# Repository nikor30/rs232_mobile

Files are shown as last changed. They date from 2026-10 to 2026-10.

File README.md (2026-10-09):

# RS232-WLAN-Konsole

Mobiler serieller Konsolenserver auf ESP32-Basis: mit dem WLAN-Hotspot des Geräts verbinden, `http://192.168.4.1` öffnen, Terminal auf Switch, Router oder Firewall. Keine App, kein Treiber, kein USB-Seriell-Adapter.

Firmware-Stand: **v1.8.0**

- [`HANDOVER.md`](HANDOVER.md) — Projektstand, Erfahrungswissen, offene Punkte
- [`firmware/`](firmware/) — PlatformIO-Projekt für das Waveshare ESP32-S3-Touch-LCD-2 ([Weboberfläche und Netz](firmware/README.md), [Board](firmware/WAVESHARE.md))
- [`server/`](server/) — Leitstelle (Command-and-Control-Server): [Konzept](server/KONZEPT.md), Phase 1 lokal im Docker-Container
- [`tests/`](tests/) — Host-Unittests

```bash
cd firmware
pio run -t upload    # waveshare-s3-lcd2
```

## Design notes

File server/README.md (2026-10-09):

# Leitstelle (Command-and-Control-Server)

Server, bei dem sich die RS232-Konsolen anmelden und Aufträge abholen. Idee, Protokoll, Phasen und Grenzen: **[KONZEPT.md](KONZEPT.md)**. Stand: Phase 1 (Server, Gerätesimulator) und Phase 2 (Client in der Firmware), geprüft im Container und mit dem Waveshare-Board im lokalen Netz.

**Nicht ins Internet stellen.** Dafür fehlt Phase 5 (KONZEPT.md §6); die Compose-Datei bindet den Port deshalb nur an `127.0.0.1`, solange `C2_BIND` nichts anderes sagt.

## Starten

```bash
cd server
echo "C2_ADMIN_TOKEN=$(head -c 24 /dev/urandom | base64)" > .env
docker compose up -d --build        # erster Bau auf dem Raspberry Pi: rund 10 Minuten
curl -k https://127.0.0.1:8443/healthz
```

Der Container enthält nur die beiden Programme (`/c2server`, `/devsim`), läuft ohne Root und mit schreibgeschütztem Dateisystem; der Zustand liegt im Volume `c2data`.

## Ein simuliertes Gerät anmelden

```bash
. ./.env; A="Authorization: Bearer $C2_ADMIN_TOKEN"; S=https://127.0.0.1:8443
sim() { docker run --rm --network server_default -v c2dev:/data --entrypoint /devsim rs232-c2 \
          -state /data/device.json -tls-skip-verify "$@"; }

# 1. einladen
curl -sk -X POST $S/admin/v1/enroll-tokens -H "$A" -d '{"ttl_s":600}'     # -> {"token":"c2e1:...",...}
# 2. das Gerät meldet sich an und zeigt seinen Code
sim enroll -name Labor-1 'c2e1:...'                                        # -> ID ... / CODE 123456
# 3. den Code vom Gerät am Server eintippen
curl -sk -X POST $S/admin/v1/devices/<ID>/approve -H "$A" -d '{"sas":"123456"}'
# 4. Auftrag einreihen, Gerät holt ihn ab, Ergebnis ansehen
curl -sk -X POST $S/admin/v1/devices/<ID>/commands -H "$A" -d '{"type":"ping"}'
sim run -n 1
curl -sk $S/admin/v1/devices/<ID>/commands -H "$A"
```

`-tls-skip-verify` gilt dem selbstsignierten Zertifikat des lokalen Servers. Der innere Kanal hängt davon nicht ab: Der Server muss weiterhin den Schlüssel beweisen, dessen Fingerabdruck im Token steht.

## Ein echtes Gerät anmelden

Das Gerät muss den Server erreichen, also an die LAN-Adresse dieses Rechners binden und sie als öffentliche Adresse nennen (in `.env` oder davor):

```bash
C2_BIND=192.168.10.232 C2_PUBLIC_URL=https://192.168.10.232:8443 docker compose up -d
```

Dann wie oben einladen. Das Token kommt in die Weboberfläche des Geräts (Menü → Netz → Leitstelle → Anmelden) oder per `curl -X POST http://<gerät>/api/c2/enroll -d '{"token":"c2e1:..."}'`; der WLAN-Client des Geräts muss verbunden sein. Der Code steht danach auf dem Display (Seite Info) und in der Weboberfläche. Details: `firmware/README.md`.

## Admin-Schnittstelle

Alle Aufrufe mit `Authorization: Bearer <C2_ADMIN_TOKEN>`.

| Aufruf | Wirkung |
|---|---|
| `POST /admin/v1/enroll-tokens` `{"ttl_s":600,"note":""}` | Einladungs-Token, einmal verwendbar |
| `GET /admin/v1/devices` | Geräte mit Zustand (`pending`, `active`, `revoked`), zuletzt gesehen, letzter Status |
| `POST /admin/v1/devices/{id}/approve` `{"sas":"123456"}` | bestätigen mit dem Code vom Gerätedisplay; fünf falsche Eingaben verwerfen die Anmeldung |
| `POST /admin/v1/devices/{id}/revoke` | sperren, sofort und endgültig |
| `POST /admin/v1/devices/{id}/commands` `{"type":"ping","args":{}}` | Auftrag einreihen (Arten: `ping`, `status`) |
| `GET /admin/v1/devices/{id}/commands` | Aufträge mit Zustand und Ergebnis |

## Einstellungen (Umgebung)

| Variable | Vorgabe | Bedeutung |
|---|---|---|
| `C2_ADMIN_TOKEN` | — (Pflicht, mindestens 16 Zeichen) | Token der Admin-Schnittstelle |
| `C2_PUBLIC_URL` | `https://c2server:8443` (Compose) | Adresse, unter der Geräte den Server erreichen; steht im Einladungs-Token |
| `C2_TLS` | `selfsigned` | `selfsigned`, `files` (`C2_TLS_CERT`, `C2_TLS_KEY`) oder `off` (hinter einem Proxy, der TLS beendet) |
| `C2_TLS_HOSTS` | `localhost,127.0.0.1,c2server` | Namen im selbstsignierten Zertifikat |
| `C2_LISTEN` | `:8443` | Adresse und Port im Container |
| `C2_BIND` | `127.0.0.1` | nur Compose: Adresse dieses Rechners, an die der Port gebunden wird |
| `C2_DATA_DIR` | `/data` | Zustand: `state.json` (enthält den privaten Serverschlüssel), TLS-Zertifikat |
| `C2_POLL_S` | `30` | Abstand, in dem Geräte sich melden sollen |

Wer das Datenverzeichnis verliert, verliert den Serverschlüssel — alle Geräte müssten neu angemeldet werden.

## Tests

```bash
./test/e2e.sh                       # alles: Unit-Tests, Image, Ende-zu-Ende im Container
../tests/c2/run.sh                  # der Protokollcode der Firmware auf dem PC gegen diesen Server
docker build --target test .        # nur Formatierung, go vet und Unit-Tests
```

Go muss nicht installiert sein; gebaut und getestet wird im Container.

## Aufbau

```
cmd/c2server/        der Server
cmd/devsim/          Gerätesimulator
internal/proto/      Protokoll: Handshake, Nachrichten, Einladungs-Token  ← Vorlage für die Firmware
internal/device/     Geräteseite über HTTP (Simulator, Tests)
internal/server/     HTTP: Geräte-Endpunkte und Admin-Schnittstelle
internal/store/      Zustand (JSON-Datei)
test/e2e.sh          Ende-zu-Ende-Test gegen den Container
```

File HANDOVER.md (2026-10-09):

# RS232-WLAN-Konsole — Projektstand und Übergabe

**Stand:** 9. Oktober 2026 · Firmware **v1.8.0** · Autor der Arbeiten: Claude, im Auftrag von Niko

Dieses Dokument ist so geschrieben, dass man das Projekt allein damit und mit dem Archiv-Inhalt fortsetzen kann — ohne den Chatverlauf. Es nennt ausdrücklich auch, **was nicht verifiziert ist**.

---

## 1. Worum es geht

Ein mobiles Gerät für seriellen Konsolenzugang: Du verbindest Handy oder Notebook mit dem WLAN-Hotspot des Geräts, öffnest `http://192.168.4.1` und hast ein Terminal (xterm.js) auf dem angeschlossenen Switch, Router oder der Firewall. Keine App, kein Treiber, kein USB-Seriell-Adapter. Bis zu vier serielle Ports gleichzeitig, dazu Raw-TCP/Telnet, Dateiübertragung per XMODEM/YMODEM, abspielbare Konfigurationen, 802.1X fürs Firmennetz und HTTPS.

## 2. Die Hardware

Seit dem 9. Oktober 2026 baut die Firmware nur noch für das **Waveshare ESP32-S3-Touch-LCD-2** (ESP32-S3R8, 2″-Touch-LCD 240×320, SD, LiPo-Anschluss; PlatformIO-Env `waveshare-s3-lcd2`, Arduino-Core 2.0.17). Stand, Pins und offene Punkte: `firmware/WAVESHARE.md`.

Entfernt wurden die drei früheren Varianten samt ihrem Code: **ESP32 DevKit + MAX3232 (HW-044)** mit OLED (das erste Mockup), **LilyGO T-RSS3** und das **VIEWE-5″-Panel** (LVGL-GUI, Core 3.1.1) — dazu OLED-Treiber (U8g2), Status-LED, die fertigen Images, `MOCKUP.md`, `PANEL.md` und das T-RSS3-Gehäuse. Ebenfalls entfernt sind `hardware/` (KiCad-Projekt der I²C-Tochterplatine, Gehäuse fürs LCDwiki-Basisboard) und `diagramme/` (PowerBoost-Schaltpläne, DB9-Nullmodem); deren letzter Stand ist Commit `43e7939`. Der letzte Stand mit allen Varianten ist Commit `3bbc16c`. Wo die Abschnitte unten von diesen Boards handeln, sind sie als Erfahrungswissen stehen geblieben.

## 3. Was läuft, was nicht

**Am echten Gerät erprobt (am früheren DevKit-Mockup; Waveshare: siehe `firmware/WAVESHARE.md`):**
- Web-Terminal, Mehrfach-Clients, Reconnect mit Replay
- Konsolenzugriff auf einen echten Cisco-Switch
- Raw-TCP auf Port 2000 aus dem LAN, mit PuTTY
- OLED 128×64 inkl. Helligkeitsregelung
- PowerBoost 1000C mit LiPo lädt und versorgt

**Nie gegen die Wirklichkeit geprüft:**
- **802.1X EAP-TLS gegen einen echten RADIUS**, PKCS#12-Upload am Gerät.

Mit den alten Boards entfernt, weil nie gelaufen: die **Core-3-/mbedTLS-3-Pfade** (`compat_eap.h`, `compat_mbedtls.h`) und die **LBO-Auswertung** (Akkuwarnleitung fürs DevKit mit PowerBoost). Die Firmware ruft jetzt direkt die APIs von Arduino-Core 2.0.17 / mbedTLS 2 auf; ein Umstieg auf Core 3 braucht die Anpassungen aus Commit `c4b24bb` wieder.

**Nicht gebaut:** die I²C-Tochterplatine. Schaltplan und Layout liegen nur noch in der Git-Historie (Commit `43e7939`), bestellt war nichts.

## 4. Was im Archiv liegt

```
firmware/            das PlatformIO-Projekt
  src/               C++-Quellen
  web/               Weboberfläche (wird gzip-komprimiert ins Image eingebettet)
  tools/             embed_web.py, lcd_debug.py (Debug-Konsole), mock_device.js
  README.md          Weboberfläche, Netz, 802.1X/HTTPS, XMODEM, Konfigurationen, Diagnose
  WAVESHARE.md       das Board: Touch-Oberfläche, Bluetooth, Pins, Akku  ← die meistgebrauchte Datei
tests/               Host-Unittests (laufen auf dem PC, nicht auf dem ESP32)
HANDOVER.md          dieses Dokument
```

## 5. Firmware: wo was steckt

| Datei | Aufgabe |
|---|---|
| `main.cpp` | Setup/Loop, BOOT-Taste, Verteilung der seriellen Daten an alle Senken |
| `config.h` | Pins und Defaults des Boards |
| `settings.h/.cpp` | persistente Einstellungen (NVS), Pin-Plausibilisierung |
| `serial_bridge.h/.cpp` | UARTs, Sendewarteschlangen, Replay-Ringpuffer, Auto-Baud |
| `net.h/.cpp` | WLAN, HTTP, WebSocket, **Raw-TCP/Telnet**, OTA, 802.1X |
| `https.cpp`, `certs.cpp` | TLS-Frontend, Zertifikate, PKCS#12, CSR-Erzeugung |
| `display.h`, `lcd_ui.cpp` | Touch-Oberfläche auf dem 2″-LCD (LovyanGFX) |
| `ble.h/.cpp` | serielle Konsole über Bluetooth LE |
| `sdcard.h/.cpp` | SD-Karte: Mitschnitte |
| `power.h/.cpp`, `bat_curve.h` | Akkumessung, Ladeerkennung, Sparmodus |
| `xfer.cpp` | XMODEM/YMODEM im ESP32 |
| `configs.cpp`, `player.cpp` | gespeicherte Konfigurationen, Abspielen am Gerät |

## 6. Bauen

```bash
pio run -e waveshare-s3-lcd2 -t upload
```

Die `platformio.ini` löst über die PlatformIO-Registry auf (Arduino-Core 2.0.17).

> **Hinweis für eine Fortsetzung in einer Claude-Sandbox:** Dort war `api.registry.platformio.org` und `dl.espressif.com` durch die Egress-Policy gesperrt, GitHub und PyPI dagegen offen. Der Workaround war: Platform, Framework, IDF-Libs und Toolchains direkt von GitHub-Releases ziehen und mit selbstgeschriebenen `.piopm`/`package.json`-Manifesten unter `~/.platformio/packages` ablegen; Debugger- und Dateisystem-Werkzeuge als leere Stubs. Beide Core-Versionen müssen in **versionierten** Verzeichnissen liegen (`framework-arduinoespressif32@3.20017.0` neben dem einfachen Namen für 3.1.1), sonst überschreibt die eine Installation die andere. Bibliotheken gehören dann in `lib/`, weil PlatformIO transitive Abhängigkeiten sonst doch über die Registry auflösen will.

## 7. Was in dieser Arbeitsphase entstand (v1.5.0 → v1.8.0)

| Version | Inhalt |
|---|---|
| 1.6.0 | **OLED-Helligkeit** (Kontrastregister, Live-Vorschau beim Schieben); Telnet-IAC-Filter; `[TCP]`-Logzeilen; Boot-Log sagt ehrlich „TCP aus" statt immer einen Port zu melden |
| 1.6.1 | **Raw-TCP aus dem LAN** als bewusste Option; **Terminal-Modus** in der Weboberfläche (xterm füllt das Fenster, blinkender Cursor nur bei stehender Sitzung) |
| 1.6.2/1.6.3 | Auto-Baud meldet jetzt **warum** nichts kam: „Leitung stumm" vs. „nur unlesbare Zeichen (max. N Byte)" |
| 1.6.4 | Rücknahme: automatischer RX/TX-Tausch im Auto-Baud wieder raus (siehe 8.1) |
| 1.6.5 | **TCP-Sendewarteschlange** — behebt echten Datenverlust (siehe 8.4) |
| 1.7.0 | **VIEWE-Panel**: Board-Profil, LVGL-GUI, SD-Karte, Portierung auf Arduino-Core 3 / mbedTLS 3 |
| 1.7.1 | **LBO-Warnleitung** für Ladeboards |
| 1.8.0 | **Waveshare ESP32-S3-Touch-LCD-2**: Board-Profil, Farb-Touch-Oberfläche, Bluetooth-LE-Konsole, SD, Akkuanzeige mit Ladeerkennung, Sparmodus und Ausschalten; **Akku-Kalibrierung** (0-%-/100-%-Punkt) für alle Boards — Stand und offene Punkte: `firmware/WAVESHARE.md` |
| — | 9. Oktober 2026, ohne Versionssprung: **Aufräumen auf ein Board.** DevKit-Mockup, T-RSS3 und VIEWE-Panel entfernt, ebenso OLED-Treiber, LVGL-GUI und Status-LED; die Einstellungen `oledFlip`/`oledBrightness` heißen in der Web-API jetzt `displayFlip`/`displayBrightness` (NVS-Schlüssel unverändert). Ebenfalls entfernt: Core-3-/mbedTLS-3-Kompatibilität und die LBO-Warnleitung (`batLbo`) |

## 8. Hartes Erfahrungswissen

Das hier hat jeweils Zeit gekostet. Bitte nicht erneut ausprobieren.

### 8.1 Das RX/TX-Häkchen ersetzt kein Nullmodem
Das Häkchen „RX/TX am TTL-Pegelwandler tauschen" vertauscht, welcher **ESP32-GPIO** an `T1IN` bzw. `R1OUT` des MAX3232 geht — also die zwei Jumper zwischen Mikrocontroller und Pegelwandler. Welcher **DB9-Pin** sendet, legt das Modul-Layout fest; daran ändert keine Einstellung etwas. Eine fehlende Kreuzung im Kabel lässt sich damit nicht ausgleichen. (Ich hatte das zwischenzeitlich falsch behauptet und sogar automatisiert — in 1.6.4 zurückgebaut, weil es zusätzlich einen Pin-Konflikt provoziert: ESP32-Ausgang gegen MAX3232-Ausgang.)

### 8.2 Zwei DB9-Buchsen brauchen eine Kreuzung
Das blaue Cisco-Rollover-Kabel endet in einer DB9-**Buchse**, das HW-044 hat auch eine. Ein **straighter** Gender-Changer legt Pin 2 auf 2 und 3 auf 3 — Sendeausgang trifft Sendeausgang, beide Empfänger hängen in der Luft. Loopback-Test (Pin 2/3 gebrückt) läuft dabei einwandfrei, am Switch kommt nichts. Gelöst wurde es durch Kreuzen auf der **RJ45-Seite** (RJ45-Koppler plus passend belegtes LAN-Kabel), weil das Rollover-Kabel RJ45 3 → DB9 2 und RJ45 6 → DB9 3 führt. Merksatz für die Pinzählung: **bei einer Buchse von vorn liegt Pin 1 oben rechts.**

### 8.3 Der Boot-Log darf nicht lügen
Die Zeile pro Port meldete immer `TCP :2000`, auch wenn Raw-TCP abgeschaltet war. Das hat eine Fehlersuche in die falsche Richtung geschickt. Seitdem: Diagnoseausgaben nennen den tatsächlichen Zustand, und jede abgewiesene TCP-Verbindung sagt den Grund. Genau diese Logzeile hat später das LAN-Problem in Sekunden geklärt.

### 8.4 `WiFiClient::write()` verwirft stillschweigend
Im Arduino-Core 2.0.17 blockiert `write()` bei vollem Socket-Puffer bis zu **10 × 1 s** und gibt dann zurück, wie viel untergebracht wurde. Der Rückgabewert wurde ignoriert — der Rest war weg. Bei schwachem WLAN (hier −78 dBm) fehlten dadurch im PuTTY-Fenster Zeilen, die im Web-Terminal vollständig standen. Seit 1.6.5: 4 kB Warteschlange pro Port, `send(..., MSG_DONTWAIT)` über `WiFiClient::fd()`, Überlauf wird gemeldet statt verschwiegen.

### 8.5 Telnet vs. Raw auf demselben Port
Die Firmware unterscheidet am **allerersten Byte**: `0xFF` → Telnet-Client, dann antwortet sie wie ein Terminalserver (`WILL ECHO`, `WILL SUPPRESS-GO-AHEAD`), was das lokale Echo des Clients abschaltet. Alles andere → reiner Raw-Durchgang, kein Byte wird angefasst. In PuTTY entsprechend „Telnet" **oder** „Raw" wählen; beides geht. Achtung, klassische PuTTY-Falle: Beim Umschalten des Verbindungstyps setzt PuTTY das Port-Feld auf den Standard zurück.

### 8.6 Das VIEWE-Panel hat zwei freie GPIOs (Board entfernt)
Nach Abzug von RGB-Panel (≈20 Pins), SD-Karte und Touch bleiben **IO17 und IO18**, dazu das UART-Paar IO43/44 (= USB-Debug-Konsole). Vier native RS232-Ports sind damit ausgeschlossen. Der Touch-I²C auf **IO19/20** ist mitbenutzbar: GT911 liegt auf 0x5D/0x14, die SC16IS752 auf 0x48–0x57, kein Adresskonflikt. Das ist die eigentliche Begründung für die I²C-Tochterplatine.

### 8.7 Lade-/Boost-Board (DevKit-Mockup, entfernt)
PowerBoost 1000C ist **ausdrücklich 1-zellig** (3,7/4,2 V) — ein 7,4-V-Pack zerstört den Laderegler. 5Vo geht auf **VIN**, nie auf 3V3. Eine Schottky (1N5817, Ring zum DevKit) zwischen 5Vo und VIN macht den Aufbau USB-sicher, sodass Flashen mit angeklemmtem Akku geht. `LBO` ist offener Kollektor und braucht keinen externen Widerstand (die Auswertung in der Firmware gibt es nicht mehr). Der Schaltplan (`diagramme/powerboost_schaltplan.png`) liegt nur noch in der Git-Historie.

### 8.8 Tochterplatine: beide Kanäle nutzen (Entwurf entfernt)
Erste Fassung war 4× SC16IS750 + 4× MAX3232 — je ein Chippaar pro Port. Beide Bausteinfamilien sind aber zweikanalig: der SC16IS**752** ist der I²C-fähige Doppel-UART, und der MAX3232 hat ohnehin zwei Transceiver, die sich dieselben vier Ladepumpen-Kondensatoren teilen. Jetzt **2× SC16IS752 + 2× MAX3232** für vier Ports. Halbe Chipzahl, Platine von 112,5 auf **107 × 110 mm**, Materialkosten von geschätzt ~58 € auf **~20 €**. Pinbelegungen wurden gegen KiCads eigene Symbolbibliothek geprüft, nicht aus Datenblatt-PDFs abgetippt — das hatte sich vorher als unzuverlässig erwiesen.

## 9. Wie geprüft wurde

Da kein Zugriff auf die Hardware bestand, wurde das Prüfbare auf dem Host geprüft:

- **`tests/telnet_iac_test.cpp`** — die Telnet-Zustandsmaschine, 1:1 aus `net.cpp` extrahiert: Raw bleibt byte-genau (auch `0xFF` in Nutzdaten), Aushandlung wird korrekt beantwortet, Subnegotiation, `IAC IAC`, Sequenzen über TCP-Paketgrenzen, zweite Sitzung wird neu begrüßt. 12 Fälle, alle grün.
- **`tests/iac_filter_test.cpp`** — die ältere Filterfassung, 8 Fälle über alle Chunk-Größen.
- **Builds** beider Umgebungen mit **0 Warnungen** im eigenen Code.
- **Binärprüfung**: Bootloader und Partitionstabelle der Mockup-Images sind byte-identisch zur vorigen Auslieferung, Flash-Parameter unverändert (dio/4 MB/40 MHz) — OTA ist dadurch gefahrlos, Einstellungen überleben.

## 10. Offene Punkte, nach Priorität

1. **Waveshare-Board fertig prüfen**: MAX3232 anschließen und echter Konsolenzugriff, SD-Karte, Akkubetrieb — die Liste steht in `firmware/WAVESHARE.md` unter „Offen".
2. **802.1X gegen echten RADIUS testen.** Danach PKCS#12-Upload und CSR-Erzeugung durchspielen.
3. **Gehäuse** für das Waveshare-Board — es gibt noch keins.
4. Die Docs-Seite (Artifact `2f26e902-4f1e-4797-bfbc-4037495d8121`) beschreibt noch das LCDwiki-Basisboard und müsste auf das Waveshare-Board umgeschrieben werden.

## 11. Arbeitsweise, die sich bewährt hat

- **Diagnoseausgaben vor Ratespielen.** Die `[TCP]`-Logzeilen haben zwei Probleme in Sekunden geklärt, die vorher Stunden gekostet hätten.
- **Pinbelegungen aus maschinenlesbaren Quellen**, nicht aus Datenblatt-Grafiken.
- **Byte-Logik auf dem Host testen**, bevor sie auf den Mikrocontroller geht.
- **Loopback schließt den Fehler ein, nicht aus.** Dass Test 1 läuft, sagt nur, dass ESP32 → MAX3232 → DB9 stimmt — über das Kabel dahinter sagt es nichts.

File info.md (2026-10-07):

https://spotpear.com/wiki/ESP32-S3R8-2-inch-LCD-Display--ST7789-TouchScreen-Camera.html

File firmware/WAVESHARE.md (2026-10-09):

# Waveshare ESP32-S3-Touch-LCD-2

ESP32-S3R8 (16 MB Flash, 8 MB PSRAM) mit 2″-Farbdisplay 240×320 (ST7789T3), kapazitivem Touch (CST816D), Lagesensor (QMI8658), SD-Slot, LiPo-Anschluss und USB-C am nativen USB-Port.

```bash
pio run -e waveshare-s3-lcd2 -t upload
```

Stand 2. Oktober 2026: gebaut, geflasht und am Board geprüft, soweit unten angegeben. Arduino-Core 2.0.17. Seit dem 9. Oktober 2026 ist dies das einzige Board der Firmware; Weboberfläche und Netzfunktionen beschreibt [README.md](README.md).

## Was das Board zusätzlich kann

| Funktion | Datei | Geprüft |
|---|---|---|
| Farb-Touch-Oberfläche mit sechs Seiten | `src/lcd_ui.cpp` | alle Seiten quer und hoch per Screenshot angesehen, jede Taste per simuliertem Tippen ausgelöst, 4 Minuten Zufallstest (336 Aktionen) ohne Absturz; mit echtem Finger nur die Vorversion |
| Automatisches Drehen über den Lagesensor | `src/lcd_ui.cpp` | am Gerät bestätigt (quer); die beiden Hochformat-Richtungen sind gerechnet |
| Serielle Konsole über Bluetooth LE | `src/ble.cpp` | Kopplung mit PIN, Verschlüsselung und Schreiben vom Raspberry Pi aus; Ein-/Ausschalten mehrfach; Richtung Gerät → Handy ungetestet (kein Loopback verdrahtet) |
| Akkuanzeige mit Ladeerkennung | `src/power.cpp` | Messung an IO5 mit 1000-mAh-LiPo bestätigt (6. Oktober 2026); „lädt" am USB-Port eines Rechners gesehen; Akkubetrieb, Netzteil und Ab-/Anstecken **ungeprüft** — siehe unten |
| Stromsparen im Akkubetrieb, Ausschalten | `src/power.cpp`, `src/lcd_ui.cpp`, `src/main.cpp` | Sparmodus erzwungen (`lcd_debug.py saver 1`): 80 MHz, Abdunkeln nach 15 s, Aufhellen bei Berührung gesehen; Ausschalten und Wecken per Zeitablauf dreimal durchlaufen. **Ungeprüft:** echter Akkubetrieb ohne USB, Wecken mit der BOOT-Taste, Abschalten bei leerem Akku, jede Stromaufnahme (kein Messgerät) — siehe unten |
| Mitschnitt auf SD-Karte | `src/sdcard.cpp` | Karte wird nach dem Einschalten erkannt (CS = IO41), **nach jedem Reset ohne Stromunterbrechung nicht mehr** — offen, siehe unten |

## Bedienung

- **Ziehen nach oben/unten** verschiebt eine Seite, die länger ist als der Bildschirm; der Balken am rechten Rand zeigt, dass es weitergeht und wo man steht. Nichts wird mehr abgeschnitten: lange Werte laufen in die nächste Zeile, Listeneinträge und Titel, die einzeilig bleiben müssen, wandern langsam hin und her.
- **Tasten** sind 46 Pixel hoch (6 mm), Listenzeilen 32. Passen die Beschriftungen einer Tastenreihe nicht nebeneinander (hochkant), stehen sie in zwei Reihen.
- **Wischen** oder die Pfeile oben wechseln die Seite: Status, Terminal, Skripte, WLAN (QR), Web-UI (QR), Bluetooth, System, Info, Setup. Die BOOT-Taste blättert ebenfalls.
- **Status**: Schnittstelle, RX/TX-Zähler, Netz. Tasten: Baudrate weiterschalten, Auto-Baud, BREAK.
- **Terminal**: Live-Ansicht der seriellen Leitung (52×19 Zeichen quer, 39×29 hoch), gespeist aus dem Replay-Puffer. Escape-Sequenzen werden verworfen, nicht ausgewertet. Tasten: Enter, Ctrl-C, BREAK, REC (nur mit SD-Karte).
- **Skripte**: die in der Weboberfläche (Reiter Konfig) gespeicherten Konfigurationen. Antippen wählt aus, erst „Senden an Port N" spielt ab — zeilenweise, mit Warten auf den Prompt, Stopp bei Fehlermeldung, Steuerzeilen `@pause`, `@expect`, `@break`, `@timeout` wie im Browser (`src/player.cpp`). Konfigurationen mit `{{Variablen}}` gehen nur in der Weboberfläche.
- **Bluetooth**: zeigt die sechsstellige PIN und schaltet Bluetooth ein/aus (wird gespeichert).
- **System**: CPU-Last je Kern, RAM, PSRAM als Balken; dazu freier Speicher, größter Block, längste Pause der Hauptschleife, Zeichenzeit, Chip-Temperatur, Laufzeit. Die CPU-Last ist eine Schätzung aus der Leerlaufzeit (Auflösung 1 ms).
- **Info**: Firmware, Hostname, Clients, Raw-TCP, Leitstelle (Zustand oder der Code zum Bestätigen, siehe [README.md](README.md#leitstelle)), Akku, SD-Karte, Lage, Board.
- **Setup**: Helligkeit, Abschaltzeit des Displays, WLAN-Client, ganz unten **Ausschalten** (mit Nachfrage; quer dafür nach oben ziehen). „Netz waehlen" sucht Netze; ein verschlüsseltes Netz öffnet die Bildschirmtastatur (QWERTZ, drei Ebenen), ein offenes fragt nach. Gespeichert wird wie in der Weboberfläche, mit Neustart. 802.1X bleibt der Weboberfläche vorbehalten.
- Das Display dreht sich zur oberen Kante; liegt das Board flach, bleibt die letzte Lage. Bewegung und Berührung wecken das dunkle Display; die erste Berührung weckt nur.
- Helligkeit und Abschaltzeit kommen aus den vorhandenen Display-Einstellungen der Weboberfläche.

## Bluetooth

Nordic UART Service, fest auf Port 1. Der Gerätename ist der Hotspot-Name. Jede Verbindung muss mit der PIN gekoppelt werden, die das Display zeigt (neu bei jedem Start); ohne verschlüsselte, authentifizierte Verbindung geht kein Byte in keine Richtung, und eine ungekoppelte Verbindung wird nach 60 s getrennt. Gekoppelte Geräte bleiben gespeichert.

## Pins

| Zweck | GPIO | Quelle |
|---|---|---|
| LCD SCLK / MOSI / MISO / DC / CS / Backlight | 39 / 38 / 40 / 42 / 45 / 1 | LovyanGFX-Boardkonfiguration, am Gerät bestätigt |
| Touch + Lagesensor I²C SDA / SCL | 48 / 47 | ebenso |
| SD CS (SPI-Leitungen des LCD) | 41 | am Gerät bestätigt (Karte eingebunden) |
| Port 1 RX / TX | 44 / 21 | RX: UART-Pad „RXD“; TX: Stiftleiste Pin 22 (GPIO21). Aus Schaltplan und ESP32-S3-Datenblatt, **am Gerät ungeprüft** — siehe unten |
| Akkumessung (BAT_ADC, Teiler 3:1) | 5 | am Gerät bestätigt: 1,35 V am Pin bei angeschlossenem LiPo; voreingestellt |

Weitere Header-Pins sind noch nicht freigegeben. Die Belegung der Stiftleisten steht im Schaltplan des Herstellers (`ESP32-S3-Touch-LCD-2-SchDoc.pdf`, verlinkt im Wiki aus `info.md`).

### Warum Port 1 nicht auf TXD (IO43) sendet

IO43 ist `U0TXD`. Das ROM des ESP32-S3 schreibt bei jedem Reset seine Startmeldungen auf UART0 (Technical Reference Manual, Kapitel „Chip Boot Control“) — die landeten als Eingabe in der Konsole des angeschlossenen Geräts. Deshalb sendet Port 1 seit dem 6. Oktober 2026 auf **IO21**:

- IO21 steht nicht in der Tabelle der Einschalt-Störimpulse des Datenblatts.
- Der 4,7-kΩ-Pull-up der Kameraschnittstelle (TWI_SDA) hält die Leitung im Reset auf Ruhepegel. Mit eingesteckter Kamera ist der Pin belegt.
- IO44 (RXD) bleibt Empfangspin; er ist beim Start ein Eingang. „RX/TX tauschen“ geht weiterhin (21 ↔ 44).
- IO43 wird in der Weboberfläche nicht mehr angeboten. Eine gespeicherte Belegung mit IO43 fällt beim Start auf die Voreinstellung zurück.

## Akku und Laden

Am MX1.25-Stecker hängt ein 1S-LiPo (hier 1000 mAh); der ETA6096 auf dem Board lädt ihn, sobald USB-C Strom liefert. **Der Laderegler hat keine Statusleitung zum ESP32.** Ob geladen wird, schließt `src/power.cpp` deshalb aus dem, was sich beobachten lässt:

| Beobachtung | Schluss | Grenze |
|---|---|---|
| Der USB-Port empfängt Start-of-Frame-Pakete (Framezähler läuft) | ein Rechner speist das Board → lädt | ein reines Netzteil sendet nichts |
| Spannung springt in 15 s um 40 mV nach oben / unten | Ladegerät an- / abgesteckt | Schwelle geschätzt, nie am Gerät ausgelöst; ein beim Einschalten schon steckendes Netzteil bleibt unbemerkt |
| Spannung ≥ 4,15 V | Laderegler hält die Zelle | — |
| ≥ 4,15 V seit 30 min **oder** über 4,0 V seit 15 min auf 8 mV konstant | voll | Zeiten geschätzt |

Anzeige: Akkusymbol mit Füllstand links im Kopf, grün mit Blitz beim Laden, grün ohne Blitz bei „voll", rot bei schwachem Akku; die Prozentzahl daneben, wo der Titel Platz lässt. Die Zeile „Akku" (Status, Info) nennt Prozent, Millivolt und `laedt`/`voll`. Die Weboberfläche zeigt ⚡ statt 🔋.

`tools/lcd_debug.py bat` nennt die Rohwerte hinter der Anzeige (Pin-Spannung, Teiler, USB-Host, Sprung, Zeiten).

Zu wissen:

- **Die Prozentzahl stammt allein aus der Spannung** und liegt beim Laden zu hoch (die Ladespannung liegt über der Ruhespannung).
- **Die Messung liest vermutlich zu niedrig.** Am USB-Port stand die Spannung minutenlang unbewegt bei 4,05 V — so verhält sich eine volle Zelle an 4,2 V, keine, die noch lädt. Ohne Kalibrierung zeigt ein voller Akku dann etwa 83 % — dafür gibt es die Kalibrierung (nächster Abschnitt). Wer die Spannung selbst richtigstellen will: mit dem Multimeter am Akku nachmessen und `BAT_CAL` in `config.h` setzen (echte Spannung / angezeigte Spannung).
- Ohne Akku liegt am Messpunkt die Ausgangsspannung des Ladereglers; das ist von einem vollen Akku nicht zu unterscheiden.
- Die Messung ist auf diesem Board fest eingeschaltet: ein gespeichertes „keine Messung" wird beim Start durch IO5 ersetzt.

### Prozentanzeige kalibrieren

Die Kennlinie erwartet 4,20 V am vollen und 3,30 V am leeren LiPo. Was Teiler und ADC eines bestimmten Boards in diesen beiden Zuständen melden, lässt sich speichern; die Kennlinie wird dann zwischen die beiden Punkte gespannt (`src/bat_curve.h`), ihre Form bleibt.

- **Weboberfläche:** Menü → Ports → „Akku-Anzeige kalibrieren": „Jetzt ist voll" / „Jetzt ist leer" übernehmen die gerade gemessene Spannung, die beiden Felder nehmen Werte in mV, „Zurücksetzen" stellt die Kennlinie wieder her. Wirkt sofort, ohne Neustart.
- **Touch-Display:** Setup, nach unten ziehen: Zeile „0 / 100 %" mit den geltenden Punkten, „Jetzt voll" / „Jetzt leer" (mit Rückfrage), nach einer Kalibrierung „Kalibrierung loeschen". Werte in mV eingeben geht nur in der Weboberfläche.
- **Debug-Konsole:** `tools/lcd_debug.py batcal full`, `batcal empty`, `batcal 3400 4050` (leer, voll in mV; 0 = Kennlinie), `batcal reset`. `bat` nennt die geltenden Punkte.

Vorgehen: **Voll** setzen, wenn der Akku geladen ist, das Ladegerät abgezogen und eine Minute vergangen — am Ladegerät liegt die Spannung höher als danach im Betrieb, sonst wird die Anzeige nach dem Abziehen nie 100 %. **Leer** lässt sich am Gerät kaum abpassen; den Wert eintragen, bei dem es zuletzt noch lief.

Grenzen: Ein Punkt darf höchstens 0,5 V vom Ende der Kennlinie entfernt liegen, beide mindestens 0,3 V auseinander. Geändert wird **nur die Prozentzahl** — die angezeigte Spannung, die Ladeerkennung (4,15 V) und das Abschalten bei leerem Akku (3,3 V) rechnen weiter mit der gemessenen Spannung. Ein 0-%-Punkt unter 3,3 V wird auf diesem Board also nie erreicht, das Gerät schaltet vorher ab. Ein anderer Akkutyp, Mess-Pin oder Teiler löscht die Kalibrierung.

Stand 7. Oktober 2026: Rechnung als Host-Test (`tests/bat_curve_test.cpp`); am Gerät über die Debug-Konsole gesetzt, zurückgewiesen (unplausibler Wert), nach einem Neustart wiedergefunden und zurückgesetzt; auf dem Touch-Display „Jetzt voll" und „Kalibrierung loeschen" per simuliertem Tap und Screenshot; `/api/batcal` per curl (setzen, Messwert übernehmen, Zurückweisung). **Ungeprüft:** der Block in der Weboberfläche im Browser, „Jetzt leer", und ob die Anzeige mit einem real leergefahrenen Akku stimmt.

## Stromsparen und Ausschalten

Das Board hat **keinen Netzschalter**; der Akku hängt immer am Regler. Was die Firmware tun kann, tut sie von selbst, sobald `Power::saver()` wahr ist — also 10 s nachdem die Ladeerkennung „Akkubetrieb" meldet:

| Maßnahme | Wo | Wirkung |
|---|---|---|
| CPU-Takt 80 statt 240 MHz | `main.cpp: cpuClock()` | Funk, UART und SPI laufen am 80-MHz-Bustakt weiter; nicht mitten in einer Übertragung umgeschaltet. Zurück auf 240 MHz, sobald Strom von außen erkannt wird |
| Hintergrundlicht nach 15 s ohne Berührung auf ein Viertel | `lcd_ui.cpp: uiTask()` | die nächste Berührung macht wieder hell und wird normal ausgeführt; die eingestellte Abschaltzeit gilt weiter |
| Dunkles Display: Touch-Abfrage alle 120 statt 50 ms, Schnappschuss jede Sekunde statt alle 100 ms | `lcd_ui.cpp` | Aufwecken dauert einen Wimpernschlag länger |
| Abschalten bei leerem Akku: unter 3,3 V für 30 s | `power.cpp: empty()` | schützt die Zelle; danach lässt sich das Gerät mit BOOT wieder einschalten, schaltet sich leer aber erneut ab |

Immer, nicht nur am Akku: Bluetooth meldet sich alle 250–400 ms statt alle 30–60 ms.

Grenzen: Ein reines USB-Netzteil erkennt die Ladeerkennung nicht (siehe oben) — das Gerät spart dann auch am Netzteil. HTTPS-Verbindungsaufbau dauert bei 80 MHz länger. Der Hotspot selbst lässt sich nicht sparen, er ist die Funktion des Geräts. Wie viel Milliampere das alles bringt, ist **nicht gemessen**.

**Ausschalten** (Setup → Ausschalten, oder von selbst bei leerem Akku) ist Tiefschlaf: Mitschnitte werden geschlossen, Display, Hintergrundlicht, Lagesensor und Karte schlafen gelegt, Funk aus. Wach bleibt nur die Überwachung der **BOOT-Taste — sie schaltet wieder ein** (RST auch). Der Laderegler arbeitet unabhängig weiter, ein ausgeschaltetes Gerät lädt am USB-Kabel. Die USB-Schnittstelle verschwindet solange am Rechner.

Details, die man kennen sollte:

- IO1 (Hintergrundlicht, aus) und IO41 (SD-CS, hoch) werden für die Schlafzeit festgehalten und beim Start wieder freigegeben. IO45 (LCD-CS) bewusst nicht: Es ist ein Strapping-Pin, der festgehalten bei einem Unterspannungs-Reset die Flash-Spannung auf 1,8 V stellen würde.
- Der Lagesensor wird ganz abgeschaltet und behält im Schlaf seine Versorgung. Beim Start muss deshalb erst sein Oszillator wieder an, sonst liefert er nur `FFFF` (`imuBegin()`).
- Nach dem Einschalten per Taste gilt der noch gehaltene Tastendruck weder als Werksreset noch als „nächste Seite".

## Aufbau der Oberfläche

Die serielle Brücke darf nie auf Pixel warten. Deshalb zwei Tasks:

- **Hauptschleife** (Core 1): besitzt den Zustand der Firmware. Alle 100 ms (bei dunklem Display jede Sekunde) kopiert sie, was die Seiten zeigen, in einen Schnappschuss aus einfachen Daten, füttert das Terminal-Raster und führt die angetippten Befehle aus.
- **UI-Task** (Core 0): besitzt Panel, Touch und Lagesensor. Er zeichnet nur aus dem Schnappschuss in einen Puffer im PSRAM und schickt **nur die 16-Pixel-Streifen, die sich geändert haben**.

Dazwischen liegen ein Mutex für den Schnappschuss, eine Befehlswarteschlange und ein paar Anforderungs-Flags. Kein `String` wird über die Task-Grenze gelesen. LCD und SD-Karte teilen sich die SPI-Leitungen; wer darauf spricht, hält `Display::busLock()`.

Gemessen: Die Hauptschleife pausiert im Betrieb 2–3 ms; die längste Pause ist das BREAK-Signal (300 ms, wie in der Weboberfläche). Ein kompletter Seitenwechsel braucht bei 20 MHz rund 100 ms, eine Statusänderung nur wenige Streifen. Die Werksdemo des Boards arbeitet nach demselben Muster (LVGL mit Teil-Updates in einem eigenen Task).

## Debug-Konsole: das Display ohne Hinsehen prüfen

Über den USB-Seriell-Port nimmt die Firmware Diagnosebefehle an; `tools/lcd_debug.py` bedient sie, ohne das Board zurückzusetzen:

```bash
tools/lcd_debug.py status                  # Laufzeiten beider Tasks, Touch, SD-Verlauf, Bluetooth
tools/lcd_debug.py shot bild.png           # Screenshot dessen, was das Display zeigt
tools/lcd_debug.py screen 1 tap 54 205     # Seite wählen, Berührung simulieren
tools/lcd_debug.py rot 0 shot hoch.png     # Drehung erzwingen (bleibt, bis "rot auto" sie dem Sensor zurückgibt)
tools/lcd_debug.py drag 160 180 160 40     # Finger von A nach B: ziehen (scrollen) oder wischen
tools/lcd_debug.py bat                     # Akku: Rohwerte, worauf "laedt"/"voll" beruht, Sparmodus, CPU-Takt
tools/lcd_debug.py batcal full             # gemessene Spannung = 100 % (empty, reset, oder zwei Werte in mV)
tools/lcd_debug.py c2                      # Leitstelle: Zustand, Code, Dauer des Handshakes, Stack und Heap
tools/lcd_debug.py saver 1                 # Sparmodus wie im Akkubetrieb erzwingen (0 = sperren, -1 = automatisch)
tools/lcd_debug.py poweroff 15             # ausschalten, nach 15 s per Zeitablauf wieder an
```

`poweroff` **ohne Zeit** schaltet wirklich aus — dann hilft nur noch die BOOT-Taste am Gerät. Das Werkzeug sucht den Port selbst (`/dev/serial/by-id/...`), weil das Board nach dem Wiedereinschalten auch als `ttyACM1` auftauchen kann; `LCD_PORT=...` legt ihn fest.

Bleibt die Hauptschleife länger als 3 s stehen, meldet der UI-Task das von sich aus im Log (`[DIAG] Hauptschleife steht seit ...`).

## Erfahrungswissen

- **`Serial.setTxTimeoutMs(0)` blockiert, statt nie zu blockieren.** Die Schreibschleife der USB-Seriell-Klasse (Core 2.0.17) zählt den Wert herunter und läuft bei 0 über. Steckt das Board an einem Rechner, der den Port nicht geöffnet hat, bleibt `setup()` in der ersten längeren Log-Ausgabe hängen: kein Hotspot, kein Bluetooth, eingefrorene Anzeige. Das war sehr wahrscheinlich auch das „Einfrieren nach einigen Berührungen" (jede Berührung schrieb eine Logzeile). Jetzt 5 ms.
- **WLAN-Station plus Bluetooth braucht Modem-Sleep.** Ohne ihn bricht der WLAN-Treiber mit `abort()` ab, sobald die Station startet — auch beim bloßen Netz-Scan aus dem Hotspot-Betrieb.
- **Offene Netze nie mit einem einzigen Tippen verbinden.** Beim Testen ist genau das passiert; seitdem fragt die Oberfläche nach.
- **Vorzeichenlose Zeitvergleiche über Task- oder Funktionsgrenzen sind eine Falle.** `now - lastActivity > timeout` schaltete das Display bei jeder Berührung ab, weil `lastActivity` nach `now` gestempelt wurde und die Differenz überlief. Immer `(int32_t)(now - x)` vergleichen.
- **Der CST816 antwortet nicht auf jede Abfrage**, auch wenn der Finger aufliegt. Ohne Haltezeit (120 ms) zerfällt eine Berührung in mehrere Taps.
- **`SD.usedBytes()` läuft die ganze Belegungstabelle ab** — Sekunden. Nie pro Bild aufrufen; die Werte werden beim Einbinden und nach einem Mitschnitt gemerkt.
- **Die USB-Seriell-Klasse dieses Cores verwirft Daten**, sobald sie den Host für abwesend hält. Für den Screenshot geht die Ausgabe deshalb direkt in den USB-FIFO.
- **DTR/RTS setzen das Board zurück oder schicken es in den Bootloader.** Port ganz normal öffnen und `HUPCL` abschalten, damit der Kernel die Leitungen beim Schließen nicht fallen lässt (`lcd_debug.py` macht das).
- **Der QMI8658 liefert im Nur-Beschleunigungs-Modus eingefrorene Werte.** Erst nach Soft-Reset und mit eingeschaltetem Gyroskop (CTRL7 = 0x03) laufen die Daten. CTRL1 = 0x60 schaltet zusätzlich auf Big-Endian — hier 0x40.
- **LovyanGFX bringt eine fertige Konfiguration für genau dieses Board mit** (`lgfx_user/LGFX_ESP32_S3_Touch_LCD_2.h`): keine Reset- und keine Touch-Interrupt-Leitung, Panel liest über MOSI (`spi_3wire`). Abweichend hier SPI2 statt SPI3, weil LovyanGFX nur diesen Bus mit Arduinos `SPI`-Objekt und damit mit der SD-Bibliothek teilt.
- **Die Reihenfolge beim BLE-Advertising zählt.** Erst `enableScanResponse(true)`, dann Name setzen — sonst passt der Name nicht neben die 128-Bit-UUID.
- **`onAuthenticationComplete` kommt bei einem bereits gekoppelten Gerät nicht verlässlich.** Der Sicherheitszustand wird deshalb in `loop()` von der Verbindung gelesen.
- **Ein per I²C abgeschalteter Sensor überlebt den Reset des Prozessors.** Er hängt an 3V3, nicht am Reset. Alles, was vor dem Tiefschlaf abgeschaltet wird, muss der Start ausdrücklich wieder einschalten.
- **`rot N` wurde vom Lagesensor nach 0,6 s überstimmt**, sobald das Board nicht flach lag — die Screenshots zeigten dann immer dieselbe Lage. Eine erzwungene Drehung bleibt jetzt bis `rot auto`.
- **Erster Build auf dem Raspberry Pi dauert lange** (2,4 GB Pakete auf die SD-Karte). PlatformIO liegt in `/root/.local/share/pio-venv`.

## Das SD-Karten-Problem (offen)

Beobachtet mit einer 1-GB-SDSC-Karte:

- Nach dem **Einschalten** wird die Karte eingebunden.
- Nach einem **Reset ohne Stromunterbrechung** antwortet sie nicht mehr. Auf der Datenleitung liegt dann bei jedem Takt ein festes Muster (ein Null-Bit alle vier Takte), unabhängig von Chip-Select, Taktfrequenz und jedem Kommando (CMD0, CMD12, Stop-Token). 4096 Byte am Stück sind identisch — das sind keine Daten, die Karte hängt.
- Per Messung ausgeschlossen: der ESP32 selbst (IO40 ist kein Ausgang), das LCD (Software-Reset ändert nichts, es liest ohnehin über MOSI), ein unterbrochener Lesevorgang.
- Nur Strom weg holt die Karte zurück.

Beide naheliegenden Erklärungen sind inzwischen widerlegt:

1. *Der LCD-Takt von 40 MHz ist zu schnell für die Karte.* Mit 20 MHz fiel sie genauso aus.
2. *Der Reset bringt sie aus dem Tritt.* Sie fiel auch im laufenden Betrieb aus, ohne jeden Reset: eingeschaltet, eingebunden, nach spätestens 254 s tot (`K+ !254s` im Verlauf).

Was bleibt: Diese Karte verträgt den Datenverkehr des Displays auf den gemeinsamen Leitungen nicht, obwohl ihr Chip-Select dabei inaktiv ist. Ob das an dieser einen (alten) Karte liegt oder am Aufbau, ist offen — **als Nächstes eine andere Karte probieren (SDHC, 8–32 GB)**.

Die Firmware führt Buch (`[DIAG] SD: ... Verlauf:` in `lcd_debug.py status`, im Flash gespeichert): `K+`/`K-xx` Start nach Einschalten, `R+`/`R-xx` Start nach Reset (xx = Antwort der Karte), `!<n>s` Karte fiel nach n Sekunden Betrieb aus (geprüft wird alle 20 s mit einem Sektor-Lesen).

Weitere Regeln, die dabei entstanden sind: Die Karte wird **vor** dem LCD gestartet (`Display::begin()` ruft `Sd::begin()`), und eine nach dem Start eingesteckte Karte lässt sich auf der Info-Seite einbinden.

## Offen

1. SD-Karte: mit einer anderen Karte gegenprüfen (siehe oben).
2. Der Fix für das Blockieren ohne USB-Leser ist aus dem Code der USB-Klasse hergeleitet und im Betrieb ohne geöffneten Port geprüft, aber nicht mit einem echten Aus- und Einstecken.
3. WLAN-Beitritt: Suchen, Tastatur, Nachfrage, Speichern und Wieder-Ausschalten sind geprüft; ein erfolgreicher Verbindungsaufbau mit einem echten Schlüssel nicht.
4. Skripte: Ablauf geprüft, aber ohne angeschlossenes Gerät (jede Zeile wartet dann 2 s auf eine Antwort).
5. Bluetooth Richtung Gerät → Handy mit Loopback (TXD–RXD gebrückt) und mit einer Handy-App prüfen.
6. MAX3232 anschließen (Modul-TXD an IO21, Modul-RXD an IO44), echter Konsolenzugriff. Dabei prüfen, dass beim Reset nichts auf IO21 erscheint.
7. Akku: Spannung mit dem Multimeter gegenmessen (`BAT_CAL`); Ladeerkennung im Akkubetrieb, am Netzteil und beim Ab-/Anstecken prüfen. Davon hängt der Sparmodus ab.
11. Stromsparen: USB abziehen und prüfen, dass nach 10 s `[PWR] CPU-Takt 80 MHz` kommt (über die Weboberfläche oder nach dem Wiederanstecken im Log) und das Display abdunkelt; Stromaufnahme an, dunkel und ausgeschaltet messen.
12. Ausschalten am Display (Setup → Ausschalten → Ja) und Einschalten mit der BOOT-Taste von Hand prüfen; ebenso das Scrollen und die größeren Tasten mit echtem Finger.
13. Bluetooth mit dem längeren Meldeintervall vom Handy aus suchen.
8. SD-Mitschnitte sind nur am Display bedienbar, nicht in der Weboberfläche.
10. Baudraten-Wechsel am Display gelten bis zum Neustart (wie bei der BOOT-Taste), sie werden nicht gespeichert.

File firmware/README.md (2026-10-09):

# RS232 Web Console

Mobiler serieller Konsolenzugang per WLAN auf dem **Waveshare ESP32-S3-Touch-LCD-2**: ESP32-S3 mit 2″-Touch-Display, Akkuanschluss, SD-Slot und Web-Terminal im Browser. Du verbindest dein Handy oder Notebook mit dem Hotspot des Geräts und öffnest `http://192.168.4.1`. Eine App ist nicht nötig.

Alles zum Board selbst — Touch-Oberfläche, Bluetooth, Pins, Akku, Stromsparen, Debug-Konsole, offene Punkte — steht in **[WAVESHARE.md](WAVESHARE.md)**. Dieses Dokument beschreibt die Weboberfläche und die Netzfunktionen.

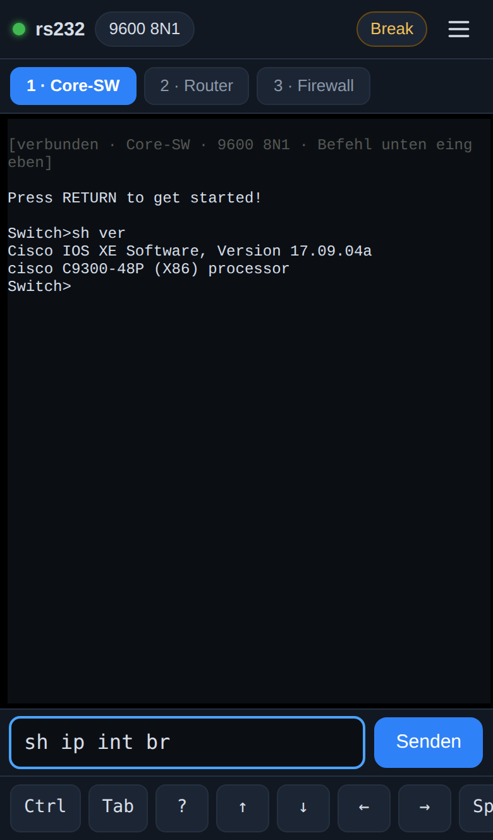
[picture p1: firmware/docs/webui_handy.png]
Web-UI auf dem Handy


## Funktionen

- **Web-Terminal** (xterm.js, offline im Flash eingebettet) mit **Eingabezeile + Senden** und Befehlsverlauf (↑/↓), dazu eine Sondertasten-Leiste fürs Handy: Ctrl (einrastend), Tab, `?`, Pfeiltasten, Space, `q`, ^C, ^Z, Ctrl-Shift-6, Esc
- **Break senden** (250/500/1000 ms) für ROMmon/Passwort-Recovery. In der Kopfzeile musst du zweimal tippen, damit nichts versehentlich ausgelöst wird.
- **Auto-Baud**: probiert 9600, 115200, 19200, 38400 und 57600 mit einem Enter durch.
- **Mitschnitt**: die komplette Sitzung (bis 8 MB) als `.log` speichern, auf Wunsch bereinigt (ohne `--More--`, Backspaces und ANSI-Codes).
- **Bis zu 4 serielle Ports** mit je eigenem Terminal-Reiter, Namen, Einstellungen, Mitschnitt und Raw-TCP-Port (2000–2003). Die GPIOs weist du im Web-UI zu (Menü → Ports). Am Waveshare-Board sind bisher nur IO44/IO21 freigegeben, praktisch also ein Port.
- **Dateien senden per XMODEM, XMODEM-1K und YMODEM** (ROMmon-Recovery, U-Boot `loadx`/`loady`). Das Protokoll läuft im ESP32, der Browser streamt nur die Datei.
- **Konfigurationen** auf dem Gerät speichern und per Klick abspielen: wartet auf den Prompt, fragt `{{Platzhalter}}` ab, `@expect`/`@pause`/`@break`, stoppt bei `% Invalid input`.
- **Wiederverbinden ohne Datenverlust**: Das Gerät puffert die letzten 16 kB. Nach einem WLAN-Abbruch bekommt der Browser genau die verpassten Bytes nachgeliefert.
- **Mehrere Clients** gleichzeitig (bis 5 Browser). Dazu **Raw-TCP** (Port 1 = 2000, Port 2 = 2001 …) für PuTTY („Raw“), SecureCRT oder `nc`.
- **Touch-Display** mit Status, Terminal, WLAN-QR (Handy-Kamera → automatisch verbinden), URL-QR und Einstellungen; dazu eine **Bluetooth-LE-Konsole** — siehe [WAVESHARE.md](WAVESHARE.md)
- **Akkuanzeige** in Prozent und mV auf dem Display und im Web, mit Ladeerkennung und Kalibrierung.
- **Firmennetz (802.1X):** WLAN-Client mit **WPA2/WPA3-Enterprise** – EAP-TLS mit Zertifikat (`.p12`/`.pfx`, `.pem`, `.p7b`), PEAP-MSCHAPv2 oder EAP-TTLS. Zertifikate lädst du im Web-UI hoch, Schlüsselpaar und Zertifikatsantrag (CSR) kann das Gerät auch selbst erzeugen.
- **HTTPS für die Web-Oberfläche** (Port 443, TLS 1.2) mit eigenem Zertifikat – wahlweise dem 802.1X-Zertifikat – oder einem, das sich das Gerät selbst ausstellt. Im Firmennetz lässt sich HTTP auf HTTPS umleiten.
- **Hotspot mit Captive Portal:** Das Handy öffnet die Konsole nach dem Verbinden automatisch. Der Hotspot wählt beim Start den freiesten Kanal (1/6/11), Kanal und Sendeleistung sind im Setup einstellbar. Optional zusätzlich WLAN-Client (z. B. Labor-WLAN), mDNS `http://rs232.local`, Diagnose unter `/ping`
- **Leitstelle:** Das Gerät meldet sich auf Wunsch bei einem Server im Netz, der es verwaltet und ihm Aufträge geben kann — über HTTPS, darin ein eigener Kanal mit Post-Quanten-Schlüsseltausch (ML-KEM-768). Siehe [Leitstelle](#leitstelle).
- **Firmware-Update per Browser** (OTA)

## Teststand

Die Tests der Weboberfläche und der Netzfunktionen stammen aus der Zeit vor dem Waveshare-Board; sie prüfen Code, der unverändert weiterläuft.

| Bereich | Stand |
|---|---|
| Web-UI | 35 automatisierte Tests im Headless-Chromium (iPhone-Profil) gegen den Geräte-Simulator (`tools/mock_device.js`), keine JS-Fehler |
| Firmware am PC | Der echte C++-Code (WebServer, WebSockets, Captive-DNS, Replay, 4 Ports, XMODEM/YMODEM, Konfig-Speicher) läuft am PC gegen nachgebildetes WLAN und serielle Leitungen mit echter Baudrate. Getestet mit Chromium (iPhone-Profil) und **WebKit, der Engine von Safari** |
| XMODEM/YMODEM | Übertragungen in die echten Linux-Empfänger `rx` und `rb` (lrzsz): XMODEM-1K, XMODEM mit Prüfsumme, YMODEM mit Name und exakter Größe, eingestreute CRC-Fehler, verirrte NAKs während eines Blocks, Empfänger ohne 1K-Blöcke, Abbruch durch Empfänger und Benutzer, WLAN-Abriss mit Fortsetzung. Dateien bitgenau verglichen |
| Captive Portal | DNS-Antwortlogik am PC mit echten DNS-Paketen getestet (A, AAAA, HTTPS-Typ, EDNS) |
| Zertifikate | 68 Tests gegen mit OpenSSL erzeugte Dateien: PKCS#12 mit AES-256 und mit 3DES/RC2 (alte Windows-Exporte), ohne Passwort, ohne MAC, mit Umlaut-Passwort, PEM/DER/PKCS#7, verschlüsselte Schlüssel (PKCS#8 mit AES/3DES, klassisch mit AES/3DES), falsche Passwörter, nicht passende Schlüssel, Ed25519, CSR auf dem Gerät (Signatur mit OpenSSL geprüft, von einer Test-CA signiert und wieder eingespielt) |
| 802.1X / HTTPS | am PC: Zertifikats-Upload über die Web-Oberfläche, an den Supplicant übergebene PEM-Puffer, HTTPS-Seite und Terminal über `wss://` in Chromium **und WebKit (Safari-Engine)**, Prüfung der Kette gegen die Geräte-CA, HTTPS-Zwang im LAN, Lasttest (40 Anfragen nacheinander, 6 parallel, 58 kB über eine TLS-Sitzung, kein Leerlauf-Spin). **Anmeldung an einem echten RADIUS-Server steht noch aus** |
| **Echte Hardware** | siehe [WAVESHARE.md](WAVESHARE.md). Der serielle Port ist am Waveshare-Board noch ohne MAX3232, ein Konsolenzugriff auf ein echtes Gerät steht dort aus |

## Firmware flashen

```bash
pio run -t upload            # Umgebung waveshare-s3-lcd2, Arduino-ESP32 2.0.17
```

Board per USB-C anschließen. Libraries und Toolchain lädt PlatformIO selbst; die Web-UI wird beim Build aus `web/` nach `src/web_assets.h` gepackt. Falls der Upload nicht startet: **BOOT** halten, **RST** kurz drücken, BOOT loslassen, dann erneut. Der serielle Monitor (115200) zeigt beim Start SSID, Passwort und URL.

Spätere Updates gehen ohne Kabel: Web-UI → Menü → **Setup** → Firmware-Update → `.pio/build/waveshare-s3-lcd2/firmware.bin` hochladen. Einstellungen und Passwort bleiben dabei erhalten.

## Erste Inbetriebnahme

1. Einschalten. Das Gerät erzeugt einen Hotspot **`RS232-XXXX`**; das Passwort ist ab Werk `rs232mockup` (`FIXED_AP_PASS` in `src/config.h`) und lässt sich im Setup ändern.
2. Auf dem Display zur Seite **WLAN** wischen und den QR-Code mit der Handy-Kamera scannen.
3. Nächste Seite: **Web-UI-QR** scannen oder `http://192.168.4.1` öffnen.
4. Android fragt eventuell „Internet nicht verfügbar“ → **Verbindung beibehalten**. iOS bleibt trotz „Kein Internet“ verbunden.

## Bedienung

Die Bedienung am Gerät (Touch-Display, BOOT-Taste) beschreibt [WAVESHARE.md](WAVESHARE.md#bedienung).

**Web-UI**
- **Eingabezeile** unten: Befehl tippen, **Senden** oder Enter. Die Zeile geht mit CR raus (umstellbar unter Seriell). ↑/↓ = Verlauf, **Tab** und **?** schicken den getippten Text plus Taste (Befehlsergänzung/Hilfe am Switch).
- Direkt ins Terminal tippen geht auch: Jede Taste geht sofort raus, gut für Passwörter und `--More--`. Die Leiste unten liefert Tab, `?`, Pfeile usw. **Ctrl** rastet für eine Taste ein (Ctrl → `z` = ^Z). **⌨** blendet die Tastatur ein oder aus.
- Oben: Verbindungspunkt · Baud-Chip des aktiven Ports (öffnet die seriellen Einstellungen) · Akku (nur mit Messung) · **Break** (2× tippen) · Menü. Darunter bei mehreren Ports ein Reiter pro Port.
- Menü: **Seriell** (Baud, Format, Auto-Baud, Break-Dauer des aktiven Ports) · **Sitzung** (Log, Schriftgröße, Datei senden per XMODEM/YMODEM) · **Konfig** (gespeicherte Konfigurationen abspielen) · **Ports** (Pins, Namen, Akku-Messung) · **Gerät** (Status) · **Setup** (WLAN, Passwort, Display, Firmware-Update, Werksreset)
- Tipp: Im Querformat passen auf dem Handy 80+ Spalten.

**Notebook:** Die Web-UI funktioniert genauso im Browser. Alternativ gibt es Raw-TCP: `nc 192.168.4.1 2000` oder PuTTY mit Verbindungstyp **Raw**, Port 2000 (Port 2 = 2001 usw.). Break geht nur über die Web-UI.

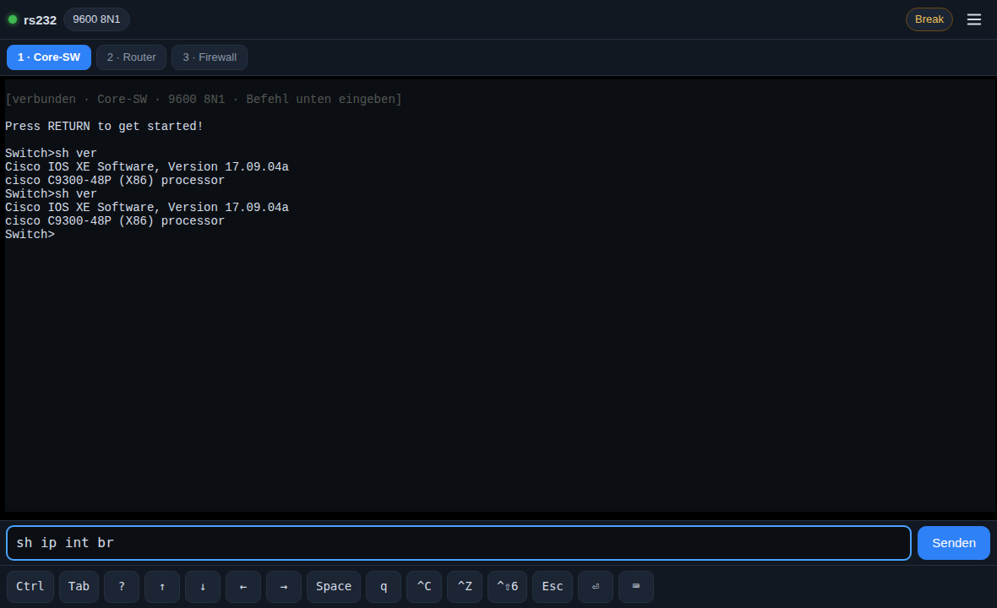
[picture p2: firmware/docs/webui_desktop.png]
Web-UI am Notebook


## Einstellungen & Sicherheit

- **Hotspot:** WPA2. Das Passwort ist ab Werk fest (`FIXED_AP_PASS`); ohne diese Vorgabe erzeugt die Firmware ein zufälliges 10-Zeichen-Passwort. Es steht auf dem Display (Seite WLAN), du kannst es im Setup ändern.
- **Zusätzlich ins WLAN einbuchen:** Netz → SSID/Sicherheit. Das Gerät ist dann auch über die LAN-IP erreichbar (steht auf dem Display), der Hotspot bleibt aktiv. Der Hotspot wechselt dabei auf den Kanal des WLANs, Handys verbinden sich kurz neu.
- **Web-Passwort** (Benutzer `admin`): Ist im LAN-Betrieb dringend zu empfehlen. Es schützt Web-UI, Terminal (Session-Token), Einstellungen und OTA.
- **Raw-TCP** hat keine Authentifizierung. Solange das Gerät im LAN hängt, nimmt es TCP-Verbindungen deshalb **nur von Hotspot-Clients** an. Abschaltbar im Setup.
- HTTP im Hotspot ist unverschlüsselt, den Schutz übernimmt die WLAN-Verschlüsselung. Im Firmennetz kannst du HTTPS erzwingen (siehe unten).

## Firmennetz: 802.1X und HTTPS

Alles dazu steht im Web-UI unter **Menü → Netz**.

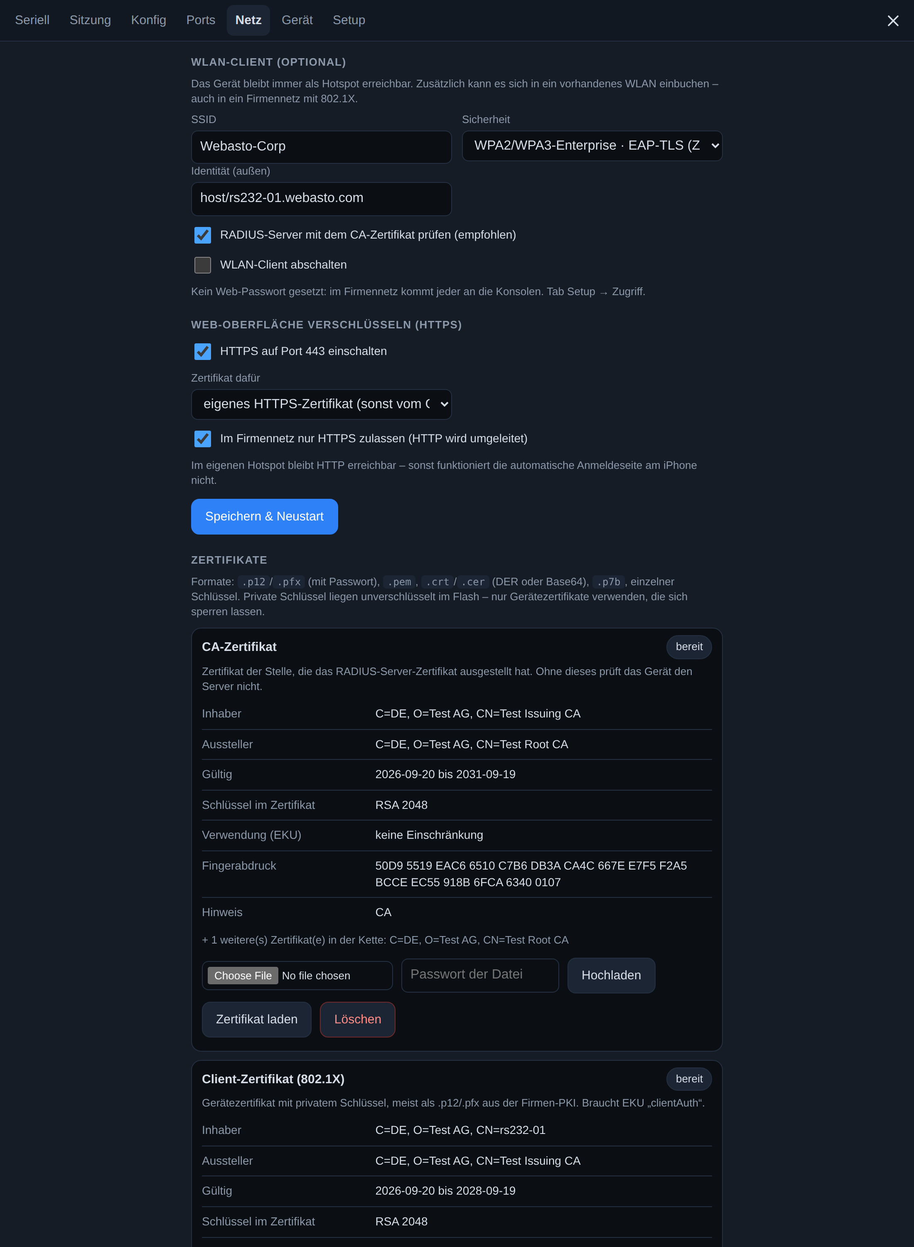
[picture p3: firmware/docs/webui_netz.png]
Tab „Netz“: 802.1X, Zertifikate, HTTPS


### WLAN-Client mit 802.1X

| Verfahren | Was das Gerät braucht |
|---|---|
| WPA2/WPA3-Personal | SSID + Passwort |
| **EAP-TLS** (zertifikatsbasiert) | Client-Zertifikat **mit privatem Schlüssel** (Slot „Client“), dazu das CA-Zertifikat des RADIUS-Servers |
| PEAP-MSCHAPv2 | Benutzer + Passwort, CA-Zertifikat empfohlen |
| EAP-TTLS (MSCHAPv2 oder PAP) | Benutzer + Passwort, CA-Zertifikat empfohlen |

- **Identität (außen)**: Wenn leer, nimmt das Gerät bei EAP-TLS den CN aus dem Zertifikat, sonst den Benutzernamen.
- **RADIUS-Server prüfen**: Mit hinterlegtem CA-Zertifikat prüft das Gerät die Zertifikatskette des Servers. Einen Abgleich des Servernamens (Domain-Match) kann das ESP32-SDK 4.4 nicht, die Kette wird also gegen die CA geprüft, nicht gegen einen konkreten Servernamen.
- **WPA3-Enterprise**: WPA2/WPA3-Transition-Netze funktionieren (PMF wird unterstützt). Der **192-Bit-Modus (Suite B)** ist in diesem SDK nicht aktiviert, ein Netz, das ausschließlich Suite B erlaubt, geht damit nicht.
- Nach dem Hochladen eines neuen Zertifikats meldet sich das WLAN erst nach einem **Neustart** damit an (das Web-UI weist darauf hin).
- Fehlersuche: Menü → Gerät zeigt den Abmeldegrund, z. B. „Grund 23: 802.1X abgelehnt (Zertifikat/Identität prüfen)“.

### Zertifikate hochladen

Akzeptierte Formate: **PKCS#12** (`.p12`, `.pfx` – auch die alten Windows-Exporte mit 3DES/RC2 und die neuen mit AES), **PEM** (Zertifikat, Schlüssel, Kette), **DER** (`.crt`, `.cer`), **PKCS#7** (`.p7b`, die „Zertifikatskette“ der Microsoft-CA) und einzelne Schlüssel (auch verschlüsselt, PKCS#8 oder klassisch mit `Proc-Type: ENCRYPTED`).

- Zertifikat und Schlüssel dürfen getrennt hochgeladen werden, das Gerät ordnet sie über den öffentlichen Schlüssel zu.
- Zwischenzertifikate aus der Datei werden mitgespeichert und mitgeschickt.
- Die Karten im Web-UI zeigen Inhaber, Aussteller, Laufzeit, Schlüsseltyp, Verwendungszweck (EKU), alternative Namen (SAN) und den SHA-256-Fingerabdruck.

### Schlüssel auf dem Gerät erzeugen (CSR)

Netz → „Antrag erzeugen“: Das Gerät erzeugt ein Schlüsselpaar (RSA 2048 oder ECDSA P-256) und einen CSR mit SAN und den Verwendungszwecken *clientAuth* und *serverAuth*. Der private Schlüssel verlässt das Gerät nie. Den Antrag von der Firmen-CA signieren lassen und das Zertifikat hochladen – der passende Schlüssel wird automatisch zugeordnet. Bei einer Microsoft-CA muss die Vorlage „Antragsteller liefert SAN“ erlauben, sonst setzt die CA eigene Namen.

### HTTPS für die Web-Oberfläche

- **Zertifikat**: entweder ein eigenes (Slot „HTTPS“), oder das 802.1X-Client-Zertifikat mitbenutzen – das geht nur, wenn es *serverAuth* im EKU hat und der aufgerufene Name im SAN steht (die Microsoft-Vorlage „Computer“ erfüllt beides). Liegt nichts vor, stellt sich das Gerät **selbst eine kleine CA und ein Zertifikat** aus (Namen `rs232`, `rs232.local`, `192.168.4.1` und die aktuelle LAN-IP, Laufzeit unter 825 Tagen wie von Apple verlangt).
- **iPhone/iPad**: Für die selbst ausgestellte Variante die **Geräte-CA** herunterladen (Netz → Geräte-CA), als Profil installieren und unter *Einstellungen → Allgemein → Info → Zertifikatsvertrauenseinstellungen* aktivieren. Ohne das vertraut Safari dem Gerät nicht, und die Terminal-Verbindung (WebSocket über TLS) kommt nicht zustande.
- **Im Firmennetz nur HTTPS**: HTTP-Aufrufe aus dem LAN werden auf HTTPS umgeleitet, unverschlüsselte Terminal-Verbindungen aus dem LAN werden abgelehnt. Im Hotspot bleibt HTTP erreichbar, sonst funktioniert die automatische Anmeldeseite am iPhone nicht.
- Technisch: eigener TLS-Frontend-Task (mbedTLS, TLS 1.2, max. 3 gleichzeitige Sitzungen, ~35 kB RAM je Sitzung, Sitzungs-Cache für schnelle Wiederverbindungen).

### Grenzen, die man kennen sollte

- Die **privaten Schlüssel liegen unverschlüsselt im Flash** (ohne Flash-Encryption). Wer das Gerät in die Hand bekommt, kann sie auslesen. Also ein eigenes Gerätezertifikat verwenden, das sich sperren lässt – kein Benutzerzertifikat.
- Ohne Web-Passwort kommt im Firmennetz jeder an die Konsolen. Erst Passwort setzen, dann ins LAN.
- Der Werksreset (Web-UI → Setup) löscht Zertifikate **und** Schlüssel.
- Der ESP32 hat 16 Netzwerk-Sockets. HTTPS belegt je Sitzung zwei davon – wer HTTPS zusammen mit vier Raw-TCP-Ports und mehreren Browsern nutzt, sollte Raw-TCP abschalten.

## Leitstelle

Der Server dazu liegt in [`../server/`](../server/), Idee und Protokoll in [`../server/KONZEPT.md`](../server/KONZEPT.md). Am Gerät:

1. **WLAN-Client verbinden** (Menü → Netz). Die Leitstelle wird nur darüber erreicht, nicht über den Hotspot.
2. Der Administrator erzeugt am Server ein **Einladungs-Token** (`c2e1:…`, einmal verwendbar, läuft nach zehn Minuten ab).
3. **Menü → Netz → Leitstelle:** Token einfügen, **Anmelden**. Das Gerät prüft, dass der Server den Schlüssel hat, den das Token nennt, und erzeugt beim ersten Mal seinen eigenen Schlüssel.
4. Das Gerät zeigt einen **sechsstelligen Code** — in der Weboberfläche und auf dem Display (Seite Info, Zeile „Leitstelle"). Der Administrator tippt ihn am Server ein. Erst danach ist das Gerät „verbunden" und bekommt Aufträge.

Danach meldet sich das Gerät von selbst alle 30 s (der Server gibt den Abstand vor) und nach jedem Neustart wieder. **Abmelden** löscht Server und Geräteschlüssel; für eine neue Anmeldung braucht es ein neues Token. Sperrt der Server das Gerät, steht dort „abgewiesen".

Was das Gerät für den Server tut, steht auf einer festen Liste in `src/c2.cpp`: bisher `ping` und `status` (Firmware, Laufzeit, freier Speicher, WLAN-Pegel, Akku, IP). Alles andere lehnt es ab, was immer der Server schickt.

Zu wissen:

- Die Verbindung braucht Pakete voller Größe; an einem sehr schwachen WLAN (am Testplatz: um −80 dBm) scheitert die Anmeldung zeitweise mit „Server nicht erreichbar". Dann die Sendeleistung im Setup erhöhen oder näher an den Zugangspunkt.
- Das TLS-Zertifikat des Servers wird nicht geprüft; der Server beweist sich im Kanal darin mit dem Schlüssel aus dem Token.
- Der Geräteschlüssel liegt unverschlüsselt im Flash. Ein verlorenes Gerät am Server sperren.
- Diagnose: `tools/lcd_debug.py c2` (Zustand, Code, Dauer des letzten Handshakes, Stack und Heap) und die Zeilen `[C2]` im USB-Log.
- Stand der Prüfung: `../server/KONZEPT.md` §7. Der Block in der Weboberfläche ist im Browser noch nicht angesehen worden.

## Dateien per XMODEM / YMODEM senden

Für ROMmon-Recovery, IOS-Images oder U-Boot: **Menü → Sitzung → Datei senden**.

1. Am Gerät den Empfang starten, z. B. Cisco ROMmon `xmodem -c flash:image.bin`, IOS `copy xmodem: flash:`, U-Boot `loadx` / `loady`.
2. Datei wählen, Protokoll wählen, **Senden**. Die Reihenfolge ist egal: Das Gerät wartet bis zu 2 Minuten auf den Empfänger (Zeichen „C“ bzw. NAK).
3. Unten zeigt ein Balken Fortschritt, Tempo und Wiederholungen. **Abbrechen** sendet CAN an den Empfänger.

| Protokoll | Blöcke | wann |
|---|---|---|
| XMODEM-1K | 1024 Byte, CRC | Standard. Kann der Empfänger keine 1K-Blöcke, schaltet die Firmware selbst auf 128 Byte um |
| XMODEM | 128 Byte, CRC oder Prüfsumme | alte Geräte |
| YMODEM | 1024 Byte + Dateiname und Größe | U-Boot `loady`, Geräte die den Namen wollen |

Das Protokoll läuft im ESP32, der Browser liefert nur die Daten nach. WLAN-Aussetzer bremsen den Ablauf deshalb nicht, und reißt die Verbindung kurz ab, macht die Seite nach dem Wiederverbinden weiter. Das Display dabei anlassen. Tempo: bei 115200 Baud etwa 10 kB/s, bei 9600 Baud knapp 1 kB/s (für große Images vorher im ROMmon die Baudrate hochsetzen, z. B. `xmodem -c -s 115200 …`, und dann im Web-UI ebenfalls 115200 einstellen).

## Konfigurationen abspielen (Provisionierung)

**Menü → Konfig**: Konfigurationen auf dem Gerät speichern und per Klick auf den aktiven Port abspielen. Eine Konfiguration darf bis 32 kB groß sein. Der Werksreset löscht sie nicht.

```
@expect initial configuration dialog
no
@expect Switch>
enable
configure terminal
hostname {{HOSTNAME}}
interface GigabitEthernet1/0/48
 description {{UPLINK}}
end
write memory
```

- Jede Zeile geht mit Enter raus. Im Modus **„auf Prompt warten“** wartet die Seite nach jeder Zeile, bis das Gerät wieder einen Prompt zeigt (`#`, `>`, `:` …). `--More--` wird automatisch weitergeblättert. Alternativ **feste Pause** pro Zeile.
- `{{NAME}}` sind Platzhalter: Vor dem Start fragt ein Dialog die Werte ab und merkt sich die letzten Eingaben.
- Steuerzeilen: `@expect Text` wartet auf eine Ausgabe (Groß/klein egal), `@pause 5` wartet 5 s, `@break` sendet BREAK, `@timeout 120` setzt die Wartezeit für die folgenden Zeilen (Standard 30 s).
- **Bei Fehlermeldung anhalten** (Standard an): Bei `% Invalid input`, `% Incomplete command`, `Command fail` usw. stoppt die Wiedergabe und nennt die Zeile.
- „Datei laden“ übernimmt eine Textdatei vom Handy in den Editor.

## Seite lädt nicht? Diagnose

1. **http://192.168.4.1/ping** öffnen. Das ist reiner Text ohne JavaScript. Kommt „OK RS232 Web Console …“ zurück, läuft der Webserver. `dns N` zeigt, wie viele Namensanfragen das Captive Portal schon beantwortet hat.
2. **Serielle Konsole** (USB-C, 115200 Baud) mitlaufen lassen. Die Firmware protokolliert:

   | Zeile | Bedeutung |
   |---|---|
   | `[WLAN] … Belegung Kanal 1/6/11: … -> Kanal 11` | Beim Start sucht sich der Hotspot den freiesten Kanal |
   | `[WLAN] Hotspot RS232-XXXX auf Kanal 11, Sendeleistung 8.5 dBm` | Hotspot läuft |
   | `[WLAN] Client hat IP 192.168.4.2` | Handy ist im WLAN |
   | `[dns] captive.apple.com A -> 192.168.4.1` | Handy fragt den Namensdienst des Geräts (Hotspot-Erkennung) |
   | `[HTTP]   -> captive redirect …` | Handy wird auf die Konsole umgeleitet |
   | `[HTTP] 192.168.4.2 GET http://192.168.4.1/` und `-> 200 136682 Bytes in 180 ms` | Seite ausgeliefert, mit Dauer |
   | `[HTTP] …: leere Verbindung verworfen` | Browser hatte eine Reserve-Verbindung offen, harmlos |
   | `[WS]   client 0 connected` | Terminal verbunden |

   **Kein `[HTTP]`-Eintrag beim Aufruf:** Der Aufruf erreicht das Gerät nicht. Das Handy schickt ihn dann über Mobilfunk: mobile Daten aus bzw. „Ohne Internet verwenden“. Bei Chrome auf dem iPhone muss außerdem die Berechtigung „Lokales Netzwerk“ erlaubt sein.
   **Keine `[dns]`-Zeilen nach dem Verbinden:** Das Handy fragt einen anderen Namensdienst, typisch bei Firmen-iPhones mit VPN oder DNS-Profil. Die Hotspot-Seite erscheint dann nicht automatisch, `http://192.168.4.1` von Hand geht trotzdem.
   **`-> 200 …` dauert mehrere Sekunden oder `Client getrennt` direkt danach:** Funkproblem. Unter Menü → Setup einen festen Kanal (1/6/11) wählen oder die Sendeleistung erhöhen. Das Handy nicht direkt auf die Antenne legen.

## Fehlersuche

| Problem | Lösung |
|---|---|
| Terminal bleibt leer | Enter drücken · **Auto-Baud** · Belegung prüfen (TX/RX gekreuzt?) · Rollover-Kabel statt Patchkabel? |
| Zeichensalat | falsche Baudrate → Auto-Baud oder Baud-Chip |
| Web-UI lädt nicht | Handy hat den Hotspot wegen „kein Internet“ verlassen · `192.168.4.1` statt `.local` verwenden (Android) · `http://192.168.4.1/ping` testen · USB-Log lesen ([Diagnose](#seite-lädt-nicht-diagnose)) · Setup: festen Kanal oder mehr Sendeleistung |
| Akku-% unplausibel | kalibrieren, siehe [WAVESHARE.md](WAVESHARE.md#prozentanzeige-kalibrieren) |
| Upload scheitert | BOOT halten + RST drücken (Download-Modus) |
| Passwort vergessen | steht auf dem Display (Seite WLAN) und im USB-Log · sonst Werksreset im Web-UI |

## Web-UI ohne Hardware entwickeln

```bash
npm install ws
node tools/mock_device.js     # -> http://localhost:8080 (simuliert Gerät + Cisco-CLI)
```

## Projektstruktur

```
platformio.ini            Build-Konfiguration (Arduino-ESP32 2.0.17): waveshare-s3-lcd2
WAVESHARE.md              das Board: Touch-Oberfläche, Bluetooth, Pins, Akku, Debug-Konsole
src/config.h              Pins, Kalibrierung, Ports, Defaults
src/main.cpp              Setup/Loop, BOOT-Taste
src/serial_bridge.*       bis zu 4 UARTs (2 Hardware, 2 Software), Replay-Puffer, Break, Auto-Baud
src/xfer.*                XMODEM / XMODEM-1K / YMODEM-Sender
src/configs.*, player.*   gespeicherte Konfigurationen und ihr Abspielen am Gerät
src/net.*                 WLAN (inkl. 802.1X), HTTP, WebSocket (Port 81), Raw-TCP, OTA
src/certs.*               Zertifikatsspeicher (PKCS#12/PEM/DER/PKCS#7), CSR, Geräte-CA
src/https.*               TLS-Frontend Port 443 (HTTPS + WSS)
src/legacy_ciphers.*      DES/3DES/RC2 zum Lesen alter PKCS#12-Dateien
src/display.h, lcd_ui.cpp Touch-Oberfläche auf dem 2″-LCD
src/ble.*                 serielle Konsole über Bluetooth LE
src/c2.*, c2_proto.*      Client der Leitstelle: Task, Speicher, HTTP / Protokoll und Kryptografie
lib/mlkem_native/         ML-KEM (FIPS 203), übernommen aus mlkem-native v1.0.0
src/sdcard.*              SD-Karte: Mitschnitte
src/power.*, bat_curve.h  Akku-Messung, Ladeerkennung, Sparmodus, Kennlinie
src/settings.*            Einstellungen (NVS)
src/web_assets.h          generiert aus web/ (nicht von Hand bearbeiten)
web/                      Web-UI (index.html, app.js, style.css, xterm.js)
tools/embed_web.py        bündelt web/ zu EINER Seite (CSS/JS eingebettet) und packt sie gzip-komprimiert in die Firmware
tools/lcd_debug.py        Debug-Konsole: Screenshots, simulierte Taps, Akku-Rohwerte
tools/mock_device.js      Geräte-Simulator für die UI-Entwicklung
docs/                     Screenshots der Weboberfläche
```

Drittsoftware: xterm.js und xterm-addon-fit (MIT, `web/vendor/LICENSE-xterm.txt`), mlkem-native (Apache-2.0 oder ISC oder MIT, `lib/mlkem_native/LICENSE`), LovyanGFX (BSD-2-Clause/MIT), NimBLE-Arduino (Apache-2.0), arduinoWebSockets (LGPL-2.1), ArduinoJson (MIT), EspSoftwareSerial (LGPL-2.1), mbedTLS (Apache-2.0, im ESP32-SDK enthalten). `src/legacy_ciphers.cpp` enthält DES-Code aus LibTomCrypt (Public Domain) und RC2-Code aus PyCryptodome (BSD-2-Clause).

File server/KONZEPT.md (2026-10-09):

# Leitstelle (Command-and-Control-Server) — Konzept

**Stand:** 9. Oktober 2026 · Phase 1 (Server) und Phase 2 (Firmware-Client) umgesetzt · am Waveshare-Board gegen den Server im lokalen Netz geprüft, nicht im Internet

Ein Server im Internet, bei dem sich die RS232-Konsolen anmelden. Er weiß, welche Geräte es gibt und ob sie erreichbar sind, und kann ihnen Aufträge geben. Dieses Dokument beschreibt das Ziel, die Sicherheitsannahmen, das Protokoll und die Phasen. Was davon gebaut und geprüft ist, steht in §7; wie man es startet, in `README.md`; die Geräteseite in `firmware/README.md`.

## 1. Ziele

1. **Erreichbar aus dem Internet**, die Geräte dagegen nicht: Ein Gerät steht hinter NAT, im Hotspot eines Handys oder in einem Firmennetz. Es baut die Verbindung immer selbst auf (ausgehend, HTTPS). Der Server öffnet nie eine Verbindung zum Gerät.
2. **Zweiseitige Prüfung bei der Registrierung:** Das Gerät muss sicher sein, mit dem richtigen Server zu sprechen, und der Server, dass genau dieses Gerät gemeint ist — bestätigt von einem Menschen, der das Gerät vor sich hat.
3. **Leichtgewichtig:** wenige Kilobyte pro Kontakt, kurze HTTPS-Anfragen, kein dauerhaft offener Kanal. Der ESP32-S3 hat dafür rund 100 kB freien Heap neben WLAN, Bluetooth und Display.
4. **Sicher auch gegen künftige Quantenrechner:** Wer heute mitschneidet, soll den Verkehr auch später nicht entschlüsseln können, und die Anmeldung soll nicht an einem Verfahren hängen, das ein Quantenrechner bricht.
5. **Lokal testbar, später in die Cloud:** ein Container ohne äußere Abhängigkeiten, Konfiguration über Umgebungsvariablen.

Bewusst **nicht** Ziel der ersten Phasen: Fernzugriff auf die serielle Konsole. Das ist die mächtigste und heikelste Funktion (wer sie hat, sitzt auf der Konsole eines Switches) und kommt erst, wenn Anmeldung, Rechte und Protokollierung stehen (Phase 4).

## 2. Bedrohungen und Annahmen

| Angreifer | Was er kann | Schutz |
|---|---|---|
| Lauscher im Netz, heute | TLS-Verkehr mitschneiden und aufheben | innerer Kanal mit ML-KEM-768; ein später gebrochenes X25519 oder TLS reicht nicht |
| Mann in der Mitte (gefälschtes TLS-Zertifikat, DNS, fremdes WLAN) | sich als Server ausgeben | das Gerät vertraut nur dem Serverschlüssel, dessen Fingerabdruck im Einladungs-Token steht; TLS ist die äußere Hülle, nicht der Vertrauensanker |
| Fremder mit Internetzugang | ein eigenes Gerät anmelden, Aufträge abholen | Einladungs-Token (einmalig, läuft ab) und Bestätigungscode vom Gerätedisplay |
| Jemand, der ein Token abfängt | sein Gerät statt des gemeinten anmelden | der Mensch tippt den Code ein, den **sein** Gerät zeigt; ein fremdes Gerät hätte einen anderen |
| Jemand, der Geräte-ID und öffentlichen Schlüssel kennt | sich als das Gerät ausgeben | ohne den privaten Schlüssel lassen sich die Sitzungsschlüssel nicht ableiten |
| Dieb eines Geräts | privaten Schlüssel aus dem Flash lesen (keine Flash-Verschlüsselung) | Gerät am Server sperren; mehr nicht — siehe §8 |
| Angreifer auf dem Server | alles, was der Server darf | Befehlsliste klein halten; heikle Befehle brauchen später die Zustimmung am Gerät (Phase 4) |

Annahmen: Der Server und sein Datenverzeichnis sind vertrauenswürdig. Der Administrator schützt sein Token. Der Mensch, der ein Gerät anmeldet, hat es vor sich.

## 3. Aufbau

```
 Gerät (ESP32-S3)                     Internet                     Leitstelle (Container)
 ┌──────────────────┐   HTTPS, ausgehend, alle 30 s   ┌──────────────────────────────────┐
 │ Geräteschlüssel   │ ──────────────────────────────▶ │ /v1/server-key  /v1/handshake     │
 │ gepinnter Server- │   innen: hybrider Kanal         │ /v1/msg         (binär)           │
 │ schlüssel         │ ◀────────────────────────────── │                                    │
 └──────────────────┘   Antwort: Aufträge              │ /admin/v1/...   (JSON, Token)     │
                                                        │ Datenverzeichnis: Schlüssel,       │
 Administrator ── HTTPS ──────────────────────────────▶ │ Geräte, Aufträge                   │
                                                        └──────────────────────────────────┘
```

Zwei Schichten, mit Absicht:

- **Außen HTTPS.** Kommt durch Firewalls und Proxys, schützt die Admin-Schnittstelle, verbirgt Metadaten. Der Server (Go) handelt mit Clients, die es können, von selbst den hybriden Schlüsseltausch X25519MLKEM768 aus. Das Gerät kann das nicht: Arduino-Core 2.0.17 bringt mbedTLS 2 mit, also TLS 1.2 mit klassischen Verfahren.
- **Innen ein eigener Kanal** zwischen Gerät und Server, hybrid aus X25519 und ML-KEM-768. Er trägt die Sicherheit: Vertraulichkeit, gegenseitige Echtheit, Schutz vor Wiedereinspielen. Er hängt nicht davon ab, ob das TLS-Zertifikat geprüft wurde oder wo TLS endet (Load-Balancer in der Cloud).

„Hybrid" heißt: Jeder Schlüssel entsteht aus einem klassischen **und** einem Post-Quanten-Geheimnis. Bricht eines der beiden Verfahren — ML-KEM ist jung, X25519 fällt gegen Quantenrechner —, hält das andere.

## 4. Protokoll (Version 1)

Maßgeblich ist der Code in `internal/proto/proto.go`; die Firmware muss genau das nachbauen. Hier die Idee.

### 4.1 Schlüssel

Server und jedes Gerät haben einen **Langzeitschlüssel** aus zwei Teilen: X25519 (32 Byte öffentlich) und ML-KEM-768 (1184 Byte öffentlich), zusammen 1216 Byte. Der **Fingerabdruck** ist SHA-256 darüber, die **Geräte-ID** dessen erste 16 Byte. Das Gerät erzeugt seinen Schlüssel selbst; der private Teil verlässt es nie.

Es gibt **keine Signaturen**. Echtheit entsteht allein durch Schlüsselkapselung: Wer entkapseln kann, was an einen Langzeitschlüssel gekapselt wurde, besitzt ihn. Das Gerät braucht damit nur ein Post-Quanten-Verfahren (ML-KEM) statt zwei; ML-DSA-Signaturen wären mit 3,3 kB je Signatur und großem Stack-Bedarf der teurere Teil.

### 4.2 Handshake

Eine Anfrage, eine Antwort.

| Richtung | Inhalt | Größe |
|---|---|---|
| Gerät → Server `POST /v1/handshake` | Version, Art, Geräte-ID, flüchtiger X25519-Schlüssel, flüchtiger ML-KEM-Schlüssel, Kapsel an den Langzeitschlüssel des Servers | 2322 Byte |
| nur bei der Anmeldung zusätzlich | Langzeitschlüssel des Geräts, Token-ID | +1224 Byte |
| Server → Gerät | Version, Sitzungs-ID, flüchtiger X25519-Schlüssel, Kapsel an den flüchtigen Geräteschlüssel, Kapsel an den Langzeitschlüssel des Geräts, Bestätigung (HMAC) | 2257 Byte |

Daraus entstehen sechs gemeinsame Geheimnisse:

| | Post-Quanten (ML-KEM-768) | klassisch (X25519) |
|---|---|---|
| beweist den **Server** | Kapsel an den Server-Langzeitschlüssel | flüchtig (Gerät) × Langzeit (Server) |
| beweist das **Gerät** | Kapsel an den Geräte-Langzeitschlüssel | flüchtig (Server) × Langzeit (Gerät) |
| **Vorwärtsgeheimnis** | Kapsel an den flüchtigen Geräteschlüssel | flüchtig × flüchtig |

Alle sechs gehen durch HKDF-SHA-256, zusammen mit einem Hash über beide Langzeitschlüssel und jedes ausgetauschte Byte. Heraus kommen je ein Schlüssel pro Richtung, die Bestätigung des Servers und — bei der Anmeldung — der Bestätigungscode.

- Der **Server ist bewiesen**, wenn seine Bestätigung stimmt: Die kann nur berechnen, wer den gepinnten Langzeitschlüssel hat.
- Das **Gerät ist bewiesen**, sobald seine erste verschlüsselte Nachricht aufgeht. Bis dahin gilt die Sitzung nichts und verfällt nach zwei Minuten (nicht kürzer: an einem schwachen WLAN braucht das Gerät mehrere Anläufe).
- **Vorwärtsgeheimnis:** Wird später ein Langzeitschlüssel gestohlen, bleiben alte Mitschnitte zu.

### 4.3 Nachrichten

`POST /v1/msg`: Sitzungs-ID (16) ‖ Zähler (8) ‖ AES-256-GCM-Chiffrat. Antwort: Zähler ‖ Chiffrat. Der Zähler ist die Nonce und muss steigen (kein Wiedereinspielen); Richtung, Sitzungs-ID und Zähler sind mitauthentifiziert. AES-GCM, weil der ESP32 AES in Hardware rechnet. Höchstens 32 kB Klartext je Nachricht.

Der Klartext ist JSON (mit ArduinoJson am Gerät billig; später CBOR, falls die Größe stört):

```
Gerät → Server   {"t":"enroll","name":"Labor-1","info":{"fw":"1.8.0"}}
                 {"t":"poll","status":{...},"results":[{"id":7,"ok":true,"out":"pong"}]}
Server → Gerät   {"state":"pending|active","cmds":[{"id":7,"type":"ping","args":{}}],"poll_s":30}
```

Eine Sitzung gilt eine Stunde, dann handelt das Gerät neue Schlüssel aus. Sitzungen liegen nur im Speicher des Servers; nach einem Neustart antwortet er mit 401 und das Gerät macht einen neuen Handshake. HTTP-Status für Geräte: 401 = neu aushandeln, 403 = nicht (mehr) willkommen, ohne Begründung. Das Gerät spricht schlichtes HTTP/1.0 — eine Anfrage, eine Antwort, Verbindung zu; der Server nennt immer `Content-Length`.

### 4.4 Registrierung mit zweiseitiger Prüfung

1. **Einladen.** Der Administrator erzeugt am Server ein **Einladungs-Token**: Server-Adresse, Fingerabdruck des Serverschlüssels, Token-ID und ein Geheimnis (32 Byte). Einmal verwendbar, läuft ab (Vorgabe 10 Minuten). Eine Textzeile `c2e1:…`, später auch als QR-Code.
2. **Token ins Gerät.** Über die Weboberfläche des Geräts (Hotspot, `192.168.4.1`) — also über einen Weg, den der Bediener in der Hand hat.
3. **Gerät prüft den Server.** Es holt den Serverschlüssel, vergleicht den Fingerabdruck mit dem Token und pinnt ihn. Im Handshake muss der Server diesen Schlüssel beweisen. Das Token-Geheimnis wird **nicht gesendet**, sondern in die Schlüsselableitung gemischt: Ein Server, der es nicht kennt, kann die Bestätigung nicht berechnen; ein Gerät, das es nicht kennt, kann keine gültige Nachricht schicken.
4. **Server merkt das Gerät vor** (`pending`). Es darf sich melden, bekommt aber keine Aufträge.
5. **Mensch bestätigt.** Beide Seiten leiten aus dem Handshake denselben **sechsstelligen Code** ab. Das Gerät zeigt ihn auf dem Display. Der Administrator **tippt ihn am Server ein** — der Server zeigt ihn nirgends an, damit niemand blind auf „Bestätigen" klickt. Stimmt er, ist das Gerät `active`. Nach fünf falschen Eingaben ist die Anmeldung verworfen.

Damit weiß das Gerät: richtiger Server (Fingerabdruck aus dem Token, im Handshake bewiesen). Und der Server: eingeladenes Gerät (Token-Geheimnis) **und** genau das Gerät, das der Administrator vor sich hat (Code vom Display, gebunden an den Geräteschlüssel).

**Sperren:** Ein gesperrtes Gerät wird sofort getrennt und kommt auch mit neuem Token nicht zurück (sein Schlüssel ist bekannt und gesperrt).

## 5. Server

- **Go, nur Standardbibliothek** (`crypto/mlkem` nach FIPS 203, `crypto/ecdh`, `crypto/hkdf`, AES-GCM). Keine fremden Pakete, ein statisches Programm, Container ohne Shell und ohne Root.
- **Admin-Schnittstelle** `/admin/v1/…`, JSON, geschützt durch ein Bearer-Token aus der Umgebung: Token erzeugen, Geräte auflisten, bestätigen, sperren, Auftrag einreihen, Aufträge und Ergebnisse lesen. Auftragsarten stehen auf einer festen Liste (Phase 1: `ping`, `status`).
- **Zustand** in einer JSON-Datei im Datenverzeichnis (Serverschlüssel, Geräte, Tokens, Aufträge), atomar geschrieben, Rechte 0600. Reicht für wenige Geräte und einen Prozess.
- **TLS:** lokal selbstsigniert (wird beim ersten Start erzeugt), mit eigenen Zertifikatsdateien, oder aus (hinter einem Proxy, der TLS beendet).

## 6. Phasen

| Phase | Inhalt | Stand |
|---|---|---|
| **0 Konzept** | dieses Dokument | fertig |
| **1 Server-Kern** | Protokoll, Registrierung mit Code, Sitzungen, Auftragswarteschlange, Admin-API, Gerätesimulator, Docker, Tests | **fertig, lokal getestet** (§7) |
| **2 Firmware-Client** | ML-KEM-768 auf dem ESP32-S3 (mlkem-native), X25519/HMAC/AES-GCM aus mbedTLS 2; Geräteschlüssel im NVS; Token-Eingabe in der Weboberfläche; Code auf dem Touch-Display; Poll-Schleife; Aufträge `ping` und `status` | **fertig, am Gerät im lokalen Netz getestet** (§7); offen: Weboberfläche im Browser ansehen, QR-Code fürs Token |
| **3 Aufträge und Oberfläche** | Status und Telemetrie (Akku, WLAN, Ports), Einstellungen lesen, gespeicherte Konfiguration auf einen Port abspielen, Firmware-Update anstoßen; Weboberfläche für den Administrator; QR-Code fürs Token | offen |
| **4 Fernkonsole** | serielle Konsole über die Leitstelle, Ende-zu-Ende bis zum Browser des Administrators; nur nach Freigabe am Gerät (Touch), zeitlich begrenzt, mit Protokoll. Braucht einen schnelleren Rückkanal (Long-Polling oder WebSocket) | offen |
| **5 Cloud-Betrieb** | Datenbank statt JSON-Datei; echtes TLS-Zertifikat (Proxy oder ACME); Begrenzung der Anfragerate; Sicherung des Datenverzeichnisses; Benutzerkonten mit zweitem Faktor statt eines Tokens; Wechsel des Serverschlüssels; Überwachung | offen |
| **später** | signierte Firmware-Updates (ML-DSA oder SLH-DSA, geprüft im Gerät); Flash-Verschlüsselung für den Geräteschlüssel | offen |

Reihenfolge mit Absicht: Phase 2 vor allem anderen am Server, weil erst das echte Gerät zeigt, ob Größen und Rechenzeiten passen. Phase 5 muss vor dem ersten Betrieb im Internet abgeschlossen sein — Phase 1 ist ein lokaler Prüfstand.

## 7. Was geprüft ist

### Phase 1: Server

Alles auf dem Raspberry Pi (arm64), Go 1.25, im Container.

- **Protokoll** (`internal/proto`, 9 Tests): Sitzung und Anmeldung hin und zurück; Code auf beiden Seiten gleich; falscher Server (Mann in der Mitte) wird am Gerät erkannt; falsches Token-Geheimnis ebenso; ein Fremder mit Geräte-ID und öffentlichem Schlüssel bringt keine Nachricht durch; Wiedereinspielen, verfälschte und zurückgespiegelte Nachrichten werden verworfen; jedes gekippte Byte der Handshake-Antwort fällt auf; verstümmelte Eingaben.
- **Server über HTTP** (`internal/server`, 11 Tests): Anmelden, Bestätigen, Auftrag hin, Ergebnis zurück; vorgemerktes Gerät bekommt nichts; die Geräteliste verrät den Code nicht; falscher Code und Verwerfen nach fünf Versuchen; Token nur einmal und nur bis zum Ablauf; Token mit fremder Server-Adresse; gefälschtes Token-Geheimnis; Sperren trennt sofort und endgültig; unbekanntes Gerät; Sitzungsablauf und Server-Neustart; Admin-Token; Müll an den Geräte-Endpunkten; binäre Antworten nennen ihre Länge.
- **Ende zu Ende im Container** (`test/e2e.sh`): Image bauen (16 MB), Server mit leerem Datenverzeichnis starten, simuliertes Gerät in eigenem Container anmelden, Token ein zweites Mal abgelehnt, falscher und richtiger Code, Auftrag `ping` → `pong`, Neustart des Servers, Sperren.
- **Äußeres TLS:** `openssl s_client -groups X25519MLKEM768` gegen den Container handelt TLS 1.3 mit genau dieser hybriden Gruppe aus.

### Phase 2: Firmware

Die Geräteseite des Protokolls ist `firmware/src/c2_proto.cpp` (ohne Arduino, läuft auch auf dem PC), der Rest — Task, Speicher, HTTP, Aufträge — `firmware/src/c2.cpp`. ML-KEM kommt aus mlkem-native v1.0.0 (`firmware/lib/mlkem_native/`), alles andere aus dem mbedTLS 2.28 des Arduino-Cores.

- **Auf dem PC** (`tests/c2/run.sh`): derselbe Protokollcode, übersetzt gegen mbedTLS 2.28 (Debian bookworm im Container), meldet sich am echten Server-Container an, wird bestätigt, holt einen Auftrag ab und liefert das Ergebnis; ein Token, das einen anderen Serverschlüssel nennt, wird abgelehnt. Dazu Selbsttest mit bekannten Antworten: X25519 (RFC 7748), HKDF (RFC 5869), AES-256-GCM, ML-KEM-768 gegen einen von Gos `crypto/mlkem` errechneten Schlüssel.
- **Am Waveshare-Board** (9. Oktober 2026, Server im Container auf dem Raspberry Pi im selben WLAN, TLS mit selbstsigniertem Zertifikat): derselbe Selbsttest läuft bei jedem Start auf dem Gerät und besteht. Anmelden mit Token über `/api/c2/enroll`; Code im Log, in `/api/c2` und auf der Info-Seite des Displays (Screenshot); falscher Code am Server abgelehnt, richtiger angenommen; Aufträge `status` und `ping` ausgeführt, Ergebnisse am Server; Neustart des Geräts — verbindet sich von selbst wieder; Sperren am Server — Gerät meldet „abgewiesen"; Abmelden löscht Schlüssel und Server.
- **Gemessen am Gerät:** ein Handshake dauert 2,5–4,7 s, davon 1,1–1,5 s Rechnen, der Rest TLS-Aufbau und Netz. Woran die Rechenzeit im Einzelnen hängt (ML-KEM, die fünf X25519-Multiplikationen über mbedTLS, das Anlegen des Hilfstasks), ist nicht aufgeschlüsselt. ML-KEM braucht rund 19 kB Stack. Freier Heap im Betrieb mit Bluetooth 93 kB, Tiefststand während einer TLS-Verbindung 38 kB.
- **Nicht geprüft:** der Block „Leitstelle" der Weboberfläche im Browser (die Aufrufe dahinter per curl); die Meldung mit dem Code als Einblendung auf dem Display (nur die Info-Zeile per Screenshot); Betrieb über Stunden (Sitzungswechsel nach einer Stunde am Gerät); Akkubetrieb mit 80 MHz; ein Server außerhalb des lokalen Netzes.

Was die Arbeit am Gerät gezeigt hat:

- **TLS und ML-KEM passen nicht gleichzeitig in den Speicher.** Eine TLS-Verbindung kostet rund 45 kB Heap, der Stack für ML-KEM 28 kB. Der Schlüsseltausch wird deshalb gerechnet, bevor die Anfrage hinausgeht und nachdem die Antwort da ist — in einem kurzlebigen Task mit großem Stack, dessen Speicher sofort wieder frei ist (`big()` in `c2.cpp`).
- **Der Server muss `Content-Length` nennen.** Gos `net/http` schickt Antworten über 2 kB sonst in Stücken (chunked); die Handshake-Antwort hat 2257 Byte. Simulator und PC-Test hatten das nicht bemerkt, das Gerät schon.
- **Schwaches WLAN.** Am Testplatz (−77 bis −83 dBm, Sendeleistung 8,5 dBm) kamen Pakete über etwa 1100 Byte zeitweise gar nicht durch — das betrifft auch die Weboberfläche des Geräts im LAN, nicht nur die Leitstelle. Mit 19,5 dBm ging es meist. Der Client wiederholt eine gescheiterte Anfrage deshalb bis zu dreimal und wartet bis zu 20 s; mehr kann er gegen eine schlechte Funkstrecke nicht tun. Möglich wäre, die MTU des WLAN-Clients bei schwachem Signal zu senken.

## 8. Grenzen und offene Fragen

- **Eigenes Protokoll.** Der Aufbau folgt bekannten Mustern (KEM-basierte Authentifizierung wie bei KEMTLS, hybride Ableitung wie bei X25519MLKEM768), ist aber selbst zusammengesetzt und **von niemandem begutachtet**. Vor einem Betrieb im Internet sollte jemand mit Kryptografie-Erfahrung darauf sehen. Die Bausteine selbst kommen aus Gos Standardbibliothek.
- **Rechenzeit am Gerät:** gut eine Sekunde je Handshake (§7), einmal pro Stunde. Der Hauptschleife und damit der seriellen Brücke nimmt das nichts, der Client hat einen eigenen Task auf dem anderen Kern. Ob sich das im Akkubetrieb bei 80 MHz bemerkbar macht, ist offen.
- **Der Geräteschlüssel liegt unverschlüsselt im Flash**, wie heute schon die 802.1X-Schlüssel. Wer das Gerät hat, hat den Schlüssel; dagegen hilft nur Sperren am Server.
- **Sechs Ziffern** lassen einem Angreifer, der ein Token abgefangen hat, eine Chance von eins zu einer Million je Versuch, bei fünf Versuchen. Mehr Ziffern sind möglich, aber lästiger abzulesen.
- **Keine Begrenzung der Anfragerate.** Ein Handshake kostet den Server Rechenzeit; ohne Token oder bekannte Geräte-ID wird er zwar vor der Kryptografie abgewiesen, aber eine bekannte Geräte-ID genügt, um ihn auszulösen. Gehört in Phase 5.
- **Ein Admin-Token für alles**, keine Benutzer, kein Protokoll der Admin-Aktionen. Phase 5.
- **Aufträge** werden einmal zugestellt. Startet das Gerät neu, bevor es das Ergebnis meldet, bleibt der Auftrag auf „gesendet" stehen. Wiederholen oder Verfallen ist Phase 3.
- **TLS am Gerät prüft das Zertifikat nicht** (`setInsecure()`): Der innere Kanal beweist den Server ohnehin, und nur so geht ein selbstsignierter Testserver. Ob das Gerät im Betrieb zusätzlich gegen eine CA prüft, ist zu entscheiden; es wäre die sauberere Wahl, kostet aber ein CA-Bündel im Flash. Ohne Prüfung sieht ein Mann in der Mitte, **dass** ein Gerät mit der Leitstelle spricht, und kann stören — mitlesen oder sich als Server ausgeben kann er nicht.

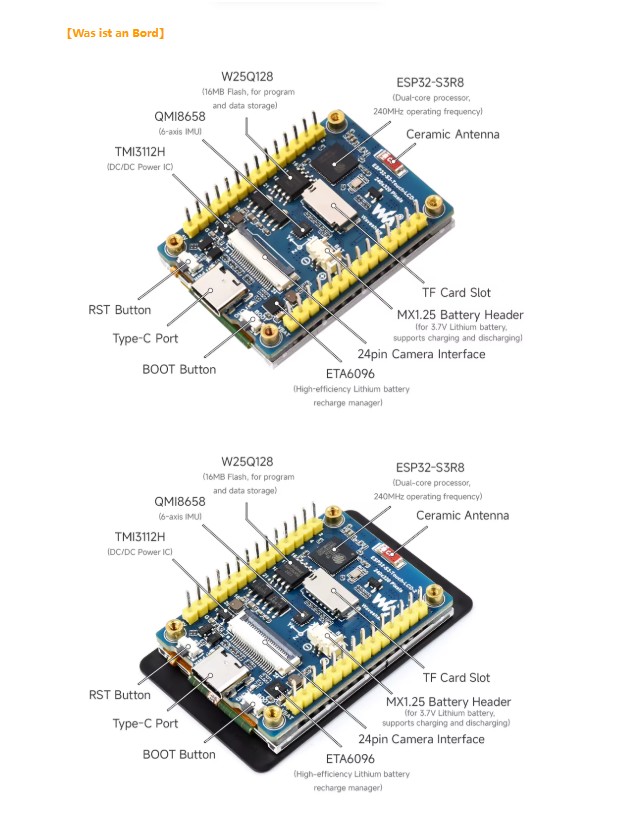
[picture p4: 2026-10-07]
esp32-s3-specs.jpg

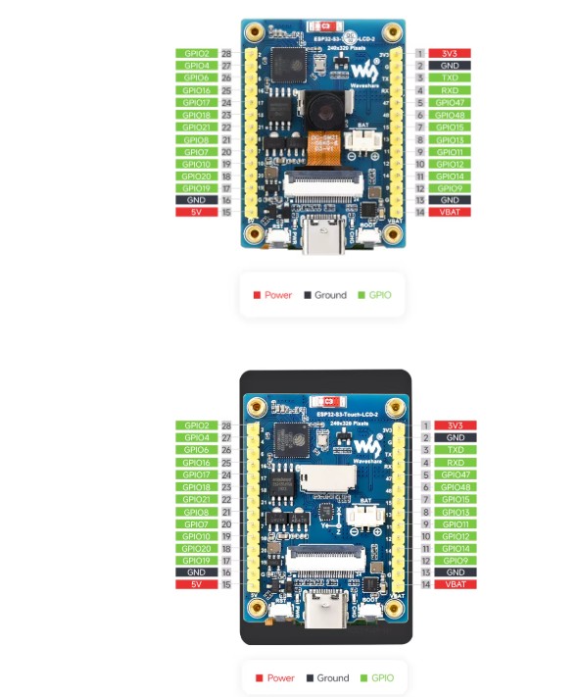
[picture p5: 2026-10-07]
esp32-s3-ports.jpg

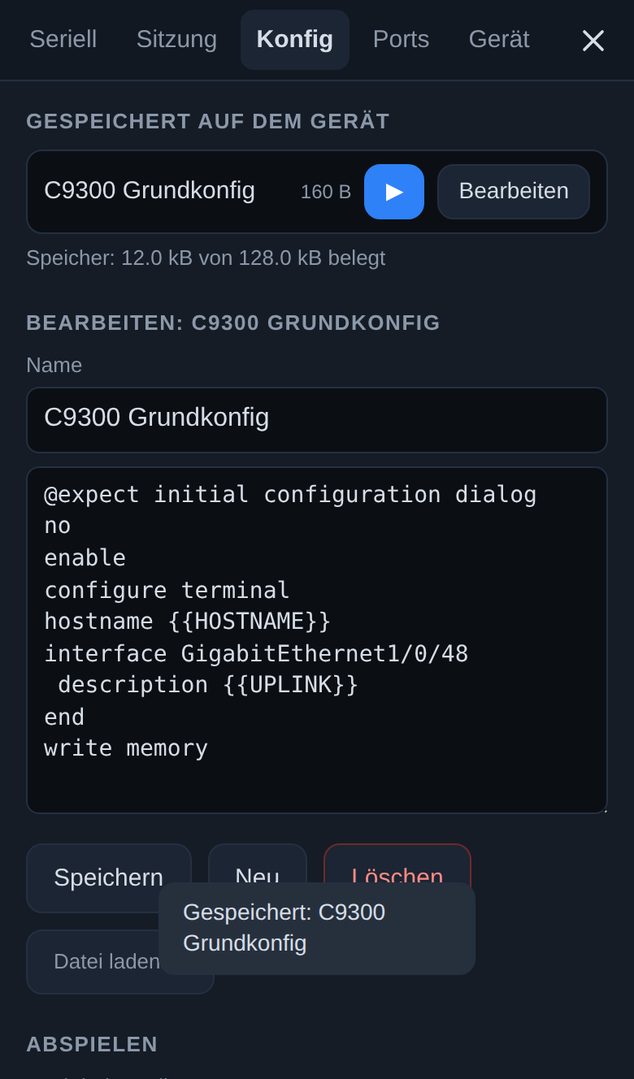
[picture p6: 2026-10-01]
firmware/docs/webui_konfig.png

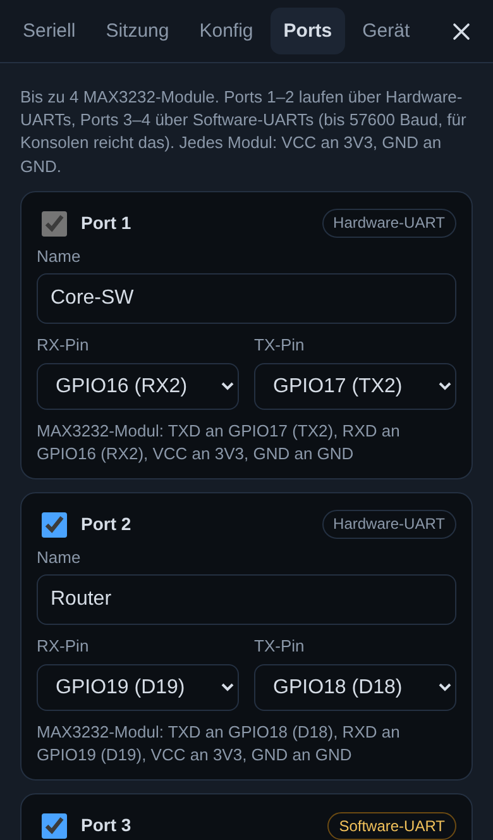
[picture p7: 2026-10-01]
firmware/docs/webui_ports.png

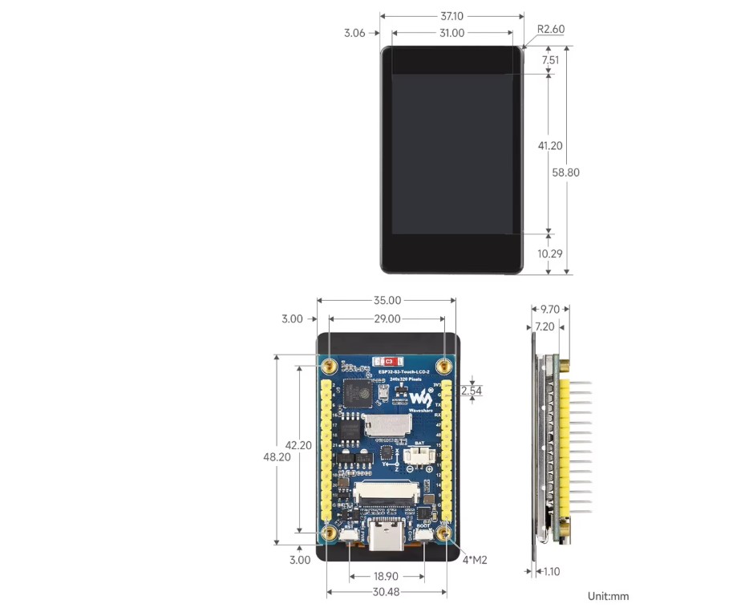
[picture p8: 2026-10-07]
esp32-s3.jpg

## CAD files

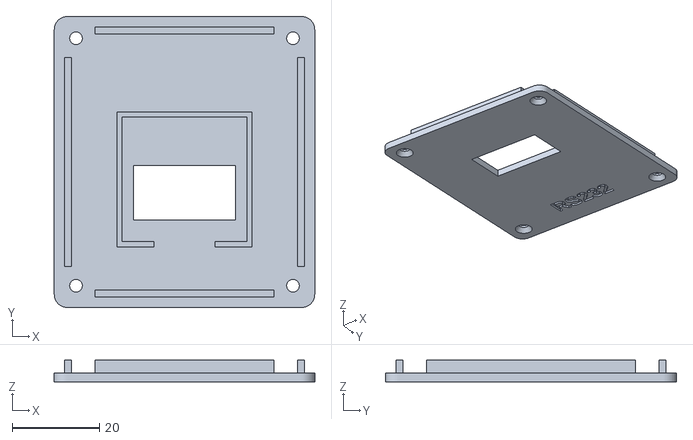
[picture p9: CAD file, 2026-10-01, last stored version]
firmware/case/rs232_console_lid_standardmasse.stl
59.8 x 66.8 x 5.00

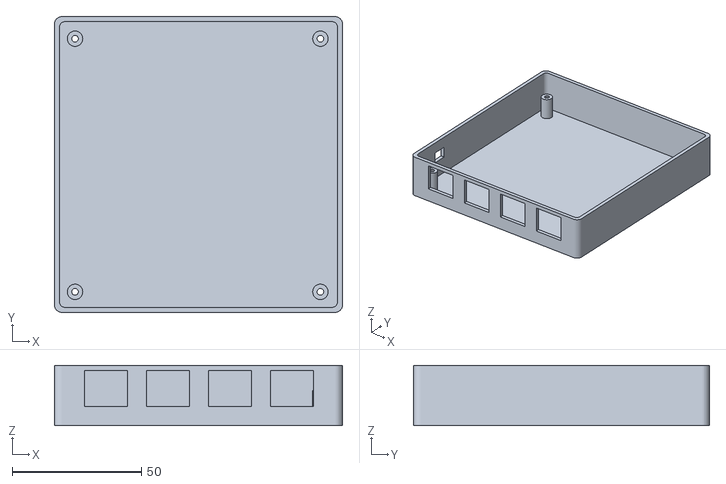
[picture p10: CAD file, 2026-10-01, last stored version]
hardware/gehaeuse/bottom.stl
111.6 x 114.6 x 23.3

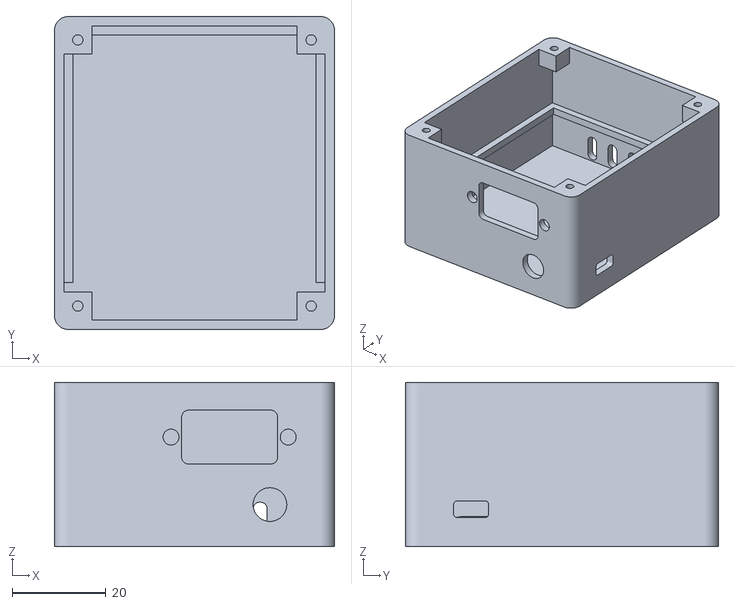
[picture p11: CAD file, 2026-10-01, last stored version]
firmware/case/rs232_console_body_standardmasse.stl
59.8 x 66.8 x 35.1

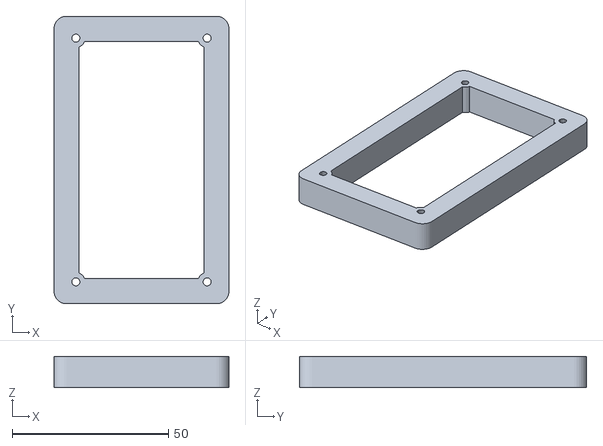
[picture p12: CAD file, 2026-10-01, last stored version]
hardware/gehaeuse/spacer.stl
56.0 x 92.0 x 10.0

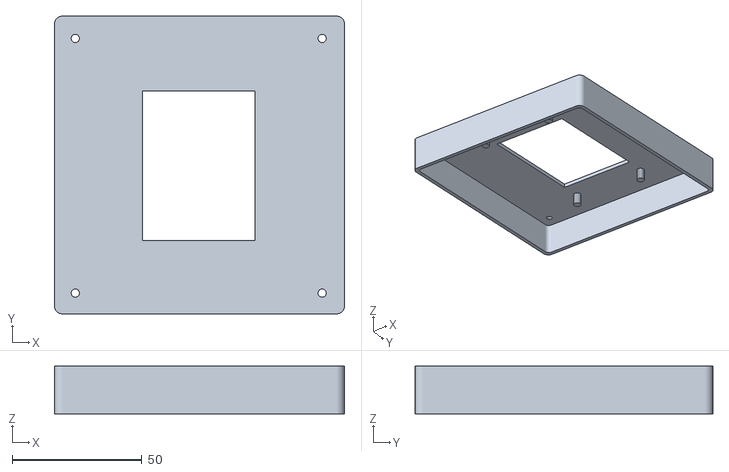
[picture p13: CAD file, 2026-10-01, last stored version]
hardware/gehaeuse/top.stl
111.6 x 114.6 x 18.4

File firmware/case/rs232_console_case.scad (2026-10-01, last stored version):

// ============================================================================
//  RS232 Web Console - 3D-printable enclosure (parametric, OpenSCAD)
//  LilyGO T-RSS3 + 1S LiPo + charge/boost module + 0.96"/1.3" OLED
//
//  !!! All part dimensions below are ESTIMATES. Measure your parts with a
//  !!! caliper and adjust the "MEASURE" values before printing.
//
//  Stack (bottom -> top):  floor | LiPo + charger module | T-RSS3 on side
//  ledges | OLED under the lid.  DB9 through the front wall.
//
//  Export:  part = "body";  -> F6 -> Export STL
//           part = "lid";   -> F6 -> Export STL
//  Print: PETG/PLA, 0.2 mm layers, 3 walls, no supports (lid upside down).
// ============================================================================

part = "assembly";   // [assembly, body, lid]

/* [T-RSS3 board - MEASURE] */
pcb_w      = 55.0;   // X, left-right, DB9 edge facing you
pcb_d      = 52.0;   // Y, front (DB9 edge) to back
pcb_t      = 1.6;
comp_h     = 13.0;   // tallest part above PCB top (RSM modules / DB9 / terminals)
under_h    = 2.5;    // solder joints / pins below the PCB
db9_x      = 35.0;   // DB9 centre, measured from LEFT PCB edge
db9_z      = 6.3;    // DB9 centre above PCB TOP surface
db9_front  = 1.0;    // how far the DB9 flange sticks out past the PCB front edge

/* [Battery + charge/boost module - MEASURE] */
bat_l      = 50.0;   // 103450 LiPo (2000 mAh): 50 x 34 x 10 mm
bat_w      = 34.0;
bat_t      = 10.5;   // incl. protection PCB / tape
chg_l      = 25.0;   // module along the LEFT wall (Y)
chg_w      = 21.0;   // module depth into the box (X)
chg_t      = 5.0;    // incl. USB-C socket
chg_usb_z  = 2.4;    // USB-C centre above module bottom
chg_usb_y  = 12.5;   // USB-C centre from the front inner wall

/* [OLED module - MEASURE] */
oled_pcb_w = 27.8;   // 0.96" module: 27.3 x 27.8 ; 1.3" module: 35.4 x 33.5
oled_pcb_h = 27.8;
oled_win_w = 23.5;   // visible glass area (+ margin)
oled_win_h = 12.5;
oled_win_dy= 5.0;    // glass window starts this far from the module's top (pin) edge ... see preview
oled_stack = 4.0;    // module thickness incl. soldered wires
oled_cx    = 0;      // module centre offset from lid centre (X)
oled_cy    = 4;      // module centre offset from lid centre (Y, + = towards back)

/* [Controls] */
btn_d      = 7.2;    // 7 mm panel push button (front wall, below the DB9)
btn_x      = 44.0;   // from inner left wall
btn_z      = 7.0;    // centre above floor top
sw_slot_l  = 7.5;    // SS12D00 slide switch: lever slot in the right wall
sw_slot_h  = 3.6;
sw_y       = 12.0;   // from inner front wall
sw_z       = 6.0;    // centre above floor top
sw_hole_dx = 0;      // set to 15 for panel switches with 2 x M2 holes, 0 = glue in

/* [Enclosure] */
wall       = 2.0;
floor_t    = 2.0;
lid_t      = 2.0;
clr        = 0.4;    // clearance around parts
ledge_w    = 2.0;    // PCB support ledges on the side walls
corner_r   = 3.0;
screw_d    = 2.2;    // pilot hole for M2.5 x 6 self-tapping screws (lid)
screw_head = 5.0;
lip_h      = 3.0;    // lid lip that sits inside the walls

$fn = 48;

// ---------------------------------------------------------------- derived
in_w  = max(pcb_w, bat_l + 2) + 2 * clr;
in_d  = max(pcb_d + db9_front, bat_w + chg_l + 3) + 2 * clr;
pcb_z = floor_t + max(bat_t, chg_t) + under_h + 0.5;    // PCB bottom (absolute)
pcb_top = pcb_z + pcb_t;
body_h = pcb_top + comp_h + oled_stack + 1.0;            // top edge of the walls
out_w = in_w + 2 * wall;
out_d = in_d + 2 * wall;
pcb_x0 = wall + (in_w - pcb_w) / 2;                      // PCB left edge (absolute)
pcb_y0 = wall + db9_front + clr;                         // PCB front edge (absolute)

echo(str("Enclosure outside: ", out_w, " x ", out_d, " x ", body_h + lid_t, " mm"));
echo(str("PCB bottom at z = ", pcb_z, " mm"));

module rbox(w, d, h, r) {
  hull() for (x = [r, w - r], y = [r, d - r]) translate([x, y, 0]) cylinder(r = r, h = h);
}

module rrect(w, h, r, t) {   // rounded rectangle in the XZ plane, extruded along Y by t
  rotate([90, 0, 0]) linear_extrude(t, center = true)
    offset(r) square([w - 2 * r, h - 2 * r], center = true);
}

// ---------------------------------------------------------------- body
module body() {
  difference() {
    union() {
      difference() {
        rbox(out_w, out_d, body_h, corner_r);
        translate([wall, wall, floor_t]) cube([in_w, in_d, body_h]);
      }
      // PCB ledges (left, right, back)
      for (x = [wall, wall + in_w - ledge_w])
        translate([x, wall + 8, pcb_z - 2]) cube([ledge_w, in_d - 8, 2]);
      translate([wall, wall + in_d - ledge_w, pcb_z - 2]) cube([in_w, ledge_w, 2]);
      // lid screw blocks in the top corners (above all components)
      for (x = [wall, wall + in_w - 6], y = [wall, wall + in_d - 6])
        translate([x, y, body_h - 5]) cube([6, 6, 5]);
    }
    // lid screw pilot holes
    for (x = [wall + 3, wall + in_w - 3], y = [wall + 3, wall + in_d - 3])
      translate([x, y, body_h - 4.5]) cylinder(d = screw_d, h = 5);

    // DB9 (female on the board): D cut-out + 2 jack screw holes, front wall
    translate([pcb_x0 + db9_x, wall / 2, pcb_top + db9_z]) {
      rrect(20.5, 11.5, 1.5, wall + 2);
      for (dx = [-12.5, 12.5]) translate([dx, 0, 0]) rotate([90, 0, 0]) cylinder(d = 3.4, h = wall + 2, center = true);
    }
    // USB-C of the charge module, left wall
    translate([wall / 2, wall + clr + chg_usb_y, floor_t + chg_usb_z])
      rotate([0, 0, 90]) rrect(9.8, 4.0, 1.6, wall + 2);
    // push button, front wall (below the PCB)
    translate([wall + btn_x, wall / 2, floor_t + btn_z])
      rotate([90, 0, 0]) cylinder(d = btn_d, h = wall + 2, center = true);
    // slide switch slot (+ optional screw holes), right wall
    translate([out_w - wall / 2, wall + sw_y, floor_t + sw_z]) {
      rotate([0, 0, 90]) rrect(sw_slot_l, sw_slot_h, 0.8, wall + 2);
      if (sw_hole_dx > 0) for (dy = [-sw_hole_dx / 2, sw_hole_dx / 2])
        translate([0, dy, 0]) rotate([0, 90, 0]) cylinder(d = 2.2, h = wall + 2, center = true);
    }
    // vent slots in the back wall (charger / LiPo)
    for (i = [0 : 4]) translate([out_w / 2 - 14 + i * 7, out_d - wall / 2, floor_t + 4])
      rrect(3, 7, 1.4, wall + 2);
  }
}

// ---------------------------------------------------------------- lid
module lid() {
  ow = oled_pcb_w + 2 * clr;
  oh = oled_pcb_h + 2 * clr;
  cx = out_w / 2 + oled_cx;
  cy = out_d / 2 + oled_cy;
  difference() {
    union() {
      rbox(out_w, out_d, lid_t, corner_r);
      // lip
      translate([wall + clr, wall + clr, -lip_h]) difference() {
        cube([in_w - 2 * clr, in_d - 2 * clr, lip_h]);
        translate([1.6, 1.6, -1]) cube([in_w - 2 * clr - 3.2, in_d - 2 * clr - 3.2, lip_h + 2]);
        // clear the screw blocks
        for (x = [-1, in_w - 2 * clr - 7], y = [-1, in_d - 2 * clr - 7]) translate([x, y, -1]) cube([8, 8, lip_h + 2]);
      }
      // OLED locating frame on the underside
      translate([cx - ow / 2 - 1.2, cy - oh / 2 - 1.2, -1.5]) difference() {
        cube([ow + 2.4, oh + 2.4, 1.5]);
        translate([1.2, 1.2, -1]) cube([ow, oh, 3]);
        translate([1.2 + ow / 2 - 7, oh, -1]) cube([14, 4, 3]);   // gap for the pin header / wires
      }
    }
    // OLED window (module pins towards the back)
    translate([cx - oled_win_w / 2, cy + oh / 2 - oled_win_dy - oled_win_h, -2]) cube([oled_win_w, oled_win_h, lid_t + 4]);
    // screw holes + countersink
    for (x = [wall + 3, wall + in_w - 3], y = [wall + 3, wall + in_d - 3]) translate([x, y, -5]) {
      cylinder(d = 2.9, h = 10);
      translate([0, 0, 5 + lid_t - 1.4]) cylinder(d1 = 2.9, d2 = screw_head, h = 1.41);
    }
    // engraved label
    translate([out_w / 2, wall + 7, lid_t - 0.6]) linear_extrude(1)
      text("RS232", size = 5, halign = "center", valign = "center", font = "Liberation Sans:style=Bold");
  }
}

// ---------------------------------------------------------------- dummies for the preview
module dummies() {
  // PCB
  color("#1a1a1a") translate([pcb_x0, pcb_y0, pcb_z]) cube([pcb_w, pcb_d - db9_front, pcb_t]);
  color("#333") translate([pcb_x0 + 3, pcb_y0 + 12, pcb_top]) cube([pcb_w - 6, 24, comp_h - 1]);
  color("silver") translate([pcb_x0 + db9_x - 15.4, wall + clr, pcb_top]) cube([30.8, 10, 12.5]);
  // LiPo + charger
  color("#3b6fb6") translate([wall + clr, wall + in_d - bat_w - clr, floor_t]) cube([bat_l, bat_w, bat_t]);
  color("#2e7d32") translate([wall + clr, wall + clr, floor_t]) cube([chg_w, chg_l, chg_t]);
}

if (part == "body") body();
else if (part == "lid") translate([0, out_d, lid_t]) rotate([180, 0, 0]) lid();
else {
  body();
  %dummies();
  translate([0, 0, body_h + 12]) lid();
}

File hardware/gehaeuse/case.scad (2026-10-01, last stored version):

// RS232-WLAN-Konsole -- 3D-printed enclosure, V0.2
// ARCHITECTURE CHANGE from v0.1: the design now stacks TWO boards instead of
// housing one custom all-in-one PCB:
//   Tier 1 (walled, bottom): the new I2C daughterboard (112.5x110mm, from
//   gen_pcb.py) -- 4x RJ45 + MAX3232 + SC16IS750 + local 3.3V regulator.
//   Tier 2 (open frame, standoffs only, no side walls): the off-the-shelf
//   LCDwiki "2.8inch ESP32-S3 Display" base board (50x86x10.6mm), which
//   supplies the ESP32-S3, LCD+touch, and USB-C/battery charging. It is NOT
//   rigidly plugged into the daughterboard (the base board's P3/P4 header is
//   1.25mm pitch, not stackable) -- the two boards are linked by a short
//   hand-wired pigtail cable (I2C + shared battery), so Tier 2 is left open
//   on the sides rather than walled: the base board's exact USB-C/button
//   positions weren't confirmed (see gen_pcb.py / parts.py docstring), so an
//   open shelf stays correct regardless of where they turn out to be, rather
//   than guessing a cutout position that might be wrong.
//
// Honestly-flagged assumptions:
//  - Base board mounting holes: 4x M3 (3.2mm), 42x78mm spacing, centered on
//    the 50x86mm board -- from LCDwiki's ES3C28P_Size.pdf dimension drawing.
//  - Daughterboard mounting holes: NOT actually present in gen_pcb.py yet
//    (no drilled mounting-hole footprints) -- standoffs below assume a
//    6mm corner inset, matching v0.1's convention. Add real mounting holes
//    to gen_pcb.py before ordering, or adjust these positions once you do.
//  - Battery: same 1000-2000mAh LiPo pouch assumption as v0.1 (~6.5mm thick),
//    now shared (Y-tapped) between both boards.
//  - Wall/standoff/heat-set-insert dimensions are standard FDM defaults,
//    not yet validated against a specific printer/filament.
//
// Prints as THREE separate parts, not two: modeling Tier-2's standoffs as
// part of the same contiguous solid as the bottom shell doesn't work -- they
// have to start above the daughterboard's own thickness (the real PCB fills
// that gap, not printed plastic), so in the CAD model they'd be floating,
// disconnected islands with nothing under them (caught via the "Volumes"
// count: a healthy hollow bottom shell with its standoffs properly fused
// reads "Volumes: 2"; modeling Tier 2 as more of the same solid gave
// "Volumes: 6" -- 4 extra, genuinely disconnected pieces, one per standoff).
// So Tier 2 is its own small part ("spacer"): an open frame that sits loose
// on top of the assembled daughterboard (resting on the real PCB surface,
// its own screws going through it) and holds the base board above that.
// This is a normal, sound pattern for a stacked enclosure, not a workaround.
//
// Usage:
//   openscad -o bottom.stl  -D part=\"bottom\"  case.scad
//   openscad -o spacer.stl  -D part=\"spacer\"  case.scad
//   openscad -o top.stl     -D part=\"top\"     case.scad
//   openscad -o preview.png -D part=\"assembly\" --imgsize=1600,1200 case.scad

part = "assembly"; // "bottom" | "spacer" | "top" | "assembly" (preview only, not for printing)

// -------------------------------------------------- daughterboard (Tier 1) --
// From gen_pcb.py: BOARD_W=107.0, BOARD_H=110.0 (KiCad mm, Y-down). BOARD_W
// dropped from the earlier 112.5mm once the daughterboard moved from 4
// separate one-chip-per-port support clusters to 2 shared clusters (see
// parts.py's v2.1 docstring: 2x SC16IS752 + 2x MAX3232, both channels used,
// instead of 4x SC16IS750 + 4x MAX3232) -- less board area needed for the
// same 4 RJ45 ports. Kept in sync here because DB_CORNERS (the standoff
// positions) are computed FROM this value by inset, not independently.
DB_W = 107.0;
DB_L = 110.0;
DB_THICKNESS = 1.6;

// RJ45 port positions copied from gen_pcb.py's port_cols_x / cluster row1:
RJ45_X = [18.0, 42.0, 66.0, 90.0];
RJ45_Y = 23.5;                    // cluster origin_y(12) + RJ45 CLASS_SIZE height(23)/2

// Shared I2C/battery-pigtail connector (J1/J2) sits on the "shared" cluster,
// origin (8,78) -- on the LEFT wall (low-X edge), roughly 2/3 down the board.
CABLE_X_POS = 20.0;               // approx J1/J2 cluster Y-center on the left edge

// ----------------------------------------------------- base board (Tier 2) --
DISP_W = 50.0;
DISP_L = 86.0;
DISP_THICKNESS = 10.6;            // touch variant (ES3C28P), tallest case
DISP_HOLE_DX = 42.0;              // mounting-hole spacing (LCDwiki ES3C28P_Size.pdf)
DISP_HOLE_DY = 78.0;
DISP_HOLE_D = 3.2;

// Centered on the daughterboard's footprint (Tier 2 has no walls of its own,
// so exact centering isn't safety-critical -- just needs to clear the lid's
// LCD window, set from the same center below).
DISP_CX = DB_W / 2;
DISP_CY = DB_L / 2;

// ------------------------------------------------------------ case shell --
WALL = 2.0;
FLOOR = 2.0;
LID_THICKNESS = 2.0;
GAP = 0.3;                        // clearance between DB edge and inner wall (Tier 1 only)
BATTERY_CLEARANCE_H = 6.5;        // typical 1000-2000mAh LiPo pouch, lies flat on the floor
DB_STANDOFF_H = 5.0;              // floor -> daughterboard seat
DISP_STANDOFF_H = 10.0;           // daughterboard top -> base-board seat; clears the
                                   // RJ45 jacks' upward protrusion (~7mm above the DB
                                   // plane, since they straddle the board edge) plus
                                   // room for the I2C/battery pigtail to loop through.
STANDOFF_OD = 6.0;
STANDOFF_ID = 2.6;                // pilot hole for a self-tapping M3 screw

INNER_W = DB_W + 2 * GAP;
INNER_L = DB_L + 2 * GAP;
OUTER_W = INNER_W + 2 * WALL;
OUTER_L = INNER_L + 2 * WALL;

DB_SEAT_Z   = FLOOR + BATTERY_CLEARANCE_H + DB_STANDOFF_H;             // bottom of daughterboard
DB_MID_Z    = DB_SEAT_Z + DB_THICKNESS / 2;                            // for RJ45 cutout centering
DISP_SEAT_Z = DB_SEAT_Z + DB_THICKNESS + DISP_STANDOFF_H;              // bottom of base board
DISP_TOP_Z  = DISP_SEAT_Z + DISP_THICKNESS;                            // top of base board (LCD surface)

// RJ45 (8P8C shielded jack) cutout -- same generous sizing as v0.1.
RJ45_CUT_W = 16.5;
RJ45_CUT_H = 14.0;

// Tier 1 (walled) height: floor to just above the daughterboard + enough
// margin for the RJ45 jacks' upward protrusion -- derived, not guessed, same
// lesson as v0.1 (an under-sized wall broke the RJ45 cutout through the top
// edge there). RJ45_TOP_MARGIN leaves a solid strip of wall material above
// the cutout on purpose: without it, the cutout's top face and the wall's
// top rim land exactly coincident (verified by rendering a straight top-down
// view -- the notch didn't show at all, a classic degenerate coplanar-face
// CAD case), which would print as a 0mm-thick knife edge over each RJ45 port
// at best, and is a coin-flip on floating-point rounding at worst.
RJ45_TOP_MARGIN = 2.0;
TIER1_H = DB_SEAT_Z + DB_THICKNESS + max(RJ45_CUT_H / 2 - DB_THICKNESS / 2, 3.0) + RJ45_TOP_MARGIN;

// Overall case height: Tier 1 wall + open Tier 2 standoffs + base board +
// lid clearance + lid thickness.
LID_CLEARANCE = 2.0;              // air gap above the base board before the lid's ceiling
TOTAL_H = DISP_TOP_Z + LID_CLEARANCE + LID_THICKNESS;
LID_WALL_H = TOTAL_H - TIER1_H;   // how far the lid's skirt drops to meet the Tier-1 shell

// LCD window in the lid: ES3C28P's active area is 43.20x57.60mm per the
// dimension drawing (LCD AA), centered on the base board's own center.
LCD_ACTIVE_W = 43.2;
LCD_ACTIVE_H = 57.6;

// corner standoff positions
INSET = 6.0;
DB_CORNERS = [
    [INSET, INSET], [DB_W - INSET, INSET],
    [INSET, DB_L - INSET], [DB_W - INSET, DB_L - INSET],
];
DISP_CORNERS = [
    [DISP_CX - DISP_HOLE_DX/2, DISP_CY - DISP_HOLE_DY/2],
    [DISP_CX + DISP_HOLE_DX/2, DISP_CY - DISP_HOLE_DY/2],
    [DISP_CX - DISP_HOLE_DX/2, DISP_CY + DISP_HOLE_DY/2],
    [DISP_CX + DISP_HOLE_DX/2, DISP_CY + DISP_HOLE_DY/2],
];

module rounded_rect(w, h, r) {
    hull() {
        for (dx = [r, w - r])
            for (dy = [r, h - r])
                translate([dx, dy]) circle(r = r, $fn = 32);
    }
}
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

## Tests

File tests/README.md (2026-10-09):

# Host-Unittests

Laufen auf dem PC, nicht auf dem ESP32. Sie prüfen die Byte-Logik des
Telnet/Raw-Pfads, die in `firmware/src/net.cpp` steckt, und die Akku-Kennlinie
samt Kalibrierung aus `firmware/src/bat_curve.h`.

    g++ -std=c++17 -Wall -o t iac_filter_test.cpp && ./t

    g++ -std=c++17 -Wall -o t3 bat_curve_test.cpp && ./t3

`bat_curve_test.cpp` bindet die ausgelieferte Header-Datei direkt ein.

`telnet_iac_test.cpp` erwartet die Klasse `TelnetSession` als `extracted.inc`
daneben. Erzeugen:

    python3 - <<'PY'
    src = open("../firmware/src/net.cpp").read()
    a = src.index("static const uint8_t T_IAC")
    b = src.index("static TelnetSession tcpSession[MAX_PORTS];")
    open("extracted.inc", "w").write(src[a:b].replace("static const uint8_t T_IAC", "const uint8_t T_IAC", 1))
    PY
    g++ -std=c++17 -Wall -o t2 telnet_iac_test.cpp && ./t2

So wird wirklich der ausgelieferte Code getestet und keine Kopie, die
auseinanderlaufen kann.

## Protokollcode der Leitstelle

`c2/run.sh` übersetzt `firmware/src/c2_proto.cpp` samt ML-KEM für den PC — gegen
mbedTLS 2.28, die Version des Arduino-Cores, deshalb in einem Container — und
lässt ihn gegen den echten Server aus `server/` laufen: Selbsttest mit bekannten
Antworten, Anmelden, Bestätigen, Auftrag und Ergebnis.

    tests/c2/run.sh

Braucht Docker und ArduinoJson aus einem Firmware-Build (`firmware/.pio/libdeps`).
Der erste Lauf baut zwei Images und dauert auf dem Raspberry Pi rund zehn Minuten.

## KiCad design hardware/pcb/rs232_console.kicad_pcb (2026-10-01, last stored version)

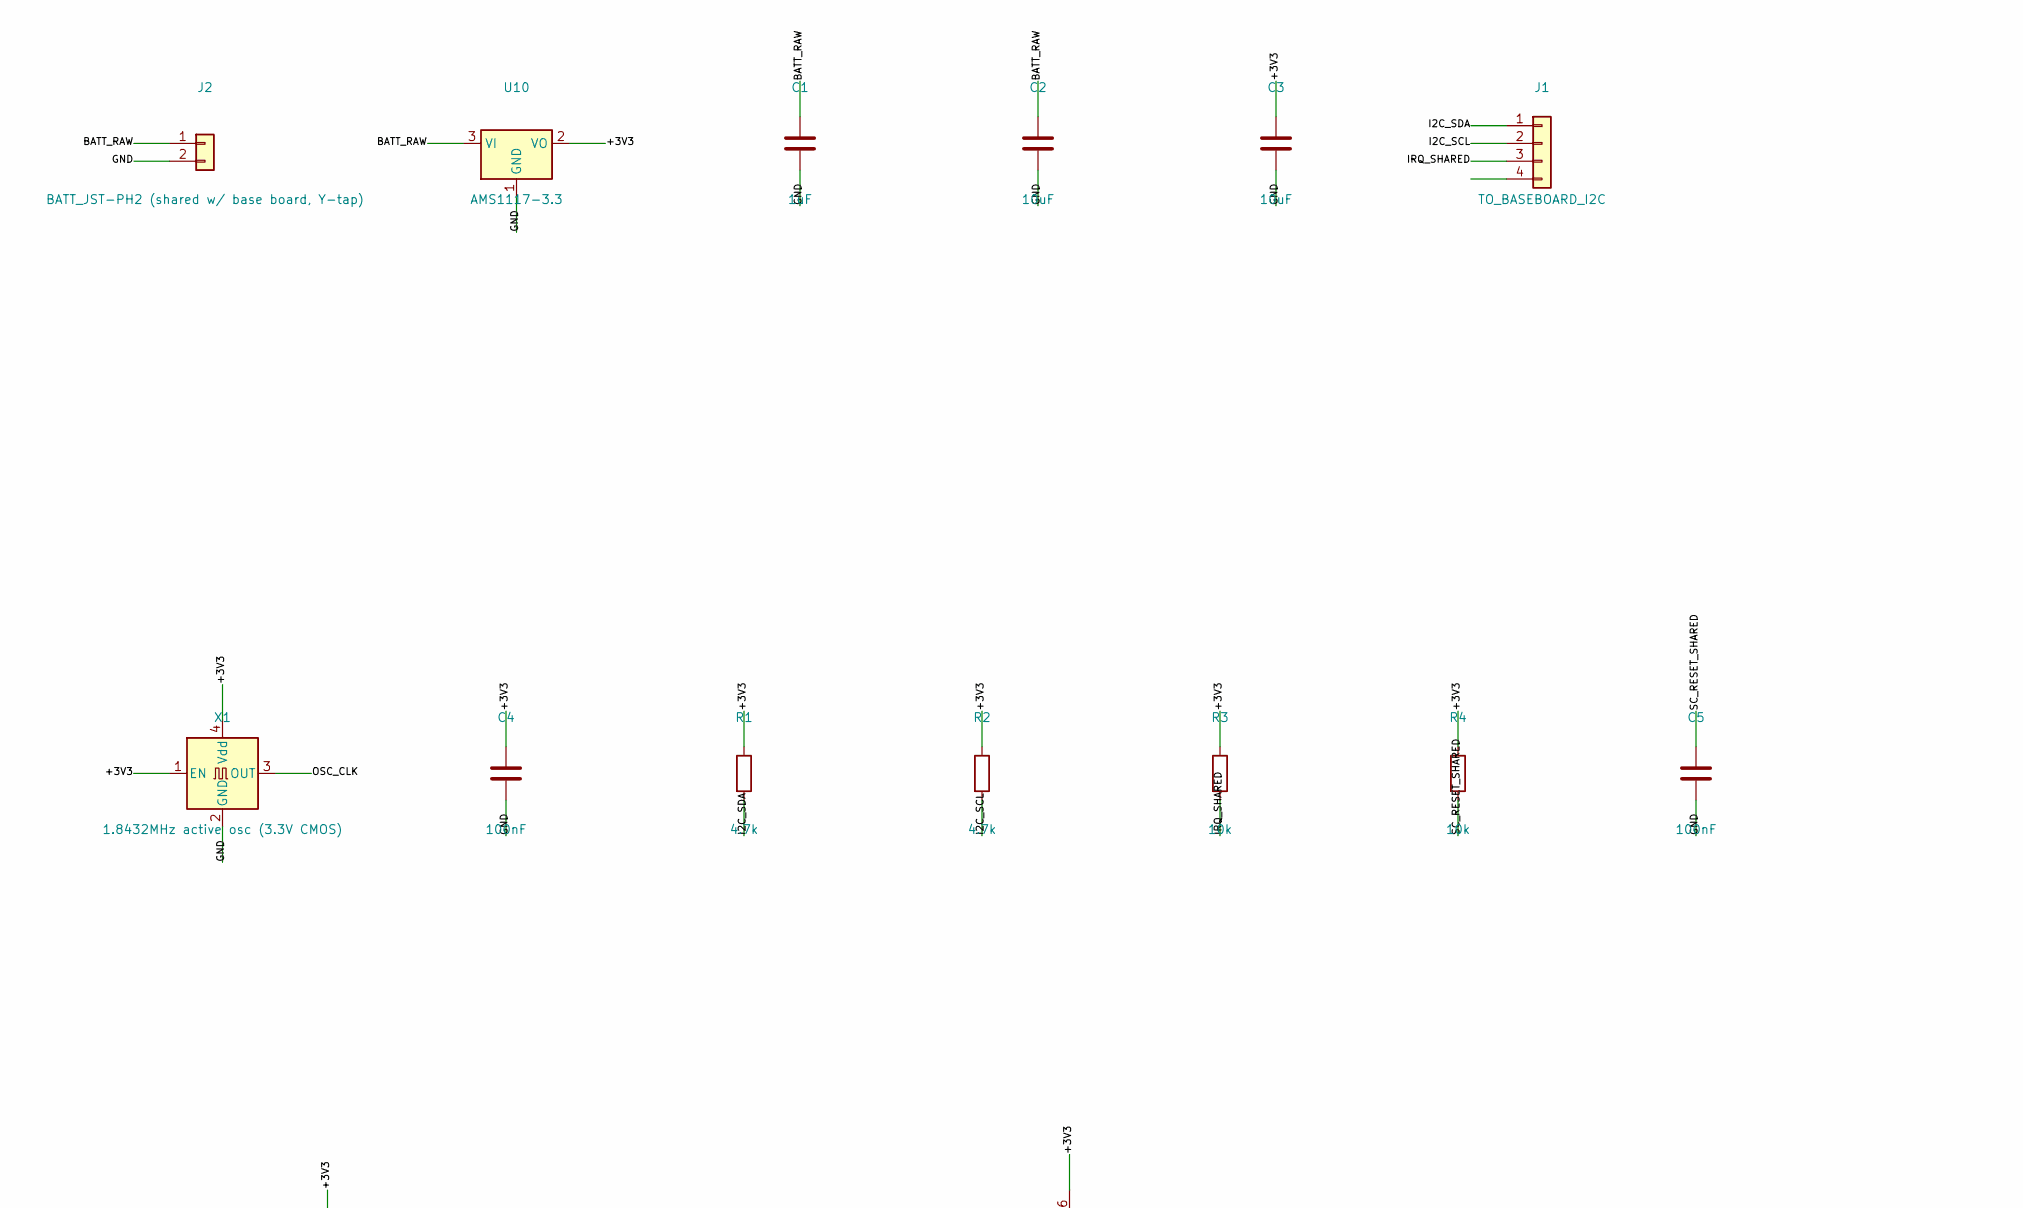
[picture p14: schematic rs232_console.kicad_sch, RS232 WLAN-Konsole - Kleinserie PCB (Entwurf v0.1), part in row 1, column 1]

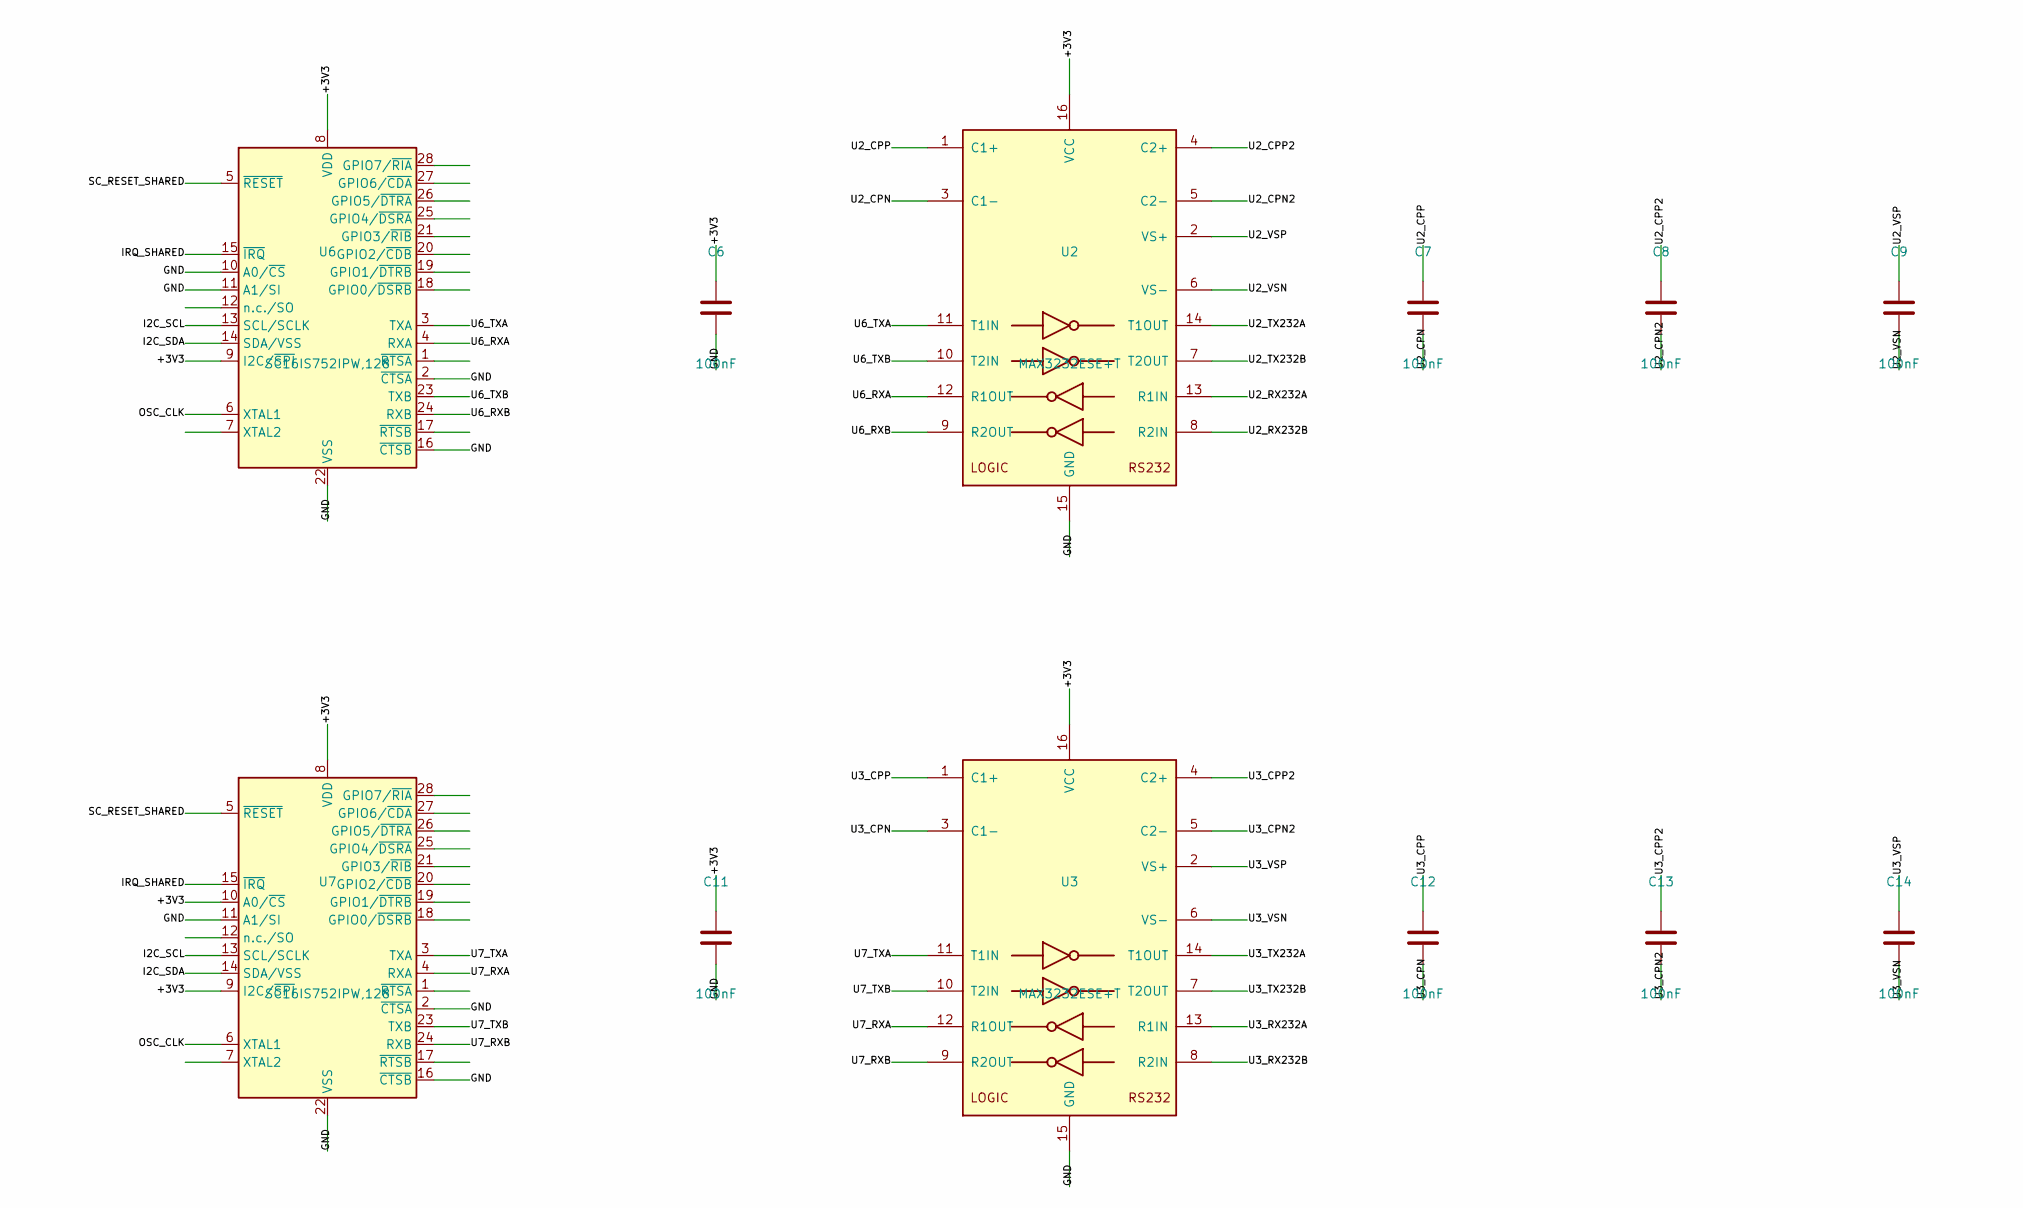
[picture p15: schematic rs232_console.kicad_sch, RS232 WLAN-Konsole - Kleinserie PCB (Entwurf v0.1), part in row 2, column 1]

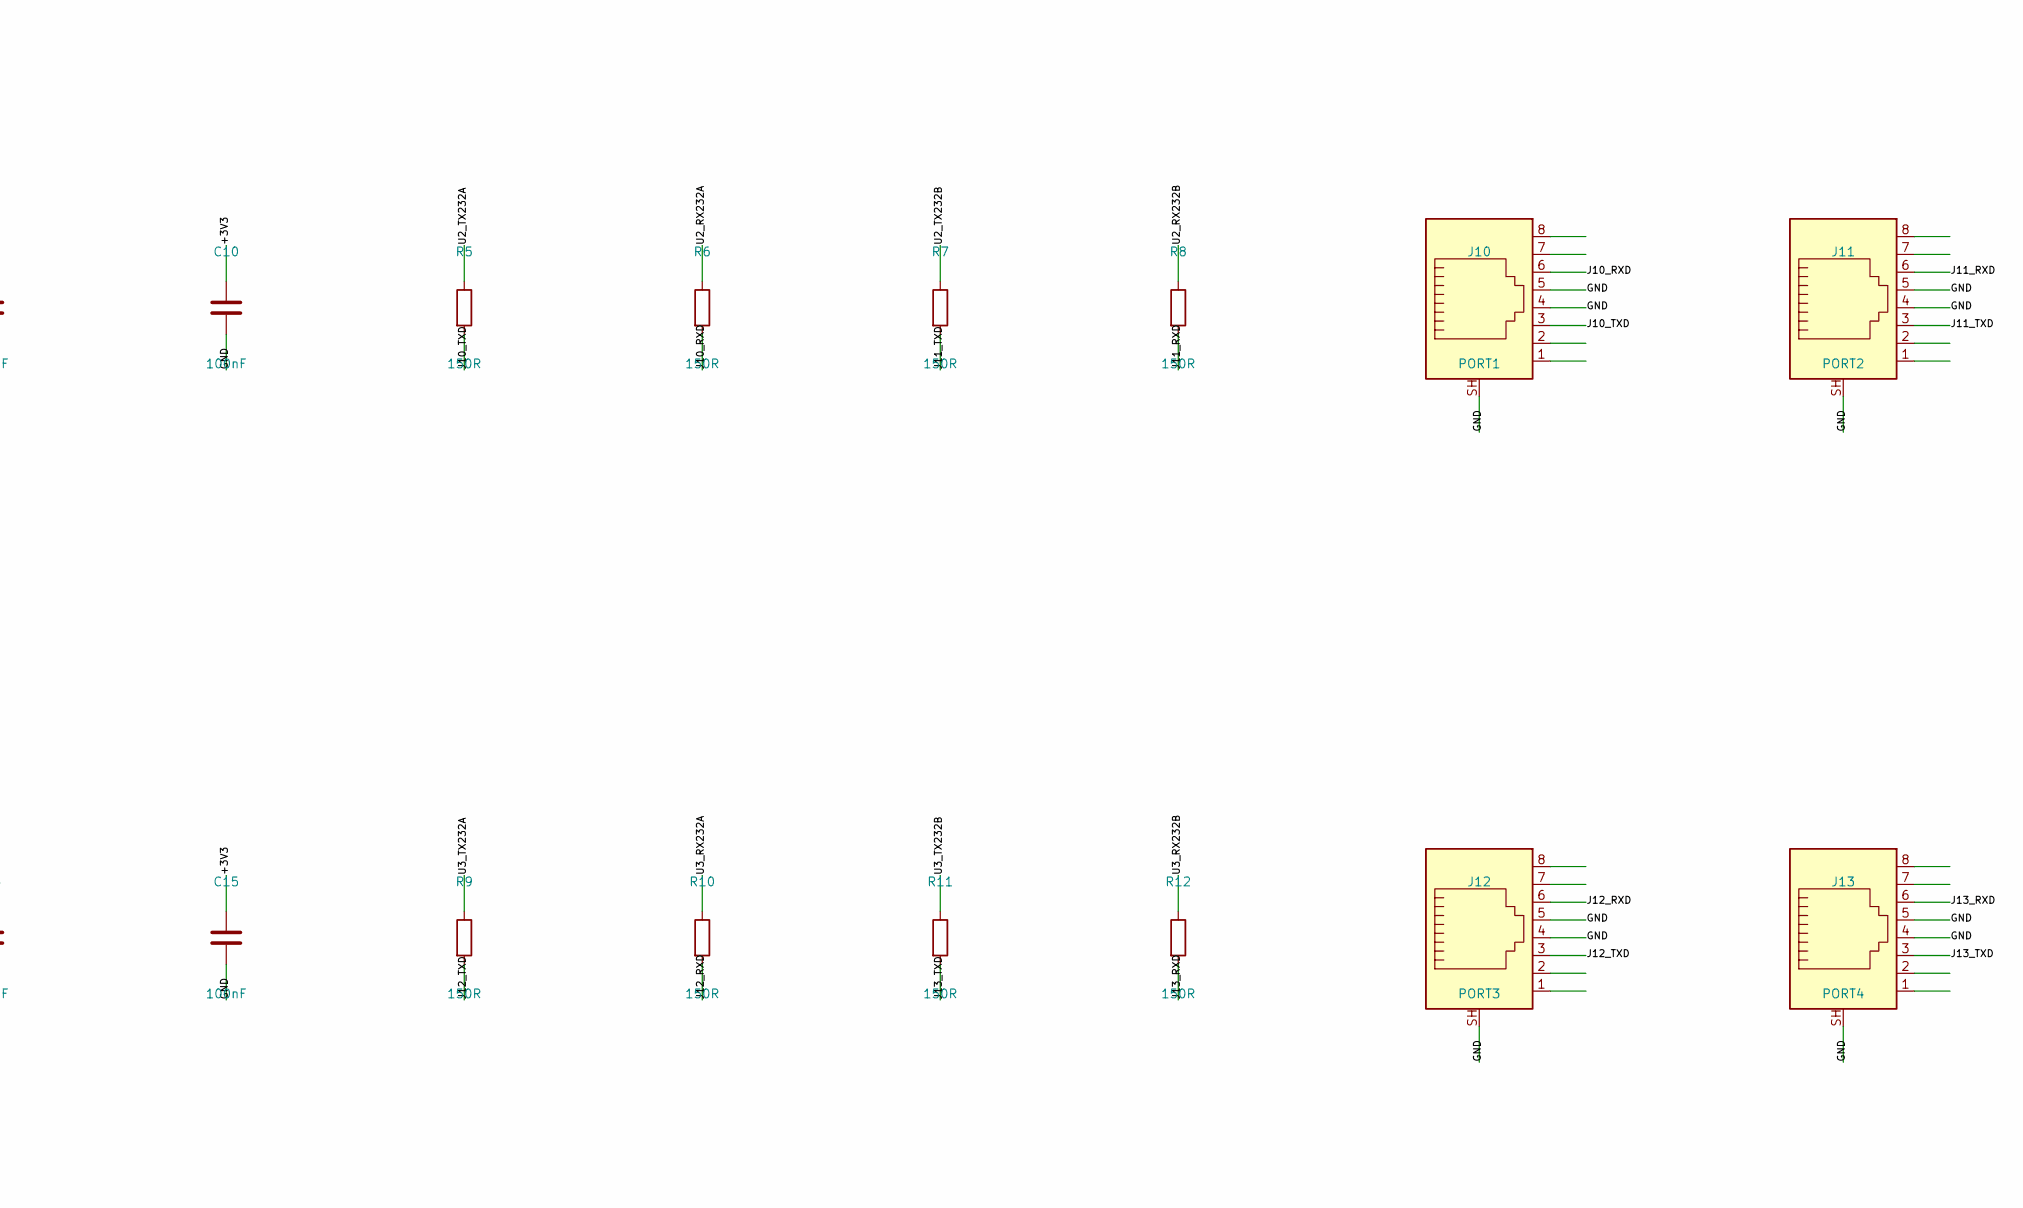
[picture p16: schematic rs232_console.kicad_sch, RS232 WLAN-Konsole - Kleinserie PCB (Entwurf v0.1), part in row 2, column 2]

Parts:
C1: 1uF; C_0805_2012Metric
C2, C3: 10uF; C_0805_2012Metric
C4, C5, C6, C7, C8, C9, C10, C11, C12, C13, C14, C15: 100nF; C_0805_2012Metric
J1: TO_BASEBOARD_I2C; JST_SH_BM04B-SRSS-TB_1x04-1MP_P1.00mm_Vertical
J2: BATT_JST-PH2 (shared w/ base board, Y-tap); PinHeader_1x02_P2.54mm_Vertical
J10: PORT1; RJ45_Amphenol_RJHSE5380
J11: PORT2; RJ45_Amphenol_RJHSE5380
J12: PORT3; RJ45_Amphenol_RJHSE5380
J13: PORT4; RJ45_Amphenol_RJHSE5380
R1, R2: 4.7k; R_0805_2012Metric
R3, R4: 10k; R_0805_2012Metric
R5, R6, R7, R8, R9, R10, R11, R12: 150R; R_0805_2012Metric
U2, U3: MAX3232ESE+T; SOIC-16_3.9x9.9mm_P1.27mm
U6, U7: SC16IS752IPW,128; TSSOP-28_4.4x9.7mm_P0.65mm
U10: AMS1117-3.3; SOT-223-3_TabPin2
X1: 1.8432MHz active osc (3.3V CMOS); Oscillator_SMD_Abracon_ASE-4Pin_3.2x2.5mm

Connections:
+3V3: C3.1, C4.1, C6.1, C10.1, C11.1, C15.1, R1.1, R2.1, R3.1, R4.1, U2.16 (VCC), U3.16 (VCC), U6.8 (VDD), U6.9 (I2C/~SPI), U7.8 (VDD), U7.9 (I2C/~SPI), U7.10 (A0/~CS), U10.2 (VO), X1.1 (EN), X1.4 (Vdd)
BATT_RAW: C1.1, C2.1, J2.1, U10.3 (VI)
GND: C1.2, C2.2, C3.2, C4.2, C5.2, C6.2, C10.2, C11.2, C15.2, J2.2, J10.4, J10.5, J10.SH, J11.4, J11.5, J11.SH, J12.4, J12.5, J12.SH, J13.4, J13.5, J13.SH, U2.15 (GND), U3.15 (GND), U6.2 (~CTSA), U6.10 (A0/~CS), U6.11 (A1/SI), U6.16 (~CTSB), U6.22 (VSS), U7.2 (~CTSA), U7.11 (A1/SI), U7.16 (~CTSB), U7.22 (VSS), U10.1 (GND), X1.2 (GND)
I2C_SCL: J1.2, R2.2, U6.13 (SCL/SCLK), U7.13 (SCL/SCLK)
I2C_SDA: J1.1, R1.2, U6.14 (SDA/VSS), U7.14 (SDA/VSS)
IRQ_SHARED: J1.3, R3.2, U6.15 (~IRQ), U7.15 (~IRQ)
J10_RXD: J10.6, R6.2
J10_TXD: J10.3, R5.2
J11_RXD: J11.6, R8.2
J11_TXD: J11.3, R7.2
J12_RXD: J12.6, R10.2
J12_TXD: J12.3, R9.2
J13_RXD: J13.6, R12.2
J13_TXD: J13.3, R11.2
OSC_CLK: U6.6 (XTAL1), U7.6 (XTAL1), X1.3 (OUT)
SC_RESET_SHARED: C5.1, R4.2, U6.5 (~RESET), U7.5 (~RESET)
U2_CPN: C7.2, U2.3 (C1-)
U2_CPN2: C8.2, U2.5 (C2-)
U2_CPP: C7.1, U2.1 (C1+)
U2_CPP2: C8.1, U2.4 (C2+)
U2_RX232A: R6.1, U2.13 (R1IN)
U2_RX232B: R8.1, U2.8 (R2IN)
U2_TX232A: R5.1, U2.14 (T1OUT)
U2_TX232B: R7.1, U2.7 (T2OUT)
U2_VSN: C9.2, U2.6 (VS-)
U2_VSP: C9.1, U2.2 (VS+)
U3_CPN: C12.2, U3.3 (C1-)
U3_CPN2: C13.2, U3.5 (C2-)
U3_CPP: C12.1, U3.1 (C1+)
U3_CPP2: C13.1, U3.4 (C2+)
U3_RX232A: R10.1, U3.13 (R1IN)
U3_RX232B: R12.1, U3.8 (R2IN)
U3_TX232A: R9.1, U3.14 (T1OUT)
U3_TX232B: R11.1, U3.7 (T2OUT)
U3_VSN: C14.2, U3.6 (VS-)
U3_VSP: C14.1, U3.2 (VS+)
U6_RXA: U2.12 (R1OUT), U6.4 (RXA)
U6_RXB: U2.9 (R2OUT), U6.24 (RXB)
U6_TXA: U2.11 (T1IN), U6.3 (TXA)
U6_TXB: U2.10 (T2IN), U6.23 (TXB)
U7_RXA: U3.12 (R1OUT), U7.4 (RXA)
U7_RXB: U3.9 (R2OUT), U7.24 (RXB)
U7_TXA: U3.11 (T1IN), U7.3 (TXA)
U7_TXB: U3.10 (T2IN), U7.23 (TXB)

Board: 2 copper layers, 39 parts (0 on the bottom side), 44 nets, no tracks yet.

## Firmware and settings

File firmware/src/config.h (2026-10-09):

#pragma once
// ============================================================================
//  RS232 Web Console - hardware + default configuration
//
//  Board: Waveshare ESP32-S3-Touch-LCD-2
// ============================================================================

#define FW_NAME     "RS232 Web Console"
#define FW_VERSION  "1.8.0"

// --------------------------------------- Waveshare ESP32-S3-Touch-LCD-2 (2", 240x320)
// ESP32-S3R8, 16 MB flash, ST7789T3 on SPI, CST816D touch, USB-C on the native
// USB port, QMI8658 accelerometer, SD slot, LiPo connector. Colour touch
// interface (lcd_ui.cpp) and a Bluetooth LE console.
#define BOARD_NAME      "Waveshare ESP32-S3-Touch-LCD-2"
#define PIN_LCD_SCLK    39  // display pins as in the LovyanGFX board configuration
#define PIN_LCD_MOSI    38
#define PIN_LCD_MISO    40
#define PIN_LCD_DC      42
#define PIN_LCD_CS      45
#define PIN_LCD_BL       1  // backlight, active high
// The panel takes 40 MHz, but the SD card hears the same clock and is specified
// up to 25 MHz. A card that stopped answering until its next power cycle is the
// open problem here (WAVESHARE.md); staying inside its limit costs nothing now
// that only changed parts of the picture are sent.
#define LCD_SPI_HZ      20000000
#define PIN_SD_CS       41  // SD slot on the LCD's SPI lines
#define PIN_SD_MOSI     PIN_LCD_MOSI
#define PIN_SD_SCLK     PIN_LCD_SCLK
#define PIN_SD_MISO     PIN_LCD_MISO
// Display rotation (0..3) for "this accelerometer axis points up"; the opposite
// direction is the rotation plus two. DEFAULT is used while the board lies flat.
#define IMU_ROT_DEFAULT  3
#define IMU_ROT_X_POS    0
#define IMU_ROT_Y_POS    1
#define PIN_KEY          0  // BOOT button (usable after start-up)
#define PIN_I2C_SDA     48  // touch (CST816D, 0x15) + accelerometer (QMI8658)
#define PIN_I2C_SCL     47

// Serial is the USB-C port, so the UART pad RXD (IO44) is free for port 1. TXD
// (IO43) is not used: it is U0TXD, and the chip's ROM prints its boot messages
// there on every reset - straight into the console of the attached device.
// Port 1 sends on IO21 instead (header pin 22): no power-up glitch, and the
// board's 4.7k pull-up keeps the line idle while the chip is in reset. IO44 can
// send as well (RX/TX swap); it stays an input during boot.
// Further header pins are left out until they are tried on the board.
#define PORT_DEFAULT_PINS {{44, 21}, {44, 21}, {44, 21}, {44, 21}}
#define PINS_RX  {21, 44}
#define PINS_TX  {21, 44}
#define PINS_ADC {5}              // battery voltage divider of the LiPo connector
#define PIN_NAMES "44:RXD,5:BAT"
#define PIN_PREFIX "IO"

#define BAT_PIN_DEFAULT   5       // BAT_ADC: divider on the board, measured against a LiPo (WAVESHARE.md)
#define BAT_TYPE_DEFAULT  0       // 0 = LiPo 1S, 1 = NiCd/NiMH 4 cells
#define BAT_DIV_DEFAULT  30       // 200k/100k
// Charger: ETA6096 on the LiPo connector, no status line to the processor (power.cpp).
#define CPU_MHZ_BATTERY  80       // clock while running from the battery (power.cpp: saver())
#define BAT_OFF_MV     3300       // on battery below this for BAT_OFF_S: switch off before the cell is drained
#define BAT_OFF_S        30
#ifndef FIXED_AP_PASS
#define FIXED_AP_PASS  "rs232mockup"
#endif
#define CPU_MHZ          240
#define TX_POWER_DEFAULT 34       // WIFI_POWER_8_5dBm: plenty for a few metres

// ---- Battery measurement ----------------------------------------------------
#define BAT_CAL          1.00f   // fine tune: real_voltage / displayed_voltage
#define BAT_LOW_PCT      10      // warning (display + web UI)

// ---- Network ------------------------------------------------------------------
#define AP_SSID_PREFIX   "RS232-"
#define AP_CHANNEL_DEFAULT 0     // 0 = auto (scan at boot, pick the quietest of 1/6/11)
#define AP_MAX_CLIENTS   4
#define DEFAULT_HOSTNAME "rs232"
#define HTTP_PORT        80
#define WS_PORT          81
#define RAW_TCP_PORT     2000     // raw TCP port 1 = 2000, port 2 = 2001 ... (PuTTY "Raw"/"Telnet", nc)
#define TCP_OUT_QUEUE    4096     // per port: bytes waiting for a congested TCP client

// ---- Serial -------------------------------------------------------------------
#define MAX_PORTS        4
#define HW_PORTS         2        // ports 1-2: hardware UART1/UART2, ports 3-4: software UART
#define SW_MAX_BAUD      38400    // software UART limit (bit timing jitter above)
#define DEFAULT_BAUD     9600     // Cisco, Fortinet, Aruba, Juniper default
#define UART_RX_BUF      4096
#define UART_TX_BUF      1024     // hardware UART driver buffer (the bridge paces its writes)
#define SW_RX_BUF        512      // software UART: received bytes
#define SW_ISR_BUF       2048     // software UART: edge timestamps (4 bytes each)
#define TX_QUEUE         4096     // per port: bytes waiting for the serial line (input is never blocking)
#define RING_SIZE        16384    // replay buffer port 1 (power of two)
#define RING_SIZE_EXTRA  8192     // replay buffer ports 2-4

// ---- File transfer (XMODEM / YMODEM) ----------------------------------------------
#define XFER_BUF         16384    // file data buffered ahead of the serial line


// ---- Diagnostics on the USB serial console -------------------------------------
#ifndef DEBUG_NET_LOG
#define DEBUG_NET_LOG    1        // 1 = also log every DNS query (captive portal)
#endif

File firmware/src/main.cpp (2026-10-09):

// ============================================================================
//  RS232 Web Console - Waveshare ESP32-S3-Touch-LCD-2
//
//  Phone/laptop  --WiFi-->  web terminal (xterm.js) / raw TCP  --> RS232 port
//
//  BOOT button (the touch display does the rest, see lcd_ui.cpp):
//    short press : wake display / next page
//    long press  : on status page -> next baud rate (9600 ... 115200)
//    hold at power-on for 5 s -> factory reset (new WiFi password)
// ============================================================================
#include <Arduino.h>
#include <WiFi.h>

#include "config.h"
#include "settings.h"
#include "serial_bridge.h"
#include "net.h"
#include "display.h"
#include "power.h"
#include "xfer.h"
#include "configs.h"
#include "certs.h"
#include "sdcard.h"
#include "ble.h"
#include "player.h"
#include "c2.h"

// Certificate parsing (PKCS#12, key check) runs in the loop task and needs more
// than the 8 kB Arduino default.
SET_LOOP_TASK_STACK_SIZE(14 * 1024);

// ------------------------------------------------------------------ buttons
struct Button {
  int pin;
  bool raw, pressed, longFired;
  uint32_t changedAt, downAt;
  explicit Button(int p) : pin(p), raw(false), pressed(false), longFired(false), changedAt(0), downAt(0) {}
};
static Button buttons[] = {Button(PIN_KEY)};

static const uint32_t BAUD_PRESETS[] = {9600, 19200, 38400, 57600, 115200};

static void onShortPress() {
  if (!Display::isOn()) {        // first press only wakes the display
    Display::wake();
    return;
  }
  Display::wake();
  Display::nextPage();
}

static void onLongPress() {
  bool wasOn = Display::isOn();
  Display::wake();
  if (!wasOn) return;
  if (Display::page() != Display::PAGE_STATUS) {
    while (Display::page() != Display::PAGE_STATUS) Display::nextPage();
    return;
  }
  const size_t n = sizeof(BAUD_PRESETS) / sizeof(BAUD_PRESETS[0]);
  size_t i = 0;
  while (i < n && BAUD_PRESETS[i] != settings.port[0].serial.baud) i++;
  SerialCfg c = settings.port[0].serial;
  c.baud = BAUD_PRESETS[i < n ? (i + 1) % n : 0];
  Bridge::apply(0, c);
  Net::markDirty();
}

static void pollButton(Button &b) {
  if (b.pin < 0) return;
  bool raw = digitalRead(b.pin) == LOW;
  uint32_t now = millis();
  if (raw != b.raw) {
    b.raw = raw;
    b.changedAt = now;
  }
  if (now - b.changedAt < 30) return;              // debounce
  if (raw && !b.pressed) {
    b.pressed = true;
    b.longFired = false;
    b.downAt = now;
  } else if (raw && b.pressed && !b.longFired && now - b.downAt > 1000) {
    b.longFired = true;
    onLongPress();
  } else if (!raw && b.pressed) {
    b.pressed = false;
    if (!b.longFired) onShortPress();
  }
}

// Hold the button while powering on -> factory reset after 5 s
static bool anyButtonDown() {
  for (auto &b : buttons)
    if (b.pin >= 0 && digitalRead(b.pin) == LOW) return true;
  return false;
}

static void checkFactoryReset() {
  // switched on with the button out of power-off: that press is not a reset request
  if (esp_reset_reason() == ESP_RST_DEEPSLEEP) return;
  if (!anyButtonDown()) return;
  uint32_t t0 = millis();
  while (anyButtonDown()) {
    uint32_t held = millis() - t0;
    if (held >= 5000) {
      Store::factoryReset();
      Certs::wipe();                   // private keys never survive a factory reset
      Display::message("Werksreset", "OK - Neustart", 2000);
      Display::loop();
      delay(2000);
      ESP.restart();
    }
    char buf[22];
    snprintf(buf, sizeof(buf), "halten: %lu s", (unsigned long)(5 - held / 1000));
    Display::message("Werksreset?", buf, 500);
    Display::loop();
    delay(50);
  }
  Display::message("Abgebrochen", "", 1000);
}

// Everything that wants to see serial data: web/TCP clients, the SD recording
// and Bluetooth. Keeping the fan-out here means the bridge stays unaware of
// which front ends exist.
static void onSerial(uint8_t port, const uint8_t *data, size_t len) {
  Net::onSerialData(port, data, len);
  Sd::write(port, data, len);
  Ble::onSerialData(port, data, len);
}

// ------------------------------------------------------------------ setup / loop
void setup() {
  setCpuFrequencyMhz(CPU_MHZ);
  Serial.begin(115200);
#if ARDUINO_USB_CDC_ON_BOOT
  // Never wait for a USB host that is not reading. Not 0: the core's write loop
  // counts this value down and wraps around at 0, which blocks for good once
  // the port is plugged into a computer but not opened - no hotspot, no display.
  Serial.setTxTimeoutMs(5);
#endif

  for (auto &b : buttons)
    if (b.pin >= 0) pinMode(b.pin, INPUT_PULLUP);

  Store::load();

  Net::prepareRadio();               // credentials (true RNG with radio on) + channel scan

  bool lcd = Display::begin();
  if (lcd) {
    Display::message(FW_NAME, "v" FW_VERSION, 1500);
    Display::loop();
  }
  checkFactoryReset();
  Sd::begin();

  Power::begin();
  Configs::begin();
  Certs::begin();
  Bridge::begin(onSerial, Net::onMessage);
  Net::begin();
  C2::begin();
  Ble::begin();

  Serial.printf("\n%s v%s (%s)\n", FW_NAME, FW_VERSION, BOARD_NAME);
  Serial.printf("LCD    : %s\n", lcd ? "ok" : "nicht gefunden");
  Serial.printf("SD     : %s\n", Sd::typeName());
  Serial.printf("WLAN   : %s  Passwort: %s\n", settings.apSsid.c_str(), settings.apPass.c_str());
  Serial.printf("Web-UI : http://%s/  (http://%s.local/)\n", Net::apIp().c_str(), settings.hostname.c_str());
  for (uint8_t p = 0; p < MAX_PORTS; p++) {
    if (!Bridge::enabled(p)) continue;
    char tcp[16];
    if (settings.tcpEnabled) snprintf(tcp, sizeof(tcp), "TCP :%u", RAW_TCP_PORT + p);
    else strlcpy(tcp, "TCP aus", sizeof(tcp));      // Menü -> Setup -> "Raw-TCP / Telnet"
    Serial.printf("Port %u : %-12s %s  RX=GPIO%d TX=GPIO%d  %s, %s\n", p + 1, Store::portName(p).c_str(),
                  Store::serialLabel(settings.port[p].serial).c_str(), Bridge::rxPin(p), Bridge::txPin(p),
                  Bridge::isHardware(p) ? "Hardware-UART" : "Software-UART", tcp);
  }
  if (settings.tcpEnabled)
    Serial.printf("Raw-TCP: %s\n", settings.tcpLan ? "Hotspot + LAN (ohne Anmeldung!)"
                                                   : "nur aus dem Hotspot-Netz");
  Serial.printf("Akku   : %s\n", Power::measured() ? Power::typeName() : "keine Messung");
  if (settings.staSsid.length())
    Serial.printf("WLAN-Client: %s (%s)\n", settings.staSsid.c_str(),
                  settings.staAuth == 0 ? "WPA2/WPA3-PSK" : "802.1X");
  if (settings.httpsEnabled) Serial.printf("HTTPS  : https://%s/\n", settings.hostname.c_str());
  Serial.printf("RAM    : %u kB frei\n", (unsigned)(ESP.getFreeHeap() / 1024));

  // a button still held from switching on (or from a cancelled factory reset) is not a key press
  for (auto &b : buttons)
    if (b.pin >= 0 && digitalRead(b.pin) == LOW) { b.raw = b.pressed = b.longFired = true; b.changedAt = b.downAt = millis(); }
}

// On battery the processor runs slower: the bridge, the web server and the
// display need a fraction of 240 MHz. The radio keeps its 80 MHz bus clock at
// either speed, so UART and SPI timing do not move. Not switched in the middle
// of a file transfer or a software-UART byte.
static void cpuClock() {
#ifdef CPU_MHZ_BATTERY
  static uint32_t last = 0;
  if (millis() - last < 1000) return;
  last = millis();
  uint32_t want = Power::saver() ? CPU_MHZ_BATTERY : CPU_MHZ;
  if (want == getCpuFrequencyMhz() || Bridge::busy() || Xfer::active()) return;
  setCpuFrequencyMhz(want);
  Serial.printf("[PWR]  CPU-Takt %u MHz (%s)\n", (unsigned)getCpuFrequencyMhz(), Power::saver() ? "Akkubetrieb" : "Netz");
#endif
}

void loop() {
  Bridge::loop();
  Xfer::loop();
  Net::loop();
  Power::loop();
  cpuClock();
  if (Power::empty()) Display::powerOff("Akku leer");
  for (auto &b : buttons) pollButton(b);
  Display::loop();
  Sd::loop();
  Ble::loop();
  Player::loop();

  // one-time low battery notice (with hysteresis)
  static bool lowNotified = false;
  if (Power::low() && !lowNotified) {
    lowNotified = true;
    Net::onMessage("Akku schwach: noch " + String(Power::pct()) + "%");
  } else if (Power::pct() > BAT_LOW_PCT + 5) {
    lowNotified = false;
  }

  if (!Bridge::busy() && !Xfer::active()) delay(1);   // software UART / transfer: no pause
  else yield();
}

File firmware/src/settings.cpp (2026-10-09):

#include "settings.h"
#include "config.h"
#include "bat_curve.h"
#include <Preferences.h>
#include <esp_mac.h>
#include <esp_random.h>

Settings settings;
static Preferences prefs;
static const char *NS = "rs232";

static String macSuffix() {
  uint8_t mac[6] = {0};
  esp_read_mac(mac, ESP_MAC_WIFI_SOFTAP);
  char buf[8];
  snprintf(buf, sizeof(buf), "%02X%02X", mac[4], mac[5]);
  return String(buf);
}

__attribute__((unused)) static String randomPassword() {
  // no 0/O, 1/l/I to make reading it off the display easy
  const char *alphabet = "abcdefghjkmnpqrstuvwxyz23456789";
  const size_t n = strlen(alphabet);
  String p;
  for (int i = 0; i < 10; i++) p += alphabet[esp_random() % n];
  return p;
}

static const int8_t DEF_PINS[MAX_PORTS][2] = PORT_DEFAULT_PINS;
static const int8_t RX_OK[] = PINS_RX;
static const int8_t TX_OK[] = PINS_TX;
static const int8_t ADC_OK[] = PINS_ADC;

template <size_t N>
static bool inList(const int8_t (&list)[N], int pin) {
  for (size_t i = 0; i < N; i++)
    if (list[i] == pin) return true;
  return false;
}

// NVS keys: port 1 keeps the keys of firmware <= 1.3 ("baud", "bits" ...)
static String key(uint8_t port, const char *k) {
  if (port == 0 && (!strcmp(k, "bd") || !strcmp(k, "bt") || !strcmp(k, "pa") || !strcmp(k, "st") || !strcmp(k, "sw"))) {
    if (!strcmp(k, "bd")) return "baud";
    if (!strcmp(k, "bt")) return "bits";
    if (!strcmp(k, "pa")) return "par";
    if (!strcmp(k, "st")) return "stop";
    return "swap";
  }
  return String("p") + port + k;
}

static void loadSerial(uint8_t i) {
  SerialCfg &c = settings.port[i].serial;
  c.baud   = prefs.getUInt(key(i, "bd").c_str(), DEFAULT_BAUD);
  c.bits   = prefs.getUChar(key(i, "bt").c_str(), 8);
  c.parity = (char)prefs.getUChar(key(i, "pa").c_str(), 'N');
  c.stop   = prefs.getUChar(key(i, "st").c_str(), 1);
  c.swap   = prefs.getBool(key(i, "sw").c_str(), false);
  if (!Store::validSerial(c)) c = SerialCfg();
}

static void putSerial(uint8_t i) {
  const SerialCfg &c = settings.port[i].serial;
  prefs.putUInt(key(i, "bd").c_str(), c.baud);
  prefs.putUChar(key(i, "bt").c_str(), c.bits);
  prefs.putUChar(key(i, "pa").c_str(), (uint8_t)c.parity);
  prefs.putUChar(key(i, "st").c_str(), c.stop);
  prefs.putBool(key(i, "sw").c_str(), c.swap);
}

namespace Store {

bool rxPinOk(int pin) { return inList(RX_OK, pin); }
bool txPinOk(int pin) { return inList(TX_OK, pin); }
bool adcPinOk(int pin) { return inList(ADC_OK, pin); }

String portName(uint8_t port) {
  if (port < MAX_PORTS && settings.port[port].name.length()) return settings.port[port].name;
  return "Port " + String(port + 1);
}

const char *checkPins(const Settings &s) {
  static char err[64];
  int8_t used[2 * MAX_PORTS + 2];
  size_t n = 0;
  if (!s.port[0].enabled) return "Port 1 muss aktiv sein";
  for (uint8_t i = 0; i < MAX_PORTS; i++) {
    const PortCfg &p = s.port[i];
    if (!p.enabled) continue;
    if (!rxPinOk(p.rx)) { snprintf(err, sizeof(err), "Port %u: RX-Pin GPIO%d nicht erlaubt", i + 1, p.rx); return err; }
    if (!txPinOk(p.tx)) { snprintf(err, sizeof(err), "Port %u: TX-Pin GPIO%d nicht erlaubt", i + 1, p.tx); return err; }
    used[n++] = p.rx;
    used[n++] = p.tx;
  }
  if (s.batPin >= 0) {
    if (!adcPinOk(s.batPin)) { snprintf(err, sizeof(err), "Akku-Pin GPIO%d kann nicht messen", s.batPin); return err; }
    used[n++] = s.batPin;
  }
  for (size_t a = 0; a < n; a++)
    for (size_t b = a + 1; b < n; b++)
      if (used[a] == used[b]) { snprintf(err, sizeof(err), "GPIO%d ist doppelt belegt", used[a]); return err; }
  if (s.batDiv < 10 || s.batDiv > 60) return "Teiler ungültig";
  return nullptr;
}
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

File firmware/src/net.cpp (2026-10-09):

#include "net.h"
#include "config.h"
#include "settings.h"
#include "serial_bridge.h"
#include "power.h"
#include "display.h"
#include "web_assets.h"
#include "captive_dns.h"
#include "xfer.h"
#include "configs.h"
#include "certs.h"
#include "https.h"
#include "c2.h"

#include <WiFi.h>
#include <WebServer.h>
#include <WebSocketsServer.h>
#include <ESPmDNS.h>
#include <Update.h>
#include <ArduinoJson.h>
#include <esp_random.h>
#include <esp_wifi.h>
#include <esp_wpa2.h>
#include <lwip/sockets.h>   // non-blocking send() for the raw TCP path

namespace Net {

// The stock (synchronous) WebServer serves one connection at a time. After
// accepting a socket it waits up to 5 s for the request - browsers (Safari on
// iPhone/iPad in particular) open spare "preconnect" sockets that never carry a
// request, and while the server waits on one of them nobody else is served.
// This drops such an idle socket as soon as another connection is waiting.
class ConsoleWebServer : public WebServer {
 public:
  explicit ConsoleWebServer(int port) : WebServer(port) {}
  void dropIdleClient() {
    if (_currentStatus != HC_WAIT_READ || millis() - _statusChange < 400) return;
    if (_currentClient.available() || !_server.hasClient()) return;
#if DEBUG_NET_LOG
    Serial.printf("[HTTP] %s: leere Verbindung verworfen (nächste wartet)\n",
                  _currentClient.remoteIP().toString().c_str());
#endif
    _currentClient.stop();
    _currentClient = WiFiClient();
    _currentStatus = HC_NONE;
  }
};

static ConsoleWebServer http(HTTP_PORT);
static WebSocketsServer ws(WS_PORT);
static WiFiServer *tcpServer[MAX_PORTS];          // raw TCP 2000 + port index
static WiFiClient tcpClient[MAX_PORTS];

// One port serves two kinds of client and tells them apart by their very first
// byte, because a telnet client always opens with option negotiation (IAC ...):
//   0xFF  -> telnet (PuTTY "Telnet", the `telnet` command). We answer the way a
//            terminal server does - "I echo, I suppress go-ahead" - which is what
//            switches off the client's local echo and its line-at-a-time mode.
//            Without that, every typed line shows up twice or with a blank line.
//   other -> raw (PuTTY "Raw", nc). Not a single byte is touched in either
//            direction, so the pipe stays 8-bit clean for binary traffic.
static const uint8_t T_IAC = 255, T_SE = 240, T_SB = 250,
                     T_WILL = 251, T_WONT = 252, T_DO = 253, T_DONT = 254,
                     T_ECHO = 1, T_SGA = 3;

class TelnetSession {
 public:
  void reset() { mode_ = UNDECIDED; state_ = 0; cmd_ = 0; rspLen_ = 0; greeted_ = false; }
  bool isTelnet() const { return mode_ == TELNET; }

  // client data -> UART: strips negotiation, keeps payload (in place)
  size_t filter(uint8_t *buf, size_t n) {
    if (!n) return 0;
    if (mode_ == UNDECIDED) mode_ = buf[0] == T_IAC ? TELNET : RAW;
    if (mode_ == RAW) return n;                        // byte for byte, untouched
    size_t out = 0;
    for (size_t i = 0; i < n; i++) {
      uint8_t b = buf[i];
      switch (state_) {
        case 0:
          if (b == T_IAC) state_ = 1; else buf[out++] = b;
          break;
        case 1:                                        // just saw IAC
          if (b == T_IAC) { buf[out++] = 0xFF; state_ = 0; }   // IAC IAC = literal 0xFF
          else if (b == T_SB) state_ = 2;
          else if (b == T_WILL || b == T_WONT || b == T_DO || b == T_DONT) { cmd_ = b; state_ = 3; }
          else state_ = 0;                             // 1-byte command (NOP, GA, AYT ...)
          break;
        case 2:                                        // inside IAC SB ... IAC SE
          if (b == T_IAC) state_ = 4;
          break;
        case 4:
          state_ = (b == T_SE) ? 0 : 2;
          break;
        default:                                       // state 3: the option byte
          answer(cmd_, b);
          state_ = 0;
          break;
      }
    }
    return out;
  }

  // what we owe the client: the opening offer plus answers to its own requests
  size_t pending(uint8_t *out, size_t max) {
    if (mode_ == TELNET && !greeted_) {
      greeted_ = true;
      put(T_IAC, T_WILL, T_ECHO);                      // "local echo off, I do it"
      put(T_IAC, T_WILL, T_SGA);                       // character at a time
    }
    size_t n = rspLen_ < max ? rspLen_ : max;
    memcpy(out, rsp_, n);
    rspLen_ = 0;
    return n;
  }

 private:
  void put(uint8_t a, uint8_t b, uint8_t c) {
    if (rspLen_ + 3 > sizeof(rsp_)) return;
    rsp_[rspLen_++] = a; rsp_[rspLen_++] = b; rsp_[rspLen_++] = c;
  }
  // decline everything we did not offer ourselves, so the client stops asking
  void answer(uint8_t cmd, uint8_t opt) {
    if (cmd == T_DO) { if (opt != T_ECHO && opt != T_SGA) put(T_IAC, T_WONT, opt); }
    else if (cmd == T_WILL) put(T_IAC, T_DONT, opt);
  }
  enum Mode : uint8_t { UNDECIDED, RAW, TELNET };
  Mode mode_ = UNDECIDED;
  uint8_t state_ = 0, cmd_ = 0;
  bool greeted_ = false;
  uint8_t rsp_[30];
  size_t rspLen_ = 0;
};
static TelnetSession tcpSession[MAX_PORTS];

// Outbound queue per port. WiFiClient::write() blocks for up to 10 s when the
// socket is congested and then silently drops whatever it could not place - on a
// weak link that is exactly "characters go missing". So nothing is handed to the
// socket directly any more: serial data lands here and tcpFlush() moves out only
// as much as lwIP accepts right now, without ever blocking the main loop.
static uint8_t *tcpOut[MAX_PORTS];
static uint16_t tcpOutHead[MAX_PORTS], tcpOutTail[MAX_PORTS];
static uint32_t tcpLostMs[MAX_PORTS];

static size_t tcpOutLen(uint8_t p) {
  return (uint16_t)(tcpOutHead[p] + TCP_OUT_QUEUE - tcpOutTail[p]) % TCP_OUT_QUEUE;
}

static void tcpQueue(uint8_t p, const uint8_t *d, size_t n) {
  if (!tcpOut[p]) return;
  for (size_t i = 0; i < n; i++) {
    uint16_t next = (tcpOutHead[p] + 1) % TCP_OUT_QUEUE;
    if (next == tcpOutTail[p]) {                       // full: say so instead of losing it quietly
      if (millis() - tcpLostMs[p] > 5000) {
        tcpLostMs[p] = millis();
        Serial.printf("[TCP]  Port %u: Sendepuffer voll, %u Byte verworfen\n", p + 1, (unsigned)(n - i));
        onMessage(Bridge::prefix(p) + "TCP-Verbindung zu langsam: " + String((unsigned)(n - i)) + " Byte verworfen");
      }
      return;
    }
    tcpOut[p][tcpOutHead[p]] = d[i];
    tcpOutHead[p] = next;
  }
}
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

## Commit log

2026-10-01 Import RS232-WLAN-Konsole v1.7.1
    Firmware (PlatformIO), Tochterplatine und Gehäuse, Diagramme,
    Host-Unittests und HANDOVER.md aus dem Archiv v1.7.1.
    Dazu README.md und CLAUDE.md als Projektgedächtnis.
    [bottom.stl, case.scad, rs232_console.kicad_pcb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]
2026-10-01 Board-Profil Waveshare ESP32-S3-Touch-LCD-2 (headless)
    Neues Env waveshare-s3-lcd2 (Core 2.0.17, 16 MB Flash). Port 1 auf
    IO44/IO43, LCD noch nicht angesteuert, Backlight aus. status_led
    verkraftet Boards ohne LED (PIN_LED < 0). Auf dem Board geflasht,
    Boot-Log und Hotspot geprüft.
2026-10-01 Waveshare ESP32-S3-Touch-LCD-2: Farb-Touch-Oberfläche, Bluetooth LE, SD
    - lcd_ui.cpp: eigene Oberfläche auf dem 2"-LCD (LovyanGFX) mit sechs
    Seiten, Live-Terminal, Tasten für Baud/Auto-Baud/BREAK, automatischem
    Drehen und Wecken über den QMI8658
    - ble.cpp: serielle Konsole über Nordic UART Service für Port 1, nur
    nach Kopplung mit der PIN vom Display
    - SD-Karte am SPI-Bus des LCD, Mitschnitt über die REC-Taste
    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
2026-10-01 Waveshare-Display: eigener UI-Task, Teil-Updates, Debug-Konsole, SD-Diagnose
    Die Oberfläche lief in der Hauptschleife und schickte viermal pro
    Sekunde das ganze Bild. Jetzt:
    - UI-Task auf Core 0 zeichnet aus einem Schnappschuss und sendet nur
    geänderte 16-Pixel-Streifen; die Hauptschleife pausiert im Betrieb
    2-3 ms. Befehle laufen über eine Warteschlange zurück.
    - Fehler behoben: Display schaltete bei jeder Berührung ab (Überlauf im
    Zeitvergleich); eine Berührung zerfiel in mehrere Taps; usedBytes()
    pro Bild fror die Anzeige ein, sobald eine Karte eingebunden war.
    - Debug-Konsole am USB-Seriell-Port mit tools/lcd_debug.py: Status
    beider Tasks, Screenshot, simulierte Taps, D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
    [config.h, lcd_debug.py, lcd_ui.cpp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]
2026-10-02 Waveshare-Display: Seiten System, Skripte und Setup; Blockade ohne USB-Leser behoben
    - main.cpp: Serial.setTxTimeoutMs(0) blockierte, sobald das Board an
    einem Rechner steckte, der den Port nicht geöffnet hat (Überlauf in
    der Schreibschleife der USB-Klasse): kein Hotspot, kein Bluetooth,
    eingefrorene Anzeige. Jetzt 5 ms. Gilt für alle USB-CDC-Boards.
    - net.cpp/ble.cpp: Modem-Sleep an, wenn Bluetooth läuft - sonst bricht
    der WLAN-Treiber ab, sobald die Station startet.
    - player.cpp: gespeicherte Konfigurationen vom Gerät aus abspielen
    (Prompt abwarten, --More--, Fehlerstopp, @pause/@expect/@break/@timeout).
    - lcd_ui.cpp: Seite System (CPU-Last je Kern, RAM, PSRAM, Takt,
    Tempe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
    [ble.cpp, lcd_debug.py, lcd_ui.cpp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]
2026-10-06 Waveshare-Display: Akkuanzeige mit Ladeerkennung
    Akkumessung an IO5 am Gerät bestätigt und voreingestellt. Der ETA6096 hat
    keine Statusleitung, deshalb wird das Laden aus USB-Frames eines Rechners
    und aus der Akkuspannung geschlossen. Akkusymbol mit Blitz im Kopf,
    laedt/voll in der Akku-Zeile, ⚡ in der Weboberfläche, lcd_debug.py bat.
    Ungeprüft: Akkubetrieb, Netzteil, Ab-/Anstecken.
2026-10-06 Waveshare-Display: Stromsparen, Ausschalten, Scrollen, größere Tasten; Port 1 TX auf IO21
    - Akkubetrieb: CPU-Takt 80 MHz, Hintergrundlicht dunkelt nach 15 s ab,
    dunkles Display fragt seltener ab, Abschalten unter 3,3 V
    - Setup -> Ausschalten: Tiefschlaf, BOOT-Taste schaltet wieder ein
    - Seiten scrollen per Ziehen, lange Werte brechen um, einzeilige Texte laufen
    - Tasten 46 px hoch, bei Platzmangel zweireihig; Listenzeilen 32 px
    - Port 1 sendet auf IO21 statt IO43 (ROM-Startmeldungen auf U0TXD)
    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
2026-10-07 Waveshare ESP32-S3-Touch-LCD-2: Wiki-Link und Herstellerbilder
    info.md verweist auf das Wiki mit Schaltplan und Demo-Archiv; die drei
    Bilder zeigen Maße, Bestückung und die Belegung der Stiftleisten.
2026-10-07 Akku-Anzeige kalibrieren: 0-%- und 100-%-Punkt einstellbar
    - Kennlinie und Kalibrierung in src/bat_curve.h (ohne Arduino), die
    Kennlinie wird zwischen die beiden gemessenen Punkte gespannt
    - Weboberfläche: Ports -> "Akku-Anzeige kalibrieren", POST /api/batcal,
    wirkt ohne Neustart
    - Touch-Display: Setup -> "Jetzt voll" / "Jetzt leer" /
    "Kalibrierung loeschen", jeweils mit Rückfrage
    - Debug-Konsole und lcd_debug.py: batcal full | empty | reset | E F
    - Geändert wird nur die Prozentzahl; Spannung, Ladeerkennung und
    Abschalten bei 3,3 V rechnen weiter mit dem Messwert
    - Anderer Akkutyp, Mess-Pin oder Teiler löscht die Kalibrierung
    Host-Test tests/bat_curve_test.cpp; am Waveshare per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
    [lcd_debug.py, lcd_ui.cpp, net.cpp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]
2026-10-09 Aufräumen auf ein Board: nur noch Waveshare ESP32-S3-Touch-LCD-2
    DevKit-Mockup (OLED), LilyGO T-RSS3 und VIEWE-5"-Panel entfernt, dazu
    OLED-Treiber (U8g2), LVGL-GUI, Status-LED, fertige Images, MOCKUP.md,
    PANEL.md, T-RSS3-Gehäuse und die zugehörigen Diagramme. Die HAS_*-Schalter
    und ihre toten Zweige sind aufgelöst; config.h enthält ein Profil.
    Web-API: oledFlip/oledBrightness heißen displayFlip/displayBrightness
    (NVS-Schlüssel unverändert), OLED-Typ und LED-Helligkeit entfallen.
    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
    [rs232_console_body_standardmasse.stl, rs232_console_case.scad, rs232_console_lid_standardmasse.stl]
2026-10-09 Core-3-Kompatibilität und LBO-Warnleitung entfernt
    compat_eap.h und compat_mbedtls.h entfallen: Zertifikats- und HTTPS-Code
    rufen mbedTLS 2 direkt auf, 802.1X die esp_wifi_sta_wpa2_ent_*-Namen von
    Arduino-Core 2.0.17. Die Einstellung batLbo samt Auswertung und Auswahl
    in der Weboberfläche ist gestrichen; "Akku schwach" ist nur noch die
    Prozentschwelle.
2026-10-09 hardware/ und diagramme/ entfernt
    KiCad-Projekt der I²C-Tochterplatine, Gehäuse fürs LCDwiki-Basisboard und
    die Zeichnungen zum DevKit-Mockup (PowerBoost, DB9-Nullmodem) gehören zu
    Aufbauten, die es nicht mehr gibt. Dokumente und offene Punkte angepasst;
    letzter Stand mit diesen Dateien: 43e7939.
    [bottom.stl, case.scad, rs232_console.kicad_pcb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]
2026-10-09 Leitstelle Phase 1: Server-Kern, Protokoll, Gerätesimulator, Docker
    Neuer Ordner server/: Command-and-Control-Server in Go (nur
    Standardbibliothek). Geräte melden sich ausgehend per HTTPS; darin ein
    hybrider Kanal aus X25519 und ML-KEM-768, Echtheit allein über
    Schlüsselkapselung. Registrierung mit einmaligem Einladungs-Token und
    sechsstelligem Code vom Gerätedisplay, Auftragswarteschlange, Admin-API.
    Konzept, Protokoll und Phasen in server/KONZEPT.md. 19 Unit-Tests und
    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
2026-10-09 Leitstelle Phase 2: Client in der Firmware
    Das Gerät meldet sich über den WLAN-Client bei der Leitstelle an: Token
    in der Weboberfläche (Menü -> Netz -> Leitstelle) oder per /api/c2/enroll,
    sechsstelliger Code auf dem Display (Seite Info) und in der Weboberfläche,
    danach Abfragen im Takt des Servers und die Aufträge ping und status.
    - src/c2_proto.*: Geräteseite des Protokolls (X25519, HMAC, AES-GCM aus
    mbedTLS 2.28; ML-KEM-768 aus mlkem-native v1.0.0 in lib/mlkem_native),
    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
2026-10-11 Leitstelle Phase 3: Aufträge und Admin-Weboberfläche
    Server: Admin-Weboberfläche (eingebettet, mit QR-Code für die Einladung),
    Aufträge status/settings/configs/play/reboot mit Prüfung der Argumente,
    Verfall nicht abgeholter und nicht beantworteter Aufträge, Zustandsdatei
    wird nicht mehr bei jeder Abfrage geschrieben. Browsertest test/ui.sh.
    Firmware: Aufträge laufen in der Hauptschleife; play und reboot nur mit
    dem Haken in der Weboberfläche des Geräts (settings.c2Control, Vorgabe aus).
    Einladung per Link (#c2=<Token>).
    Firmware-Update über die Leitstelle bewusst nicht enthalten (erst mit
    Signaturprüfung).
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2026-10-11 Leitstelle Phase 5, erster Teil: Konten, Entra, Protokoll, Anfragerate
    Konten statt des einen Admin-Tokens: Ein Administrator legt ein Konto an,
    der Besitzer richtet es mit einem Einrichtungscode ein (Passwort,
    PBKDF2-HMAC-SHA256; Authenticator-App, TOTP nach RFC 6238) und meldet sich
    mit Name, Passwort und Code an. Sitzungen als Cookie (HttpOnly, Secure,
    SameSite=Strict), 30 Minuten Ruhe, höchstens 12 Stunden; verändernde
    Aufrufe brauchen den Kopf X-C2. Sperre nach fünf Fehlversuchen.
    Anmeldung über Microsoft Entra ID (OpenID Connect mit PKCE, ID-Token hier
    geprüft): Entra sagt, wer jemand ist, ein Konto der Art "entra" entscheidet,
    ob er Administrator ist. Nur gegen einen nachgebaute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
2026-10-13 Leitstelle: signiertes Firmware-Update, Bibliothek mit Vorlagen und Images, Standorte; USB-Stick-Modus; Oberflächen aufgeräumt
    Firmware-Update über die Leitstelle (KONZEPT.md §4.7): Pakete werden auf dem
    Rechner des Besitzers mit ML-DSA-65 signiert (tools/fw_sign.py, der Schlüssel
    bleibt dort), der Server ist Regal und Bote, das Gerät prüft Signatur, Board,
    Größe, Hash und dass das Paket neuer ist (c2_update.cpp, mldsa-native in
    lib/mldsa_native). Auftrag "update", nur mit Freigabe am Gerät.
    Behoben: Der Schlüsseltausch braucht 28 kB Heap am Stück; Puffer, die über
    big() hinweg leben, kommen jetzt aus dem externen RAM (ext() in c2.cpp).
    Vorher bekam das Board nach etwa jedem zw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
2026-10-16 Leitstelle Phase 5: Kopie woanders, Wächter von außen, Test in WebKit
    - server/offsite-backup.sh: holt den Datenordner per SSH, prüft state.json,
    verschlüsselt (CMS, AES-256-GCM) an ein Zertifikat, 14 Kopien, Images gespiegelt;
    systemd-Dienst und -Timer, Meldung über ntfy bei Fehlern
    - server/watchdog.sh: /healthz und Restlaufzeit des Zertifikats alle 2 min,
    Push über ntfy nach zwei Fehlschlägen, Erinnerung, Entwarnung
    - ui.sh läuft auch in WebKit (UI_BROWSER=webkit); Wettlauf beim Wechsel des
    Profils im Einladungsdialog behoben (inviteSeq)
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2026-10-18 Firmware: Bridge prüft den UART und öffnet einen hängenden Port neu (Issue #12)
    - Port 1 hörte am 18. Oktober 2026 zweimal stundenlang nichts vom Switch; dasselbe
    Öffnen mit denselben Einstellungen brachte die Antwort sofort
    - check() in serial_bridge.cpp alle 0,5 s: Daten im FIFO, die der Treiber nicht nimmt,
    Empfangs-Interrupt aus, Sender wird nicht fertig, Pins nicht am UART, Baudrate
    verstellt; zuletzt gesendet und 5 s nichts zurück
    - Grund im Log und in /api/status (rxReopen, rxWhy); am Board geprüft, vom Besitzer
    über die Fernkonsole samt Skript bestätigt
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2026-10-19 Firmware: Bridge sendet nach 36 min Stille nicht mehr – Überlauf von micros() (Issue #13, Ursache von #12)
    drain() verglich busyUntilUs, einen 32-Bit-Stempel von micros(), als
    vorzeichenbehaftete Differenz. War der Port 36 bis 71,6 Minuten still,
    sah der alte Stempel aus wie Zukunft, und nichts ging mehr an den UART:
    Getipptes stand in der Warteschlange, der Switch antwortete nicht.
    Jetzt nimmt busyAhead() einen Stempel in der Vergangenheit oder mehr als
    5 s voraus als veraltet; neue Regel der Selbstprüfung „Sendewarteschlange
    steht“; txq je Port in /api/status. Am Board geprüft: 41 min nichts
    gesendet, danach antwortet der Switch sofort, ohne Neuöffnen.
    Fixes #13
    Fixes #12
    Co-Au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
2026-10-30 Firmware: Stick-Modus wiederholt verweigerte Kartenzugriffe statt Daten zu verlieren
    Die Karte verweigert auf dem geteilten Bus regelmäßig ein Schreiben. Im
    Stick-Modus ging das als Fehler an den Rechner, Linux verwarf die Seite
    ("lost async page write"), und ein 25-MB-Image kam viermal kaputt an.
    stickIo() versucht jede Anfrage bis zu fünfmal, mit freigegebenem Bus
    dazwischen; /api/status zählt retries und fails unter stick.
    Geprüft am Board: 4 × 25 MB geschrieben und zurückgelesen, alle MD5 gleich,
    4 Wiederholungen, 0 Fehler.
    Doku: Der C2960CX nimmt das Board seit der Geräteklasse 0/0/0 an
    (usbflash0 inserted), meldete aber "Invalid DOS media" – auf der Karte lag
    ein Raspberry-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
2026-10-30 Firmware: Stick-Modus zeigt große Karten als 4-GB-Stick, wenn ihre Partitionen hineinpassen
    Ein Cisco C2960CX rechnet die Größe eines Sticks in Byte mit 32 Bit: Die
    32-GB-Karte sah er als 1856 MB, fand die Partitionstabelle "unexpected"
    und konnte sie auch nicht formatieren ("Didn't find 55AA signature").
    stickSize() zeigt eine Karte über 4 GB als 8 386 560 Sektoren, wenn alle
    Partitionen darin liegen; sonst die ganze Karte. /api/status nennt sizeMb.
    Die Karte im Board hat jetzt eine FAT32-Partition knapp unter 4 GiB. Am
    Laptop geprüft (4 GB gesehen, Dateien lesbar, alle MD5 gleich), am Switch
    noch nicht.
2026-10-30 Firmware: Stick-Modus beantwortet SCSI selbst – der Core meldete unbekannte Befehle als erledigt
    In tud_msc_scsi_cb des Arduino-Cores 2.0.17 ist die Antwortlänge ein
    uint16_t: "-1 = nicht unterstützt" wurde zu 65535, auf die Puffergröße
    gekürzt und als Erfolg gemeldet. Linux nutzt nur Befehle, die TinyUSB
    selbst kennt; ein Cisco C2960CX schickt andere, bekam für Lesen einen
    alten Pufferinhalt und für Schreiben ein "erledigt" ohne Schreiben – im
    Sektor 0 stand danach Müll mit seiner Partition darin ("Didn't find 55AA
    signature in System Sector").
    Die MSC-Rückrufe stehen jetzt in sdcard.cpp (statt USBMSC): unbekannte
    Befehle bekommen ILLEGAL REQUEST, READ(6)/WRITE(6) bis 8 Sektor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
2026-10-30 Firmware: Sendeleitung bleibt bei Neustart, Update und Ausschalten in Ruhe; Stick-Modus mit Mitschnitt
    Kein BREAK an das angeschlossene Gerät: Vor jedem Neustart (Update,
    reboot, Einstellungen, auch Absturz und Watchdog über
    -Wl,--wrap=esp_restart_noos), beim Neuöffnen eines Ports und beim
    Ausschalten wird jeder Sendepin auf GPIO-Ausgang high gelegt und mit dem
    Pad-Hold festgehalten, losgelassen erst, wenn der UART die Leitung wieder
    treibt. Der Hold überlebt den Neustart selbst nicht (gemessen); ab dem
    Reset trägt der Pull-up des Pins (GPIO44 und GPIO21 lesen beim Start
    high, txHold in /api/status). Geprüft: 8 Neustarts und Updates mit der
    Konsole eines C2960CX am Port, Switch blieb o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
2026-11-07 Firmware: Port-2-Pins GPIO15/13 für die RS232-Console-HAT freigegeben
    PINS_RX/PINS_TX um 15 und 13 erweitert, damit der zweite Port der
    aufgesteckten RS232-Console-HAT (Trägerplatine, J3: RX2->GPIO15,
    TX2->GPIO13) nutzbar ist; vorher wies applySettings die Pins ab
    ("RX-Pin GPIO15 nicht erlaubt", HTTP 400). PIN_NAMES um 21/15/13 ergänzt.
    Am Waveshare-Board (deutsche Firmware, OTA über /update) gegen einen
    Cisco-Switch geprüft: beide Ports, 9600 8N1, Prompt in beiden Richtungen
    (Port 1 rx44/tx21 per swap, Port 2 rx15/tx13).
    Claude-Session: https://claude.ai/code/session_01NzB9JbxZgUgb8e5216uWVc
2026-11-14 Firmware: USB-Port tot außerhalb des Stick-Modus, eigener Bootloader, Antworttakt im Stick-Modus
    Cisco C2960CX (IOS 15.2(7)E5), am echten Switch nachgewiesen:
    Absturz: Die Serial/JTAG-Einheit des Chips beantwortet Textanfragen, die sie
    nicht hat, mit nichts oder ROM-Resten statt mit STALL; IOS überschreibt
    daraufhin seinen Heap. Mit eingeschalteter Debug-Konsole stürzte der Switch in
    einer Nacht 100-mal ab (crashinfo_ext_10..109), mit totem Port nicht.
    - Sd::usbStart(): Der Port gehört außerhalb des Stick-Modus dem nicht
    gestarteten OTG-Controller (kein Pull-up, kein Gerät). Die Debug-Konsole
    gibt es nur mit settings.usbDebug (POST /api/usbdebug, startet neu), nie über
    `set` de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
2026-11-14 Firmware: SD-Verlauf in /api/status; Stand der Karte und des Switches dokumentiert
    - /api/status nennt sdLog: den gespeicherten Verlauf der letzten Starts mit
    der Karte (K/R Start, + eingebunden, -xx Antwort auf CMD0). Bisher stand
    er nur an der Debug-Konsole, und die darf nicht an, solange das Board am
    Switch steckt.
    - Stand 14. November 2026: Das Board sieht keine SD-Karte - auf jeden Start
    antwortet der Steckplatz mit FF, auch nach einem Einschalten (nicht
    gesteckt, nicht eingerastet oder defekt). Die Karte ist deshalb mit dem
    neuen Antworttakt noch nicht am Switch geprüft.
    - Die 109 Absturzdateien auf dem Switch (flash:crashinfo_ext/) sind
    gelöscht, wieder 81 MB frei; der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
